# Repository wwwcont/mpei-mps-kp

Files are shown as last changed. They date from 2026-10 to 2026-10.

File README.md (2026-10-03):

# Результаты генератора

Ветка обновляется автоматически (джобы КМ-1/2/3). Руками не править. Исходники — ветка `main`.

Папка студента — `<группа>/<M> <Фамилия И.О.>/`: `СХЕМА-N` (КМ-1), `ПЗ1-K по СХЕМА-N` (КМ-2),
`ПЗ2-K по СХЕМА-N` (КМ-3: ПЗ2 и программы). Прошлые прогоны не перетираются. В таблице — последние.
Пробы вариантов (не сдача) — в `_пробы/`.

| Группа | Вариант, студент | КМ-1: схема | Перечень | ERC | КМ-2: ПЗ1 | КМ-3: ПЗ2 | КМ-3: программы |
| --- | --- | --- | --- | --- | --- | --- | --- |
| А-09-23 | 3 Друговская Е.М. | [СХЕМА-1](А-09-23/3%20Друговская%20Е.М./СХЕМА-1): [PNG](А-09-23/3%20Друговская%20Е.М./СХЕМА-1/schematic.png) · [PDF](А-09-23/3%20Друговская%20Е.М./СХЕМА-1/schematic.pdf) · [KiCad](А-09-23/3%20Друговская%20Е.М./СХЕМА-1/schematic.kicad_sch) | [ПЭ3](А-09-23/3%20Друговская%20Е.М./СХЕМА-1/perechen.pdf) · [КМ-1](А-09-23/3%20Друговская%20Е.М./СХЕМА-1/perechen-km1.pdf) | чисто | — | — | — |
| А-12-23 | 8 Казарин А.А. | [СХЕМА-1](А-12-23/8%20Казарин%20А.А./СХЕМА-1): [PNG](А-12-23/8%20Казарин%20А.А./СХЕМА-1/schematic.png) · [PDF](А-12-23/8%20Казарин%20А.А./СХЕМА-1/schematic.pdf) · [KiCad](А-12-23/8%20Казарин%20А.А./СХЕМА-1/schematic.kicad_sch) | [ПЭ3](А-12-23/8%20Казарин%20А.А./СХЕМА-1/perechen.pdf) · [КМ-1](А-12-23/8%20Казарин%20А.А./СХЕМА-1/perechen-km1.pdf) | чисто | [ПЗ1-2 по СХЕМА-1](А-12-23/8%20Казарин%20А.А./ПЗ1-2%20по%20СХЕМА-1/Казарин%20АА%20ПЗ1-v1.docx) | [ПЗ2-1 по СХЕМА-1](А-12-23/8%20Казарин%20А.А./ПЗ2-1%20по%20СХЕМА-1/Казарин%20АА%20ПЗ2-v1.docx) | [отчёт](А-12-23/8%20Казарин%20А.А./ПЗ2-1%20по%20СХЕМА-1/программы/report.md) |
| А-12-23 | 14 Студентов С.С. | [СХЕМА-1](А-12-23/14%20Студентов%20С.С./СХЕМА-1): [PNG](А-12-23/14%20Студентов%20С.С./СХЕМА-1/schematic.png) · [PDF](А-12-23/14%20Студентов%20С.С./СХЕМА-1/schematic.pdf) · [KiCad](А-12-23/14%20Студентов%20С.С./СХЕМА-1/schematic.kicad_sch) | [ПЭ3](А-12-23/14%20Студентов%20С.С./СХЕМА-1/perechen.pdf) · [КМ-1](А-12-23/14%20Студентов%20С.С./СХЕМА-1/perechen-km1.pdf) | чисто | — | — | — |
| А-12-23 | 17 Рязанцев И.В. | [СХЕМА-1](А-12-23/17%20Рязанцев%20И.В./СХЕМА-1): [PNG](А-12-23/17%20Рязанцев%20И.В./СХЕМА-1/schematic.png) · [PDF](А-12-23/17%20Рязанцев%20И.В./СХЕМА-1/schematic.pdf) · [KiCad](А-12-23/17%20Рязанцев%20И.В./СХЕМА-1/schematic.kicad_sch) | [ПЭ3](А-12-23/17%20Рязанцев%20И.В./СХЕМА-1/perechen.pdf) · [КМ-1](А-12-23/17%20Рязанцев%20И.В./СХЕМА-1/perechen-km1.pdf) | чисто | [ПЗ1-1 по СХЕМА-1](А-12-23/17%20Рязанцев%20И.В./ПЗ1-1%20по%20СХЕМА-1/Рязанцев%20ИВ%20ПЗ1-v1.docx) | [ПЗ2-1 по СХЕМА-1](А-12-23/17%20Рязанцев%20И.В./ПЗ2-1%20по%20СХЕМА-1/Рязанцев%20ИВ%20ПЗ2-v1.docx) | [отчёт](А-12-23/17%20Рязанцев%20И.В./ПЗ2-1%20по%20СХЕМА-1/программы/report.md) |

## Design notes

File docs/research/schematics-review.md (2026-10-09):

# Разбор схем Э3 прошлых лет и решения для мастера

> **ТЗ-2026:** CS теперь через дешифратор 74HC138, фильтры 33 н, у IDT7005 A0–A12, индикатор по группе — см. `tz-2026.md`. Остальное в силе.

Собрано 2026-09-30 из `docs/prev/` (локально) + `docs/group/` + даташитов. Сводка трёх разборов:
схемы по узлам, KiCad-библиотеки, даташиты IDT7005 / AT89S53 / FYS-5612.

## Кто что рисовал

- **Шаблон 2025 (наше ТЗ)**: Осипова вар. 12 (ПРИНЯТО 28.10.25, `mailru-group/Защита/`), Аристов вар. 1, Иванова вар. 7,
  ММС вар. 11, старая схема Ивана вар. 14 (принята без замечаний). Одна топология.
- **Прошлые годы** (другое ТЗ: АЦП/SPI, UART, LED, 2 разряда, 16 клавиш, внешнее устройство буфер ЧИТАЕТ):
  Сорокина, Женюх, Козлова, Базарнов (= Хромочкина), Балашов/Кретов, Гайворонский, Сапрыкин, Егоров. Мерсов, Рыженков — совсем другое.

## Решения по узлам

| Узел | Решение | Почему |
|---|---|---|
| RST | C 10 мкФ VCC→RST, R 10 кОм RST→GND (τ≈100 мс), кнопка — опционально через 100–220 Ом | В шаблоне 2025 только R на GND → нет POR. Классика у Ивановой, Базарнова |
| Кварц | ZQ1 12 МГц, C 30 пФ ×2, примечание «вблизи ZQ1» | даташит |
| EA/PSEN | EA→VCC, PSEN — NC | Балашов/Гайворонский: EA висит — грубо |
| Защёлка | 74AC573 (или КР1554ИР22 = 74AC373 — **другая цоколёвка**, см. `variants-gost-parts.md`), OE→GND, LE=ALE | 74AS/LS/ИР82 — ТТЛ |
| Load 573 (Y2, индикатор) | ИЛИ-НЕ(CS, WR) — 74HC02 / 1554ЛЕ1: 2,3→1; 5,6→4; 8,9→10; 11,12→13 | у Ивана и Аристова верно; у Осиповой нарисован NOR, а выводы/ПЭ от ЛА3 |
| OE 244 | ИЛИ(CS_KB, RD) — 74HC32 / 1554ЛЛ1 | у Ивана это ИЛИ (DD9.1) |
| Cp 173 | у Ивана NOR(CS_KB, WR) → Cp, E1/E2 — GND | работает; альтернатива Cp←WR, E←CS |
| IDT7005 | **с 09.10.2026 (changelog /27, замечания Михалина «включение буфера не соотв. варианту и не верно по сути»):** левый порт — МК целиком (A0–A12, D0–D7, CEL ← CS_buf, OEL ← RD, R/WL ← WR); правый — разъём доступа к буферу целиком (A0R–A12R, I/O0R–I/O7R, R/WR ← строб X2 → INT1, CER → GND, OER → +5 В). Отменены: «почтовый ящик» (/27 30.09: адрес на +5 В — нет адреса на разъёме) и вариант методички Прил. А (/23 06.10: правый порт пишет WR МК — нет независимого доступа, левый не пишет, а для нечётных M программа 2 — запись). TQFP-64 (S55PF), M/S=GND, BUSY→VCC, SEM→VCC, INT — NC | ТЗ-2026 разд. 2.1 п. 6, п. 9; табл. 1 (прог. 2) |
| Клавиатура | 173 → КД521А катодом к Col → строки: подтяжка 2 кОм к VCC + 10 кОм + C 220 нФ (3RC ≥ 5 мс) → 244 и «И» → INT | топология Ивана/Осиповой. Последовательный R обязателен |
| «И» строк | 3 строки: ЛИ3/74HC11 (1,2,13→12); 4 строки: ЛИ6/74HC21 (1,2,4,5→6) | у Осиповой ЛИ3 со входами разных вентилей → INT всегда 0 |
| Индикатор | 573 → 8×330 Ом → FYS-5612AX (ОК, CC 3,8 → GND) / BX (ОА, 3,8 → VCC). A7 B6 C4 D2 E1 F9 G10 DP5. Обозначение HG1 | у Осиповой и во временном мастере цоколёвка неверная; у Ивана верно, но DA1 |
| Разъёмы | XS1 X2: X2stb, X2_0..7, GND; XS2 Y: Y1stb, Y2stb, Y2_0..7, GND; XS3: VCC, GND. Таблица «Сигнал/Вывод» | как у Ивана |
| Питание | 470 мкФ ×1 на входе + 68 нФ на КАЖДЫЙ корпус DD; примечание «вблизи выводов питания» | ТЗ п.10; у Ивана 68p |
| Логика | только КМОП: 74HC/74AC/1554/1564 | ТЗ |

## Временный мастер (masters/kb4x3-cathode.kicad_sch) — найденные дефекты

- HG1 = символ HDSP-7403: ни один сегмент не на своём выводе FYS-5612.
- Клавиатура: SB1–SB12 обоими выводами + R2–R7 + аноды VD в одной цепи — замкнута.
- IDT7006PF: номера TQFP-64 совпадают с 7005 (A13 удалён) — неверны только имя/описание.
- Не подключены A0/A1/A5/A6 обоих портов, A8L, A10L, BUSY, INT; EA/PSEN висят; нет номиналов.
Вывод: не латать, а строить заново.

## IDT7005 TQFP-64 (PF64)

VCC 8, 13, 57; GND 5, 9, 24, 41; N/C 23, 58.
Левый: CEL 59, OEL 62, R/WL 61, SEML 60, INTL 43, BUSYL 42, M/S 40; A0L–A12L = 44–56; I/O0L 63, I/O1L 64, I/O2L–I/O5L 1–4, I/O6L 6, I/O7L 7.
Правый: CER 22, OER 19, R/WR 20, SEMR 21, INTR 38, BUSYR 39; A0R–A12R = 37–25; I/O0R–I/O2R 10–12, I/O3R–I/O7R 14–18.

## Времена (для ПЗ1)

- IDT7005 S55 (`docs/group/idt7005 [en].pdf`, столбец IDT7005X55: чтение с. 8, запись с. 9; сверено 01.10.2026): tRC=tAA=tACE 55, tAOE 30, tWC 55, tWP 40, tAS 0, tDW 30, tDH 0, tEW/tAW 45; tAPS 5; tWDD 80, tDDD 65 нс. S70 — только military.
- AT89S53 @12 МГц: tLHLL≥127, tAVLL≥43, tLLAX≥48, tRLRH/tWLWH≥400, tRLDV≤252, tRHDZ≤97, tLLDV≤517, tAVDV≤585, tLLWL 200..300, tAVWL≥203, tQVWX≥23, tQVWH≥433, tWHQX≥33 нс.
- Токи AT89S53: ≤10 мА/вывод, ≤26 P0, ≤15 P1–P3, ≤71 всего.

## KiCad

- ГОСТ-библиотека (mailru-group/kicad-gost-library-master, legacy .lib): KiCad 10 читает; конвертация поштучно `kicad-cli sym upgrade X.lib -o X.kicad_sym`. 1564: только ИД7, ИЕ19, ЛА3, ТЛ2.
- Стандартная KiCad 10: AT89x51xxP, 74LS573 (= HC573 по выводам), 74HC173, 74HC244, 74HC02, 74LS08/11/21/32. IDT7005 нет → своя библиотека.
- Индикатор пин-в-пин с FYS-5612: KCSC02-105 / SM420561N (катод), KCSA02-105 (анод).

## Полезные образцы

Э3/ПЭ Осиповой (форма, штамп, примечания); старая Э3 Ивана и АИВ (стробы, цоколёвка индикатора);
ИАВ (сброс); ПЗ Козловой (расчёты); GIF Рыженкова (замечания проверяющего); «перечень по госту» Женюха (форма ПЭ).
Полный чек-лист требований и банк вопросов — `remarks-and-defense.md`.

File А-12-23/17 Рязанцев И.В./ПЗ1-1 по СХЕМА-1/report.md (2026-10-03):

# ПЗ1: Рязанцев И.В., А-12-23, вариант 17

Файл: `Рязанцев ИВ ПЗ1.docx`. Мест «ДОПИШИ»: 3, осталось заполнить: 0 (students/<ник>/pz/pz1.md).

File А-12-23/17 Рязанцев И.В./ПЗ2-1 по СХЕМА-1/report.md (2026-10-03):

# ПЗ2: Рязанцев И.В., А-12-23, вариант 17

Файл: `Рязанцев ИВ ПЗ2.docx`. Мест «ДОПИШИ»: 16, осталось заполнить: 0 (students/<ник>/pz/pz2.md).

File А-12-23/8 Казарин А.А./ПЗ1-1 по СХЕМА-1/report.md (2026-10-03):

# ПЗ1: Казарин А.А., А-12-23, вариант 8

Файл: `Казарин АА ПЗ1.docx`. Мест «ДОПИШИ»: 3, осталось заполнить: 2 (students/<ник>/pz/pz1.md).

- `p1.intro` — Введение: своими словами
- `p1.buffer` — Механизм обмена через буфер

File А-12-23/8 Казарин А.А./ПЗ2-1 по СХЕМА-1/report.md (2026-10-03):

# ПЗ2: Казарин А.А., А-12-23, вариант 8

Файл: `Казарин АА ПЗ2.docx`. Мест «ДОПИШИ»: 16, осталось заполнить: 0 (students/<ник>/pz/pz2.md).

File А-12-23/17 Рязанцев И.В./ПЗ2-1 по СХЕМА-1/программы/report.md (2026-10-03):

# Проверка программ: Рязанцев И.В., А-12-23, вариант 17

Проверено mpscode: сборка (asm51, байты сверяются с MCU 8051 IDE), правила робота (ТЗ-2026, разд. 2.2, рис. 7), сценарии во встроенном эмуляторе 8051 (emu51, сверен с ucsim s51) с моделями устройств схемы. Робот МЭИ может проверять иначе — «✅» здесь не гарантия «принято», но «❌» почти наверняка ошибка.

## ✅ Программа 1 — обработчик INT0: сканирование клавиатуры, код клавиши в A или 0FFh

Файл для робота: `Рязанцев ИВ-код-1.txt`

| | Проверка | Результат |
| --- | --- | --- |
| ✅ | Первая строка | ; Рязанцев И.В., А-12-23, 17, v1 |
| ✅ | Комментарии | не длиннее 250 символов |
| ✅ | Сборка | 158 байт кода |
| ✅ | Файл для робота | vars.inc вклеен, код тот же |
| ✅ | %proc% | строка 8, адрес 0003h |
| ✅ | %stop% | строка 34, адрес 003Dh |
| ✅ | Заглушки IRQ | на всех векторах есть код |
| ✅ | Описание процедуры | перед KbScan — 4 строк комментария |
| ✅ | Инициализация | дошли до %stop% |
| ✅ | Коды клавиш | все 12 клавиш, две клавиши и помеха — верно; от нажатия до возврата ≤ 215 мкс |
| ✅ | CS_EN | все обращения к устройствам — при P3.4 = 1 |

## ✅ Программа 2 — запись в кольцевой буфер (данные в A), флаги пустоты и переполнения

Файл для робота: `Рязанцев ИВ-код-2.txt`

| | Проверка | Результат |
| --- | --- | --- |
| ✅ | Первая строка | ; Рязанцев И.В., А-12-23, 17, v1 |
| ✅ | Комментарии | не длиннее 250 символов |
| ✅ | Сборка | 126 байт кода |
| ✅ | Файл для робота | vars.inc вклеен, код тот же |
| ✅ | %proc% | строка 34, адрес 0042h |
| ✅ | %stop% | строка 35, адрес 0045h |
| ✅ | Заглушки IRQ | на всех векторах есть код |
| ✅ | Описание процедуры | перед BufWrite — 5 строк комментария |
| ✅ | Инициализация | буфер пуст: голова A000h, хвост A000h, F_EMPTY=1, F_OVF=0 |
| ✅ | Запись | 6 сценариев (пусто, заворот, переполнение) — верно; политика буфера: V (голова = хвост при F_EMPTY = 0 — буфер полон) |
| ✅ | CS_EN | все обращения к устройствам — при P3.4 = 1 |

## ✅ Программа 3 — Y2 = (G+M+X1+X2) mod 256 при X1≠0, иначе 0; запись в регистр, строб T2 на P1.4 (Timer1)

Файл для робота: `Рязанцев ИВ-код-3.txt`

| | Проверка | Результат |
| --- | --- | --- |
| ✅ | Первая строка | ; Рязанцев И.В., А-12-23, 17, v1 |
| ✅ | Комментарии | не длиннее 250 символов |
| ✅ | Сборка | 88 байт кода |
| ✅ | Файл для робота | vars.inc вклеен, код тот же |
| ✅ | %proc% | строка 37, адрес 0044h |
| ✅ | %stop% | строка 38, адрес 0047h |
| ✅ | Заглушки IRQ | на всех векторах есть код |
| ✅ | Описание процедуры | перед Y2Out — 4 строк комментария |
| ✅ | Y2 и строб | 6 сценариев: значение, X1 = 0 → 0, строб T2 = 2422 мкс (отклонение ≤ 5 мкс, допуск 24) |
| ✅ | CS_EN | все обращения к устройствам — при P3.4 = 1 |

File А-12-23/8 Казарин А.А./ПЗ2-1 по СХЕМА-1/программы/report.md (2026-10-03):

# Проверка программ: Казарин А.А., А-12-23, вариант 8

Проверено mpscode: сборка (asm51, байты сверяются с MCU 8051 IDE), правила робота (ТЗ-2026, разд. 2.2, рис. 7), сценарии во встроенном эмуляторе 8051 (emu51, сверен с ucsim s51) с моделями устройств схемы. Робот МЭИ может проверять иначе — «✅» здесь не гарантия «принято», но «❌» почти наверняка ошибка.

## ✅ Программа 1 — обработчик INT0: сканирование клавиатуры, код клавиши в A или 0FFh

Файл для робота: `Казарин АА-код-1.txt`

| | Проверка | Результат |
| --- | --- | --- |
| ✅ | Первая строка | ; Казарин А.А., А-12-23, 8, v1 |
| ✅ | Комментарии | не длиннее 250 символов |
| ✅ | Сборка | 172 байт кода |
| ✅ | Файл для робота | vars.inc вклеен, код тот же |
| ✅ | %proc% | строка 12, адрес 0003h |
| ✅ | %stop% | строка 37, адрес 003Bh |
| ✅ | Заглушки IRQ | на всех векторах есть код |
| ✅ | Описание процедуры | перед KbScan — 3 строк комментария |
| ✅ | Инициализация | дошли до %stop% |
| ✅ | Коды клавиш | все 12 клавиш, две клавиши и помеха — верно; от нажатия до возврата ≤ 177 мкс |
| ✅ | CS_EN | все обращения к устройствам — при P3.4 = 1 |

## ✅ Программа 2 — чтение из кольцевого буфера (данные в A), флаги пустоты и переполнения

Файл для робота: `Казарин АА-код-2.txt`

| | Проверка | Результат |
| --- | --- | --- |
| ✅ | Первая строка | ; Казарин А.А., А-12-23, 8, v1 |
| ✅ | Комментарии | не длиннее 250 символов |
| ✅ | Сборка | 106 байт кода |
| ✅ | Файл для робота | vars.inc вклеен, код тот же |
| ✅ | %proc% | строка 35, адрес 0044h |
| ✅ | %stop% | строка 36, адрес 0047h |
| ✅ | Заглушки IRQ | на всех векторах есть код |
| ✅ | Описание процедуры | перед BufRead — 3 строк комментария |
| ✅ | Инициализация | буфер пуст: голова A000h, хвост A000h, F_EMPTY=1, F_OVF=0 |
| ✅ | Чтение | 6 сценариев (пусто, заворот, переполнение) — верно |
| ✅ | CS_EN | все обращения к устройствам — при P3.4 = 1 |

## ✅ Программа 3 — Y2 = (G+M+X1+X2) mod 256 при X1≠0, иначе 0; запись в регистр, строб T2 на P1.2 (Timer1)

Файл для робота: `Казарин АА-код-3.txt`

| | Проверка | Результат |
| --- | --- | --- |
| ✅ | Первая строка | ; Казарин А.А., А-12-23, 8, v1 |
| ✅ | Комментарии | не длиннее 250 символов |
| ✅ | Сборка | 70 байт кода |
| ✅ | Файл для робота | vars.inc вклеен, код тот же |
| ✅ | %proc% | строка 36, адрес 0041h |
| ✅ | %stop% | строка 37, адрес 0044h |
| ✅ | Заглушки IRQ | на всех векторах есть код |
| ✅ | Описание процедуры | перед Y2Out — 3 строк комментария |
| ✅ | Y2 и строб | 6 сценариев: значение, X1 = 0 → 0, строб T2 = 2152 мкс (отклонение ≤ 5 мкс, допуск 22) |
| ✅ | CS_EN | все обращения к устройствам — при P3.4 = 1 |

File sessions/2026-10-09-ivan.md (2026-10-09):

# 2026-10-09 — ivan: вторые замечания к КМ-1 (Михалин, Гольцов)

- Пришли замечания: Михалин — Рязанцеву (нумерация, пересечения УГО, подключения к шине, «+5V» вниз, буфер «не соотв. ТЗ и не верно
  по сути»), Гольцов — Лапташкину (перечень, ГОСТ-УГО, шины, номиналы на листе, DD6 американский, сброс, кнопки, надписи на линиях).
  Дословно — `students/a12_ryazantsev_iv/remarks.md`, `students/a08_laptashkin_vi/remarks.md`.
- Разбор «почему так вышло» и всё, что поменяли, — changelog `2026-10-09/27`. Главное:
  буфер — правый порт IDT целиком на отдельном разъёме (адрес, данные, строб → R/WR и INT1), левый — МК (читает и пишет);
  шины — номер линии у входа, имя на проводнике, входы с двух сторон не напротив; УГО и перечень доведены до ГОСТ.
- Самопроверка — 3 круга сабагентом «глазами преподавателя» по 4 листам (Рязанцев, Лапташкин, Грошев, Судбинин) + `go test ./...`
  (TestNetlist+ERC, TestNoOverlaps, TestNumberingClear); ERC пустой.
- Issues ничьи не перезапускали (по просьбе Ивана). Тексты ПЗ1 других студентов (Лапташкин, Казарин, Давыдова, Грошев, Судбинин)
  описывают старое включение буфера — им пересобрать КМ-1 → КМ-2 и переписать `p1.buffer`.
- Ответ руководителю без изменений: выводы дешифратора — по табл. 1 и рис. 6 ТЗ; 173 и 573 — разные регистры по списку марок ТЗ;
  индикация — по ТЗ только 7-сегментный индикатор; цвет — только в экспорте из KiCad, PNG/PDF генератора чёрно-белые.
- Год набора Ивана — 23 (А-12-23, подтвердил 09.10). После пуша — перезапуск КМ-1→КМ-2→КМ-3 у всех студентов.
- Перезапуск всех (по просьбе Ивана): КМ-1 с next у 7 студентов → тексты ПЗ1/ПЗ2 и схемы 05a/05 переписаны каждому под новый буфер
  (сабагенты, своими словами), Друговской написаны программы КМ-3 (все ✅). Итог в Issues — сообщение «пересобрана по обновлённому
  генератору»; старые карточки, «📥/⏳» и команды `/км…` свёрнуты как outdated (не удалены).
- Нашли гонку: 7 КМ-1 одновременно пушили в results, у Судьбинина 3 попытки проиграли, а запуск не упал (карточка ушла, СХЕМА-2 на
  диске есть, в results нет → КМ-2/КМ-3 взяли СХЕМА-1). `scripts/publish.sh`: 12 повторов со случайной паузой, иначе ошибка.

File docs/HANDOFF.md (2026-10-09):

# Передача контекста: курсовая МПС ч.2 + генератор

> **История (на 30.09.2026, до переноса в GitHub).** Актуальные правила — `AGENTS.md`, решения по схеме —
> `docs/research/schematics-review.md`, статус — `README.md`. Отсюда устарело: мастер-схемы и патчер
> (заменены построителем `internal/schgen`), KiCad 9 (теперь 10), «репо держать приватным».

Документ собран из длинной сессии в claude.ai. Здесь всё, что известно на 30.09.2026:
что за курсовая, что уже сделано, какие ошибки найдены, как устроен генератор, что дальше.

## 1. Ситуация

- Курсовая «Разработка микропроцессорной системы на базе МК i8051» (МПС ч.2), НИУ МЭИ, ИВТИ, кафедра ВМСС.
  Руководитель — Михалин С.Н. Группа А-12-22.
- Имеющиеся материалы (`docs/source/`: схема Э3, спецификация, ПЗ1 v1) — **прошлогодние**.
  Курсовую Иван делает заново, **вариант придёт новый** (номер M пока неизвестен).
  Всё, что считалось для «варианта 14» (А-12, M=14), — это эталон для проверки генератора, а не финальные данные.
- Цель шире одной курсовой: сделать общую базу для группы — генератор (параметры, схема KiCad,
  дальше ПЗ и асм-заготовки) + рыба + общие заметки, куда пишут люди и Claude-сессии.

## 2. Что сдаётся (по ТЗ, `docs/source/ТЗ-2025.pdf`)

| КМ | Что | Файл / тема письма |
| --- | --- | --- |
| КМ-1 | Схема Э3 на А3 + перечень микросхем и разъёмов | «Фамилия ИО Схема-v1.png», тема «МПС-Схема» |
| КМ-2 | ПЗ1 — аппаратная часть (титул — Прил. А ТЗ) | «Фамилия ИО ПЗ1-v1.pdf», «МПС-ПЗ1» |
| КМ-3 | ПЗ2 — программная часть (шаблон `docs/source/шаблон-ПЗ2-ПрилБ.docx`) + 3 программы | «Фамилия ИО ПЗ2-v1.pdf» («МПС-ПЗ2»), «Фамилия ИО-код-n.txt» UTF-8 («МПС-код») |
| КМ-4 | Тест + беседа на защите | — |

Минимум для КМ-3 — первая программа (клавиатура). Программы проверяет робот: заглушки `nop`/`reti`
на всех векторах, `call Proc ; %proc%`, `jmp $ ; %stop%`, комментарии ≤ 250 символов, метки ≤ 60.
JPG нельзя (формат с потерями).

## 3. Предметная часть — как устроено устройство

AT89S53 (8051) на 12 МГц. Внешняя шина: P0 (адрес/данные, защёлка 573 по ALE), P2 (старший адрес + CS),
P3.6/P3.7 = WR/RD. Четыре устройства на шине, у каждого свой CS на одной из P2.3–P2.7 (активный 0):

- **Индикатор** — регистр 573 + 8 резисторов + FYS-5612AX (общий катод) / BX (общий анод). Статическая индикация.
- **Клавиатура** 12 клавиш — 173 пишет столбцы (Col) с шины, 244 отдаёт строки (Row) на шину;
  RC-фильтры и подтяжки на строках, диоды в столбцах, «И» по строкам → INT (по спаду).
  Сканирование «бегущим нулём» по столбцам. M чётное → 4×3, нечётное → 3×4.
- **Кольцевой буфер** — двухпортовое ОЗУ IDT7005: левый порт — МК (movx), правый — внешнее устройство (X2).
  Механизм (с 09.10.2026, changelog /27, по замечаниям Михалина): правый порт целиком на отдельном разъёме — внешнее устройство
  пишет X2 само (адрес, данные, строб → R/WR и INT1) в ячейку обмена `BUF_X2IN`; обработчик INT1 читает её левым портом и кладёт
  отсчёт в кольцо (R/WL ← WR). Указатели и флаги — МК.
- **Регистр Y2** — 573, Load = ИЛИ-НЕ(CS_Y2, WR). Стробы Y1/Y2 — прямо с ножек P1.
- Y2 = (M + X1 + X2) mod 256, пока X1 ≠ 0 и в буфере есть данные; иначе Y2 = 0.

Адреса: буфер ≤ 2048 байт → A0–A10 (P0 + P2.0–P2.2); старший байт адреса устройства = F8h со сброшенным
битом его CS (P2.7 → 7800h, P2.6 → 0B800h, P2.5 → 0D800h, P2.4 → 0E800h, P2.3 → 0F000h).

**Чем варианты отличаются по железу** (важно для генератора): только (1) какие P2.x на каких CS,
(2) какой INT у клавиатуры, (3) биты P1 под стробы, (4) клавиатура 4×3/3×4, (5) индикатор катод/анод.
Размер буфера разводку не меняет. Остальное — программная часть.

«Общую часть» схемы никто не выдаёт — её каждый рисует сам; на деле в группе ходит один шаблон
из года в год (схемы Ивана, ММС, АИВ — один шаблон с одними ошибками).

## 4. Найденные проблемы (важно не повторить в новой работе)

В старой схеме/ПЗ1 Ивана:
1. **Сброс**: на RST только 10 кОм на GND, нет конденсатора от +5 В — сброс при включении не гарантирован
   (правильно сделано у ИАВ: кнопка + RC).
2. **Фильтрующие конденсаторы 68 пФ** на схеме и в перечне — по ТЗ 68 **нФ**.
3. **Логика ТТЛ** (7402, 74AS21, 74AS32, 74AS573) — ТЗ просит КМОП (1554/1564/74HC/74AC).
4. Опечатки в ПЗ1: для длительности RD продублирован t_AVLL (должен быть t_RLRH) (R/WL на диаграмме записи теперь верно: МК пишет левым портом).
5. В ПЗ1 не хватает: оценки мощности, описания механизма доступа внешнего устройства к буферу,
   временной диаграммы обмена МК ↔ IDT7005 (п. 2.1 и 2.3 ТЗ).
6. Проверить арбитраж BUSY IDT7005: при записи через INT оба порта обращаются к одному адресу одновременно
   (левый — в режиме чтения). В режиме master запись на проигравшем порту может блокироваться.

В схемах одногруппников:
- ИАВ и Осипова ставят символ **IDT7006PF** и переименовывают в IDT7005 — номера выводов не от 7005.
- У АИВ и ИАВ не проставлены номиналы R/C.

## 5. Генератор — состояние

Всё в этом репо, см. `README.md` и `CLAUDE.md`. Сделано и проверено:
- калькулятор варианта (все группы × M = 1..30 без ошибок; эталон А-12 M=14 совпал с ручным расчётом);
- патчер схемы: 8 меток (4 CS, Y1/Y2, 2 INT) переезжают на нужные выводы; прогон 4 разных вариантов через
  `kicad-cli` — ERC идентичен мастеру; полный лист с ГОСТ-рамкой рендерится;
- рамка: вариант вписывается автоматически; многострочные надписи разбиты на строки (kicad-cli рисовал их внахлёст);
- CI на GitHub Actions (артефакты хранятся 7 дней — иначе кончится квота 500 МБ на бесплатном аккаунте).

Временный мастер `masters/kb4x3-cathode.kicad_sch` — схема Осиповой (А-12, вар. 12) из папки группы.
Минусы: IDT7006PF, нет конденсатора сброса, не везде номиналы, рамка без боковых граф.
Репо поэтому держать **приватным**.

Шрифт `GOST type A` в репо не лежит (лицензия ASCON, freeware — лучше не распространять).
Брали отсюда: `https://raw.githubusercontent.com/koson/PowerSupply/master/Template/GOST%20type%20A.ttf`
→ положить в `fonts/` (CI подхватит) и поставить локально.

## 6. План (по приоритету)

1. **Исправленный мастер 4×3**: взять хорошее из старой схемы Ивана (номиналы, правильные выводы 7005,
   рамка с боковыми графами) + логика 1564 + конденсатор сброса + все вариантные связи МК на метках
   (требования к мастеру — README). Исходника `.kicad_sch` старой схемы Ивана пока нет — спросить.
2. **Мастер 3×4** (нечётные M) — нарисовать один раз (в папке группы есть только картинки).
3. Катод/анод — сделать подменой метки/номинала в том же мастере, а не отдельным мастером.
4. Шаблоны ПЗ1/ПЗ2 в markdown → docx через pandoc (`reference.docx`: поля 2/2/2.5/1 см, Times New Roman 12, одинарный).
5. Асм-заготовки трёх программ с `include vars.inc`, проверка в симуляторе.
6. Когда придёт новый вариант Ивана — `students/a12_ryazantsev_iv/variant.yaml`, собрать, доделать руками.
7. (Опционально) свой MCP-сервер на Go поверх репо — общая память для Claude-сессий группы, в т.ч. с телефона.

## 7. Открытые вопросы

- Новый номер варианта Ивана — неизвестен.
- Тип индикатора (катод/анод) для групп кроме А-12 — в табл. 1 ТЗ два значения на пять групп, соответствие неясно.
- Будет ли ТЗ 2026 с другой таблицей — тогда `data/table-2026.yaml`.

## 8. Материалы

- `docs/source/` — ТЗ 2025, методичка, шаблон ПЗ2 (Прил. Б), старые ПЗ1/схема/спецификация Ивана.
- `docs/group/` — даташиты (AT89S53 рус., FYS-5612, КД521А, 1554ЛИ3, конденсаторы) и три схемы одногруппников.
- Папка группы (mail.ru облако, публичная ссылка):
  `https://cloud.mail.ru/public/TeV3/qEfCeiDza/7%20%D0%A1%D0%95%D0%9C%D0%95%D0%A1%D0%A2%D0%A0/%D0%9A%D0%9F%20%D0%BF%D0%BE%20%D0%BC%D0%B8%D0%BA%D1%80%D0%BE%D0%BF%D1%80%D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`
  Там: `kicad-gost-library-master` (ГОСТ-символы KiCad), `gost_ramka.kicad_wks`, `GOSTy_MS_Visio`
  (трафарет для блок-схем ПЗ2), `Документация` (даташиты), `Защита`, `КМ4 Тест`, ПЗ1/ПЗ2 Осиповой,
  PDF с кодами подпрограмм, шаблон перечня элементов.
  Скачивание через API: `https://cloud.mail.ru/api/v4/public/list?weblink=<путь>` + сервер из
  `https://cloud.mail.ru/api/v2/dispatcher` (`weblink_get`). Облако режет частые запросы — качать с паузами 10–15 с.
- Рыба курсовой (пошаговый гайд, 8 шагов, справочник) — Claude Doc «МПС ч.2 — универсальная рыба курсовой (i8051)».
  Если есть экспорт — положить в `docs/riba.md`.

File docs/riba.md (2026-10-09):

# МПС ч.2 — универсальная рыба курсовой (i8051, ТЗ-2026)

> Числа варианта, схему Э3, перечень, файлы для робота и ПЗ2 выдаёт генератор: `make try G=… M=…` / `make student S=…`,
> `make code S=…`, `make pz2 S=…` или джобы в GitHub Actions («КМ-1 схема и перечень», «КМ-3 программы и ПЗ2», см. README).
> Эта рыба — чтобы понимать, **что** в схеме и программах и **почему**: это спрашивают на защите. Числа в примерах — для
> А-12, M = 14 (эталон тестов генератора); свои бери из `params.md` и `vars.inc`, в уме не считай.
> Отличия от прошлогоднего задания — `docs/research/tz-2026.md`.

Начинай с раздела «Пошагово с нуля»: там весь путь от «ничего не понятно» до защиты. Всё, что после него, — справочник.

# Пошагово с нуля

## Устройство на пальцах

Ты проектируешь маленький пульт: человек жмёт цифру, внешняя железка присылает числа, пульт их складывает и отдаёт результат наружу.

Термины, без которых дальше не прочитать:

- **МК AT89S53** — микроконтроллер семейства 8051: процессор, 256 байт ОЗУ, память программ, таймеры, 2 внешних прерывания, 4 порта по 8 ножек.
- **Шина** — общие провода, по которым МК обращается к внешним микросхемам: P0 (младший байт адреса, затем данные), P2 (старший байт адреса), P3.6 = WR, P3.7 = RD, ALE.
- **Адрес** — 16-битное число, которое МК выставляет на шину командой `movx`. Старшие три бита адреса (A15…A13) выбирают устройство.
- **Дешифратор 74HC138** — превращает три бита A15…A13 в один из восьми сигналов Y0…Y7 (активен нулём). Каждый выход — **CS** (Chip Select) своего устройства; номер выхода задан в табл. 1 ТЗ. Дешифратор работает, только пока **CS_EN = P3.4 = 1** (вход E2).
- **RD / WR** — стробы чтения/записи МК. `movx A,@DPTR` даёт импульс RD, `movx @DPTR,A` — импульс WR.
- **Регистр-защёлка (573)** — 8 триггеров: запоминает байт с шины и держит его на выходах, пока не запишут новый.
- **Регистр 173** — то же, но 4 бита; держит состояние столбцов клавиатуры.
- **Буфер с тремя состояниями (244)** — выдаёт свои входы на шину только когда его выбрали, в остальное время его выходы отключены.
- **Двухпортовое ОЗУ IDT7005** — память 8 Кбайт с двумя независимыми наборами адреса/данных/управления: левый порт целиком у МК (читает и пишет), правый целиком у внешнего устройства на отдельном разъёме: адрес, данные и строб записи — оно пишет отсчёт X2 само, независимо от МК.
- **Прерывание INT0/INT1** — спад на ножке P3.2/P3.3 заставляет МК выполнить обработчик по фиксированному адресу (03h / 13h).
- **Таймер** — 16-битный счётчик машинных циклов (1 мкс при 12 МГц); при переполнении вызывает прерывание (0Bh / 1Bh).

Что подключено к МК:

| Устройство | Зачем | Как с ним говорят |
| --- | --- | --- |
| Клавиатура 12 кнопок | человек вводит цифру X1, «Тест», «Сброс» | пишем столбцы в регистр, читаем строки через повторитель; нажатие → INT0 |
| Индикатор, 1 цифра | показать нажатую цифру или ошибку | пишем код сегментов в регистр |
| Кольцевой буфер (IDT7005) | копить числа X2 от внешнего устройства | оно пишет в свой порт и дёргает INT1; МК читает по одному |
| Регистр Y2 | выдать результат наружу | пишем Y2, дёргаем строб на P1 |
| Ножка Y1 на P1 | строб по кнопке «Тест» | 0 на время T1, потом 1 |

Весь смысл работы в одну строку: **Y2 = (G + M + X1 + X2) mod 256**, пока X1 ≠ 0 и в буфере есть X2 (G — номер группы: 6, 7, 8, 9, 12, 17, 21).

## Шаг 1. Получить свой вариант (5 минут)

`make try G=А-12 M=14 FIO="Фамилия И.О."` (или Actions → «КМ-1 схема и перечень» → Run workflow) → `params.md`. Там всё, что раньше
считали руками. Разбери его строчка за строчкой — на защите спросят, откуда каждое число:

| # | Что | Откуда (ТЗ-2026) | Пример А-12, M = 14 |
| --- | --- | --- | --- |
| 1.1 | Группа и номер M | БАРС | А-12, M = 14 |
| 1.2 | k = M mod 7; строб Y1 — P1.k, Y2 — P1.(k+1) | табл. 1 | k = 0: P1.0 и P1.1 |
| 1.3 | T1, V, T2, T3 по формулам группы | табл. 1 | 331 мс, 1744 байт, 2332 мкс, 3,040 с |
| 1.4 | Таймеры: T1 и T3 — Timer0, T2 — Timer1 (у всех) | с. 5 | — |
| 1.5 | Номера выходов дешифратора: буфер, регистр Y2 и индикатор (по чётности M), клавиатура | табл. 1 | Y5, Y6, Y7, Y1 |
| 1.6 | Прерывания: клавиатура — INT0, X2 — INT1 (у всех) | с. 5 | — |
| 1.7 | «Голова»/«хвост» и биты флагов (пустота — M, переполнение — M + G) | табл. 1 | 47h/49h; биты 14 и 26 |
| 1.8 | Чётность M → клавиатура и программа 2 | табл. 1 | чётное: 4×3, чтение буфера |
| 1.9 | M mod 3 → программа 3 | табл. 1 | 2 → Y2 со стробом |
| 1.10 | Индикатор: ОК у А-06, А-07, А-17, Аэ-21; ОА у А-08, А-09, А-12 | табл. 1 | общий анод, FYS-5612BX |

Проверка себя: четыре разных выхода дешифратора; адрес каждого устройства = номер выхода × 2000h.

## Шаг 2. Раздать ресурсы МК (30 минут)

Таблица «ножка/таймер/адрес → кому» — это и раздел функциональной схемы в ПЗ1, и раздел 3.2 в ПЗ2 (ПЗ2 генератор заполняет сам).

1. Ножки МК:
   - P0 — младшие 8 бит адреса, потом данные (мультиплексированы, адрес защёлкивается по ALE);
   - P2.0–P2.4 — A8–A12 (буфер до 2100 байт требует 13 адресных линий A0–A12 у IDT7005);
   - P2.5–P2.7 — A13–A15 → входы A0–A2 дешифратора;
   - P3.4 — CS_EN (E2 дешифратора), Ē0 = Ē1 = GND;
   - P3.2 / P3.3 — INT0 (клавиатура) / INT1 (строб X2);
   - P3.6 / P3.7 — WR / RD; P1.k, P1.(k+1) — стробы Y1, Y2.
2. Адреса: окно устройства — n·2000h … n·2000h + 1FFFh (n — номер выхода Yn). Пример: Y5 → 0A000h–0BFFFh.
3. Карта памяти: окна по 8 Кбайт, свободные выходы дешифратора (у примера Y0, Y2, Y3, Y4) — «не используется».
4. Таймеры: Y1 и T3 — Timer0 (задачи не пересекаются: во время «Теста» индикатор погашен), Y2 — Timer1.
5. Приоритеты: ввод X2 (INT1) — высокий (ТЗ: «с максимально возможным приоритетом»), остальные — низкий.
6. Внутренняя память: «голова» и «хвост» — по заданным адресам (по 2 байта), флаги — по заданным битам, остальные переменные — от 30h.

Проверка себя: ни одна ножка, адрес или байт ОЗУ не встречается в таблице дважды.

## Шаг 3. Схема Э3 (КМ-1)

Схему строит генератор (KiCad 10, ГОСТ-УГО, заполненная рамка, ERC = 0, перечни ПЭ3) — `build/<группа>-23/<M>/schematic.png/pdf/kicad_sch`.
Твоя задача — **понимать** каждый узел: пройди по листу и для каждой микросхемы ответь, куда подключены питание, CS, RD/WR и данные.

Что должно быть на листе (проверь глазами):

1. МК, кварц 12 МГц с двумя конденсаторами, RC-сброс (10 мкФ + 10 кОм).
2. Защёлка младшего байта адреса (573) по ALE.
3. Дешифратор 74HC138: A0/A1/A2 ← A13/A14/A15, E2 ← CS_EN (P3.4), Ē0/Ē1 → GND.
4. IDT7005 (slave: M/S → GND, BUSY → +5 В): левый порт — МК (A0–A12, D0–D7, CE ← CS_buf, OE ← RD, R/W ← WR);
   правый — разъём доступа к буферу (A0R–A12R, I/O0R–I/O7R, R/W ← строб X2, CE → GND, OE → +5 В); строб X2 → INT1.
5. Регистр Y2 (573) с Load = ИЛИ-НЕ(CS, WR), выходы — на разъём Y.
6. Индикатор: регистр 573 → резисторы → FYS-5612 (ОК или ОА по группе).
7. Клавиатура: столбцы — 74HC173 (Cp ← WR, MR ← RST), кнопки с диодами, строки с подтяжкой и RC-фильтром → 74HC244 (OE = ИЛИ(CS, RD)), «И» строк → INT0.
8. Разъёмы питания, X, Y; фильтры **33 нФ на каждый корпус** + 470 мкФ на входе питания.

Сдать: «Фамилия ИО Схема-v1.png» (без потерь, не JPG) письмом «МПС-Схема» + черновик перечня (`perechen-km1.pdf`).

Проверка себя: ERC без ошибок (`erc-summary.txt` пуст), рамка — твои ФИО, группа, вариант; логика КМОП (74HC/AC, 1554).

## Шаг 4. ПЗ1 (КМ-2)

ПЗ1 — схема из шага 3, рассказанная словами, плюс расчёты (генерация ПЗ1 — в работе, пока по этому списку).

1. **Титульник** — по Приложению А ТЗ.
2. **ТЗ** — своими числами из шага 1.
3. **Структурная схема** — рисунок из ТЗ + по строчке на блок.
4. **Функциональная схема** — МК, дешифратор, буфер, пульт; таблица ресурсов из шага 2.
5. **Шина** — демультиплексирование P0 по ALE, временная диаграмма чтения/записи МК, тайминги из даташита AT89S53.
6. **Дешифратор адреса** — таблица «Yn → устройство → окно», роль CS_EN.
7. **Кварц и сброс** — номиналы по даташиту.
8. **Буфер** — как подключены оба порта и **как внешнее устройство в него пишет** (выставило X2 → строб записи → INT1 → МК двигает «голову»).
9. **Временная диаграмма МК ↔ буфер** — тайминги МК рядом со временем доступа IDT7005; вывод: ожидание не нужно.
10. **Регистр Y2** — как формируется Load, где строб.
11. **Индикатор** — расчёт резистора: R ≥ (Vcc − U\_сегм − U\_вых) / I\_сегм, ближайший из ряда E24; таблица кодов символов.
12. **Клавиатура** — схема одной кнопки, расчёт RC: 3·R·C ≥ 5 мс, ток через кнопку; таблица «столбец/строка → клавиша».
13. **Питание** — 470 мкФ и 33 нФ на каждый корпус.
14. **Карта памяти** — таблица из шага 2.
15. **Оценка мощности** — токи микросхем по даташитам + индикатор (8 сегментов) + кнопки; P = Vcc · I; требование к источнику.
16. **Литература, приложения** — даташиты, перечень элементов (`perechen.pdf`), схема А3.

Проверка себя: каждый элемент со схемы упомянут в тексте; у каждого R и C — формула → числа → номинал.

## Шаг 5. Алгоритмы (самый важный шаг)

Программа тут — набор реакций на события, а не «сверху вниз».

1. **События:**

   | Событие | Кто | Что должно случиться |
   | --- | --- | --- |
   | Нажата кнопка | INT0 | узнать какая → цифра / «Тест» / «Сброс» |
   | Пришло число X2 | INT1 | двинуть «голову», флаги |
   | Кончился строб Y2 | Timer1 | поднять ножку строба в 1 |
   | Тик Timer0 | Timer0 | досчитать: погасить индикатор или закончить Y1 |
   | Ничего не происходит | — | главный цикл: есть данные и X1 ≠ 0 → выдать Y2 |
2. **Переменные**: X1, «голова», «хвост», 2 флага буфера, счётчик тиков, режим Timer0 (индикация или Y1), флаг «идёт строб Y2».
3. **Инициализация**: начальные значения всех переменных и ножек (стробы = 1, индикатор погашен, X1 = 0, буфер пуст, CS_EN = 1).
4. **Каждое событие** — шаги словами (готовые — в «Алгоритмах подпрограмм» ниже).
5. **Столкновения**: X2 пришло, пока главный цикл читает буфер → на время чтения запрети INT1; «Тест» во время индикации → индикатор гасим, Timer0 отдаём Y1.
6. **3–4 кода ошибок** для индикатора (заготовка ниже).
7. **Схемы алгоритмов** по ГОСТ 19.701 — текстом в `students/<ник>/pz/flow/*.flow`, рисует генератор (`docs/pz-guide.md`).

Проверка себя: «X1 = 3, пришло X2 = 10» → Y2 = (G + M + 13) mod 256 со стробом (у примера — 39).

## Шаг 6. ПЗ2 (КМ-3, часть 1)

ПЗ2 собирает генератор (`make pz2-init S=<ник>` → `make pz2 S=<ник>`, гайд — `docs/pz-guide.md`): титул, разделы по шаблону Прил. Б
с числами варианта, таблица подпрограмм из комментариев твоего кода, ресурсы, коды, ответы на п. 2.3, листинги. Ты пишешь
в `students/<ник>/pz/pz2.md` только связный текст по подсказкам «ДОПИШИ» и подгоняешь схемы алгоритмов под свой код.
Готовый docx сохраняешь в PDF «Фамилия ИО ПЗ2-v1.pdf» и отправляешь письмом «МПС-ПЗ2».

Проверка себя: у каждой подпрограммы из таблицы 3.2 есть схема алгоритма, у каждой схемы — строка в таблице.

## Шаг 7. Три программы (КМ-3, часть 2)

Подробно — `docs/code-guide.md`. Коротко: `make code-init S=<ник>` → заготовки по рис. 7 ТЗ → пишешь процедуры → `make code S=<ник>`
(сборка, правила робота, сценарии в эмуляторе на модели нашей схемы) → отправляешь «Фамилия ИО-код-n.txt» из `build/…/code/`
письмом «МПС-код» (в письме — группа и вариант). Минимум для КМ-3 — программа 1 (клавиатура).

Проверка себя: все три программы ✅ в `report.md`; в каждом файле ровно одна строка с `%proc%` и одна с `%stop%`.

## Шаг 8. Защита (КМ-4)

1. Распечатай схему А3, подпиши у руководителя.
2. Загрузи одобренную работу в БАРС минимум за сутки до защиты.
3. Держи на ноутбуке ПЗ1, ПЗ2, три .txt и даташиты.
4. Прогони вопросы:
   - Зачем регистр после P0? (P0 сначала отдаёт адрес, потом данные — адрес запоминается по ALE.)
   - Как получается адрес индикатора? (Выход Yn дешифратора → A15…A13 = n → окно n·2000h; при CS_EN = 1.)
   - Зачем CS_EN? (Разрешает дешифратор: пока 0, ни одно устройство не выбрано.)
   - Как внешнее устройство пишет в буфер? (Свой порт IDT7005 → строб → INT1 → МК двигает «голову».)
   - Почему двухпортовая память? (Обе стороны работают независимо, МК не останавливает внешнее устройство.)
   - Что будет при переполнении? (Старейший отсчёт затирается, «хвост» сдвигается, флаг переполнения = 1.)
   - Зачем RC-цепочка и диоды на клавиатуре? (Дребезг ≤ 5 мс; защита от КЗ при двух нажатых кнопках.)
   - Почему статическая индикация? (Регистр держит символ, МК не тратит время.)
   - Почему один таймер на Y1 и T3? (Задачи не пересекаются по времени.)
   - Максимальная глубина стека? (Число из ПЗ2 — замер в эмуляторе, и откуда оно складывается.)
5. Повтори ЕСКД: УГО, рамка, нумерация элементов, перечень элементов. Банк вопросов — `docs/research/remarks-and-defense.md`.

# Справочник

## Что сдаётся и когда

| КМ | Что сдаёшь | Файл | Джоба |
| --- | --- | --- | --- |
| КМ-1 | Схема Э3 на А3 + перечень микросхем и разъёмов | «Фамилия ИО Схема-v1.png» | КМ-1 схема и перечень |
| КМ-2 | ПЗ1 — аппаратная часть | «Фамилия ИО ПЗ1-v1.pdf» | (в работе) |
| КМ-3 | ПЗ2 + три программы (минимум — первая) | «Фамилия ИО ПЗ2-v1.pdf», «Фамилия ИО-код-n.txt» | КМ-3 программы и ПЗ2 |
| КМ-4 | Тест на защите | — | — |

## Параметры варианта (табл. 1 ТЗ-2026)

Всё задаётся группой и M (1–30). k = M mod 7: строб Y1 — P1.k, строб Y2 — P1.(k+1). Y2: X1 ≠ 0 → (G + M + X1 + X2) mod 256, X1 = 0 → 0.
CS — номер выхода дешифратора Yn; адрес окна = n·2000h.

| Параметр | А-06 | А-07 | А-08 | А-09 | А-12 | А-17 | Аэ-21 |
| --- | --- | --- | --- | --- | --- | --- | --- |
| G | 6 | 7 | 8 | 9 | 12 | 17 | 21 |
| T1, мс (строб Y1) | 166+10M | 172+10M | 178+10M | 185+10M | 191+10M | 197+10M | 203+10M |
| CS буфера | Y1 | Y2 | Y3 | Y4 | Y5 | Y6 | Y7 |
| V, байт | 1200+10M | 1304+10M | 1408+10M | 1500+10M | 1604+10M | 1708+10M | 1800+10M |
| «Голова» / «хвост» | 38h / 3Ah | 3Ch / 3Eh | 40h / 42h | 44h / 46h | 47h / 49h | 4Bh / 4Dh | 51h / 53h |
| Бит пустоты / переполнения | M / M+6 | M / M+7 | M / M+8 | M / M+9 | M / M+12 | M / M+17 | M / M+21 |
| CS регистра Y2, чёт. / нечёт. M | Y2 / Y3 | Y3 / Y4 | Y4 / Y5 | Y5 / Y6 | Y6 / Y7 | Y7 / Y1 | Y1 / Y2 |
| T2, мкс (строб Y2) | 1506+30M | 1607+30M | 1708+30M | 1809+30M | 1912+30M | 2017+30M | 1421+30M |
| CS индикатора, чёт. / нечёт. M | Y3 / Y2 | Y4 / Y3 | Y5 / Y4 | Y6 / Y5 | Y7 / Y6 | Y1 / Y7 | Y2 / Y1 |
| T3, с (индикация) | 2,10+M/20 | 2,16+M/20 | 2,22+M/20 | 2,28+M/20 | 2,34+M/20 | 2,135+M/20 | 2,195+M/20 |
| Индикатор | ОК | ОК | ОА | ОА | ОА | ОК | ОК |
| CS клавиатуры | Y4 | Y5 | Y6 | Y7 | Y1 | Y2 | Y3 |

Общее для всех групп: клавиатура — INT0, строб X2 — INT1; T1 и T3 — Timer0, T2 — Timer1; клавиатура 4×3 при чётном M, 3×4 при нечётном;
X2 — до 4 отсчётов в секунду; фильтры 33 нФ на корпус + 470 мкФ. Таблица в машинном виде — `data/table-2026.yaml`.

## Производные параметры

- **Адреса:** окно устройства на выходе Yn — n·2000h … n·2000h + 1FFFh; в коде берём базовый адрес (`ADR_*` в `vars.inc`).
  Буфер — `BUF_START` … `BUF_START` + V − 1, `BUF_END` = `BUF_START` + V — точка заворота.
- **Указатели и флаги:** «голова» и «хвост» — по 2 байта, абсолютный адрес ячейки (младший байт по заданному адресу, старший — следующим),
  сразу грузятся в DPTR. Бит b лежит в байте 20h + b div 8, разряд b mod 8 (пример: бит 14 = 21h.6, бит 26 = 23h.2).
- **Стек:** SP = 07h, растёт вверх; до бит-области 20h — 24 байта. Банки регистров 1–3 (08h–1Fh) при SP = 07h заняты стеком — не переключай банк.
- **Таймеры** (12 МГц → 1 мкс): режим 1, TMOD = 11h. Строб Y2 — один отсчёт, загрузка 65536 − T2 (пример: 2332 → 0F6E4h).
  Y1 и T3 длиннее 65 мс — тик 1 мс (загрузка 0FC18h) и 16-битный счётчик тиков. Перезагрузка в обработчике теряет несколько мкс на тик —
  компенсируй (прибавляй к текущему TL0) или отметь в ПЗ2.

## Три программы по варианту

| № | Условие | Что пишем | Где вызов %proc% |
| --- | --- | --- | --- |
| 1 | все | Обработчик IRQ клавиатуры: скан матрицы, в A — код единственной нажатой клавиши (0–11) или 0FFh | в векторе INT0 (03h) |
| 2 | M чётное | Чтение из кольцевого буфера: байт → A, флаги пустоты и переполнения | после инициализации |
| 2 | M нечётное | Запись в кольцевой буфер: A → буфер, перезапись старого при переполнении, флаги | после инициализации |
| 3 | M mod 3 = 0 | Вывод символа по коду из A на индикатор + гашение через T3 по Timer0 | после инициализации |
| 3 | M mod 3 = 1 | Строб Y1 длительностью T1 на P1.k по Timer0 | после инициализации |
| 3 | M mod 3 = 2 | Расчёт Y2 по X1, X2 (переменные в ОЗУ), запись в регистр, строб T2 на P1.(k+1) по Timer1 | после инициализации |

Соглашения, которые проверяет `mpscode` (голова/хвост, флаги, X1/X2), — `docs/code-guide.md`, раздел 3.

## Алгоритмы подпрограмм

Основа для схем алгоритмов и их пояснений. Обозначения: {KB}, {IND}, {Y2R}, {BUF} — адреса устройств (`ADR_KB`, `ADR_IND`, `ADR_Y2`, `BUF_START`).

### Инициализация (сразу после Reset)

1. SP = 07h (по ТЗ).
2. CS_EN = 1 (P3.4) — разрешить дешифратор адреса.
3. P1: стробы Y1 и Y2 в пассивной единице.
4. Переменные: X1 = 0; «голова» = «хвост» = {BUF}; флаг пустоты = 1, переполнения = 0; служебные флаги = 0.
5. Индикатор погасить: в {IND} код «выкл» (00h — общий катод, 0FFh — общий анод; `IND_OFF`).
6. Регистр Y2: записать 0 со стробом (пассивное состояние).
7. Клавиатура: 0 во все столбцы, чтобы любое нажатие опускало строку и вызывало INT0.
8. TMOD = 11h, таймеры остановлены.
9. Прерывания: IT0 = IT1 = 1 (по спаду); INT1 (X2) — высокий приоритет; разрешить EX0, EX1, ET0, ET1, EA.

### Главный цикл

1. Если X1 ≠ 0, буфер не пуст и строб Y2 не идёт → прочитать X2 из буфера → рассчитать и выдать Y2.
2. Иначе, если последнее выданное Y2 ≠ 0 и строб не идёт → выдать Y2 = 0 (один раз, со стробом); буфер не читаем.
3. Вернуться к п. 1. Остальное (клавиатура, запись в буфер, таймеры) — в прерываниях.

### Обработчик клавиатуры (INT0) — программа 1

1. Сохранить в стеке нужные регистры (ACC, PSW, DPL, DPH).
2. Для каждого столбца i: записать в {KB} маску с нулём только в бите i; прочитать {KB}; оставить биты строк (`anl A, #(1 SHL KB_ROWS) - 1`).
3. Замкнутых контактов ровно один → код клавиши из таблицы 3 ТЗ (movc) → A; ни одного или больше → A = 0FFh.
4. Записать 0 во все столбцы (режим ожидания INT0), сбросить IE0 (спады INT0 во время опроса — не новое нажатие).
5. Реакция на код (в полной программе): 0–9 → X1 = код, вывести цифру на T3; 10 «Тест» → погасить индикатор, запустить Y1; 11 «Сброс» → очистить буфер, погасить индикатор.
6. Восстановить регистры, reti.

### Запись в буфер (INT1) — программа 2 при нечётном M

1. Если буфер полон (флаг пустоты = 0 и «голова» = «хвост») → «хвост» + 1 с заворотом (старейший отсчёт теряется), флаг переполнения = 1.
2. DPTR ← «голова»; `movx @DPTR, A`.
3. «Голова» + 1; если = {BUF} + V → «голова» = {BUF}.
4. Флаг пустоты = 0.

В буфере помещается ровно V отсчётов: «голова» = «хвост» при флаге пустоты = 0 означает «полон».

### Чтение из буфера — программа 2 при чётном M

1. Запретить INT1 (критическая секция: обработчик тоже двигает указатели и флаги).
2. Флаг пустоты = 1 → «нет данных» (A = 0 или C = 1), разрешить INT1, выйти.
3. DPTR ← «хвост»; `movx A, @DPTR`.
4. «Хвост» + 1 с заворотом; флаг переполнения = 0 (после чтения буфер не полон).
5. «Хвост» = «голова» → флаг пустоты = 1.
6. Разрешить INT1, выйти. Результат — в A.

### Очистка буфера (клавиша «Сброс»)

Запретить INT1 → «хвост» = «голова» → пустота = 1, переполнение = 0 → разрешить INT1.

### Вывод на индикатор + T3 — программа 3 при M mod 3 = 0

1. Код ≤ 10 → код сегментов из таблицы (`movc A, @A+DPTR`); иначе «выкл». Для ошибки — добавить бит dp. Для общего анода — инверсия (`xrl A, #IND_OFF`).
2. Записать в {IND}.
3. Режим Timer0 = «индикация», счётчик = T3 / 1 мс, загрузить и запустить Timer0 (повторный вызов перезапускает отсчёт).
4. Обработчик Timer0: перезагрузка; счётчик − 1; дошёл до 0 → записать «выкл», остановить таймер.

### Строб Y1 — программа 3 при M mod 3 = 1

1. Строб уже идёт → выйти.
2. Погасить индикатор (Timer0 забираем у индикации).
3. P1.k = 0; режим Timer0 = «Y1», счётчик = T1 / 1 мс; запустить Timer0. Процедура сразу возвращается — не ждать в цикле.
4. Обработчик Timer0: перезагрузка; счётчик − 1; дошёл до 0 → P1.k = 1, остановить таймер.

### Расчёт и выдача Y2 — программа 3 при M mod 3 = 2

1. X1 = 0 → Y2 = 0; иначе A = X1 + X2 + (G + M) (8-битное сложение, перенос отбрасывается — это и есть mod 256; `Y2_CONST` = G + M).
2. Записать Y2 в {Y2R} (`movx`) — **до** начала строба.
3. P1.(k+1) = 0; флаг «идёт строб Y2» = 1; TH1:TL1 = 65536 − T2; сбросить TF1; запустить Timer1.
4. Обработчик Timer1: P1.(k+1) = 1, остановить Timer1, флаг = 0.

## Коды ошибок и ответы на п. 2.3

Таблицу ошибок ТЗ оставляет на твой выбор; заготовка (её же генератор кладёт в ПЗ2). Ошибка — цифра с горящей dp, висит до любого нажатия, но не дольше T3.

| Индикация | Смысл | Когда выставляется |
| --- | --- | --- |
| 1. | Нажато несколько клавиш | опрос нашёл больше одного замкнутого контакта |
| 2. | Нажатие не распознано | INT0 пришёл, а замкнутых контактов нет |
| 3. | Переполнение буфера | запись X2 затёрла непрочитанный отсчёт |
| 4. | Повторный «Тест» | «Тест» нажат, пока идёт строб Y1 |

**Минимальное время заполнения буфера (X1 = 0).** При X1 = 0 сигнал Y2 пассивен и буфер не читается, X2 приходит не чаще 4 отсчётов в секунду:
t\_min = V / f\_X2 = V / 4 с. Пример: V = 1744 → 436 с (7,3 мин).

**Максимальная глубина стека.** Худший случай — все уровни вложенности сработали одновременно: главный цикл в подпрограмме, её прервал
низкоприоритетный обработчик, а его — высокоприоритетный. Каждый call или вход в прерывание кладёт 2 байта, каждый push — 1:
D\_max = D\_main + (2 + P\_low + C\_low) + (2 + P\_high + C\_high). Должно быть D\_max ≤ 24 байта (от 08h до бит-области 20h).
Для программы 1 генератор ПЗ2 даёт замер в эмуляторе на всех сценариях проверки (у эталона — 4 байта: вход в INT0 + call процедуры).

## Что обязано быть в ПЗ1

По п. 2.1 и 2.3 ТЗ в ПЗ1 любого варианта должны быть пункты ниже; последние три чаще всего забывают.

- [ ] Структурная и функциональная схемы с описанием блоков и распределением ресурсов (таймеры, INT, выходы дешифратора, CS_EN).
- [ ] Демультиплексирование шины (регистр по ALE) с временной диаграммой цикла чтения/записи МК.
- [ ] Дешифратор адреса: таблица «Yn → устройство → окно адресов».
- [ ] Подключение буфера, регистра Y2, индикатора, клавиатуры, питания — схема узла + расчёт номиналов (сегментные резисторы, RC-фильтр клавиш, ток через кнопку).
- [ ] Карта памяти: окна устройств по 8 Кбайт (n·2000h).
- [ ] Перечень элементов, список литературы, даташиты в приложении.
- [ ] Временная диаграмма обмена МК ↔ буфер: тайминги МК поверх времён доступа и записи IDT7005, с выводом «укладывается».
- [ ] Оценка мощности: токи микросхем по даташитам + индикатор в худшем случае (все 8 сегментов) + кнопки; требование к источнику (5 В ±5 %, ток с запасом).
- [ ] Механизм доступа внешнего устройства к буферу: кто выставляет данные и строб, какое прерывание срабатывает, кто и когда двигает указатели.

Типовые придирки: фильтрующие конденсаторы 33 нФ (не пФ) на каждый корпус, КМОП-серии (74AC/74HC) вместо ТТЛ (74AS/74LS), ГОСТовские УГО, заполненная рамка.

## Справочные данные из общей папки

Цифры для расчётов в ПЗ1 (мощность, токи сегментов, нагрузка портов), взятые из даташитов в папке группы.

| Компонент | Параметр | Значение | Файл |
| --- | --- | --- | --- |
| AT89S53 | Ток потребления, активный режим, 12 МГц | ≤ 25 мА | at89s53 \[ru\].pdf |
| AT89S53 | Ток потребления, режим ожидания (Idle), 12 МГц | ≤ 6,5 мА | at89s53 \[ru\].pdf |
| AT89S53 | I\_OL на один вывод / порт 0 / порты 1–3 / всего | 10 / 26 / 15 / 71 мА | at89s53 \[ru\].pdf |
| AT89S53 | Конденсаторы кварца | 30 пФ ± 10 пФ | at89s53 \[ru\].pdf |
| AT89S53 | Тактовая частота | 3–24 МГц | at89s53 \[ru\].pdf |
| FYS-5612 | Прямой ток сегмента, макс. | 30 мА | fys-5612a \[en\].pdf |
| FYS-5612 | V\_F (красный, по исполнению) | тип. 1,8–2,0 В, макс. 2,5 В | fys-5612a \[en\].pdf |
| FYS-5612 | Обратное напряжение, макс. | 5 В | fys-5612a \[en\].pdf |

ТЗ требует нагрузку на любую линию порта МК не более 10 мА. Логика — КМОП (серия 1554 или 74HC/AC). Даташиты IDT7005, 74HC138 и
регистров 74xx573/173/244 — с сайтов производителей (часть — в `docs/group/`).

Источник: [папка «Документация»](https://cloud.mail.ru/public/TeV3/qEfCeiDza/7%20%D0%A1%D0%95%D0%9C%D0%95%D0%A1%D0%A2%D0%A0/%D0%9A%D0%9F%20%D0%BF%D0%BE%20%D0%BC%D0%B8%D0%BA%D1%80%D0%BE%D0%BF%D1%80%D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).

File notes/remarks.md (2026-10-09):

# Замечания руководителя

Формат: дата — кто — что вернули — как исправили.

- 2026-10-06 — a12_ryazantsev_iv (КМ-1) — Михалин С.Н.: «Схема не отвечает требованиям стандартов: нумерация элементов, взаимные
  пересечения УГО, обозначение подключений к шине; и не удовл ТЗ: включение буфера например. Переделать.» — ошибки генератора, у всех:
  буфер по Прил. А методички, отводы 90° с именем у входа в шину, проверка наложений и нумерации в тестах (changelog 2026-10-06/23).
- 2026-10-08 — a12_ryazantsev_iv (КМ-1, СХЕМА-2) — Михалин С.Н.: «мало что поменялось»: нумерация «сверху вниз и слева направо»
  (DD2 должно быть DD1), пересечения УГО (DD3.1 и C2), обозначение подключений к шине (ALE и AD4, DD11), «+5V» не вниз; включение
  буфера не по ТЗ и «не верно по сути». — ошибки генератора, у всех: нумерация по центрам корпусов, номера линий у входов в шину и имена
  на проводниках, проверка «провод вдоль корпуса», правый порт IDT целиком на отдельном разъёме (changelog 2026-10-09/27).
- 2026-10-08 — a08_laptashkin_vi (КМ-1) — Гольцов А.Г.: перечень полный, «Розетка» — в примечание, без цвета, MPU/RAM шире, номера
  линий шин арабскими цифрами и имена посередине проводника, входы не напротив, пропорции R/C и тонкие обкладки, без номиналов и типов
  на листе, обозначения сверху/справа, «1» справа вверху, DD6 по ЕСКД, сброс ≤ 1 мкФ керамика, кнопки без кружков, надписи на линиях;
  «присылать задание». — ошибки генератора, у всех (changelog 2026-10-09/27); задание теперь уходит с карточкой КМ-1.

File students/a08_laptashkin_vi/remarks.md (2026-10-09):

# Замечания руководителя — Лапташкин В.И., А-08-23, вариант 12

Записи — сверху вниз по дате. Как работать: AGENTS.md, раздел «Замечания руководителя».

## 2026-10-09 — КМ-1 — Гольцов А.Г.

- **Студент:** Лапташкин В.И., А-08-23, вариант 12
- **Замечание:** Это же не весь перечень элементов. Давайте весь. Слово "розетка", видимо, должно быть в графе "примечание", а не "наименование". На схеме цвет убрать. MPU, RAM - перечеркнуты, сделайте УГО шире? Нумерация в шинах арабскими цифрами, А8, AD0 - это названия сигналов, дополнительная информация для читаемости схемы, пишется не при входе в шину, а на прогоне где-то посередине проводника. A15-AD4 и др. по изображению не входят в шину, а пересекают ее. Вход т-образный - сместите по вертикали. Странное изображение земли толстой чертой, но это допустимо. А обкладки конденсаторов толстые - уже неправильно. Соотношение сторон обкладок конденсатора 8х2, сторон резистора - 8х4. Номиналы и названия микросхем не нужны. Позиционное обозначение (R1...) пишется сверху или справа от элемента. DD11 в странное место вы нарисовали. Ошибкой не является, но уместнее ему быть где-то на месте DD5. Я просил присылать задание! Такие странные используются выводы на дешифраторе - это по заданию или вы придумали? УГО ИЛИ/ИЛИ-НЕ: единичка справа вверху, а не по центру. DD6 не по ЕСКД. 10 мкФ электролитический - много на сброс. Не более 1 мкФ и керамический. Кнопки рисуются как ключи, наклонная палочка и без кружочков. Зачем регистры разных видов на схеме - DD7 и DD10? Одним видом нельзя обойтись? Надписи налезают на линии, подвиньте. Индикация никакая не предусмотрена заданием? Светодиодная, звуковая? В целом правильно.
- **Что сделали:** — (дописать: что поправили и где — schema/fixes.yaml, текст ПЗ, код; какой прогон: СХЕМА-N / ПЗ1-K / ПЗ2-K)
- **Статус:** открыто

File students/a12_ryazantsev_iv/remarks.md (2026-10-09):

# Замечания руководителя — Рязанцев И.В., А-12-23, вариант 17

Записи — сверху вниз по дате. Как работать: AGENTS.md, раздел «Замечания руководителя».

## 2026-10-06 — КМ-1 — Михалин С.Н.

- **Студент:** Рязанцев И.В., А-12-23, вариант 17
- **Замечание:** Схема не отвечает требованиям стандартов: - нумерация элементов; - взаимные пересечения УГО; - обозначение подключений к шине; и не удовл ТЗ: - включение буфера например. Переделать.
- **Что сделали:** ошибки генератора — исправлены для всех (changelog 2026-10-06/23): буфер IDT7005 по рис. Прил. А методички (адрес и CS_buf на оба порта, правый пишет байт с разъёма по WR, строб X2 — INT1); отводы к шине только 90° с именем линии у входа; убраны наложения (VD, ZQ1, DD3.1, GND IDT7005, «+5V», CS_kbd, шина Y2 через землю) и кресты «не подключено»; нумерация по столбцам без неоднозначностей. Текст p1.buffer, p2.alg и схема алгоритма INT1 переписаны под новый буфер. Прогоны: СХЕМА-2, ПЗ1-2 по СХЕМА-2, ПЗ2-2 по СХЕМА-2 (Issue #7).
- **Статус:** исправлено, пересдать «Рязанцев ИВ Схема-v2.png»

## 2026-10-09 — КМ-? — Михалин С.Н.

- **Студент:** Рязанцев И.В., А-12-23, вариант 17
- **Замечание:** В этой версии мало что поменялось, может стоит более качественно относиться к делу? Схема не отвечает требованиям стандартов - нумерация элементов (у вас принято "сверху вниз и слева направо", тогда DD2 - это должно быть DD1 например) - взаимные пересечения УГО (см. DD3.1 и C2 например) - обозначение подключений к шине (например сигналы ALE и AD4, еще например DD11) - нельзя "подключение к Vcc" направлять вниз ... и др. На прошедшей в СР лекции я подробно описал эти ошибки. Включение буфера по прежнему не соотв. варианту (т.е. требованиям ТЗ) и не верно по сути. Переделать.
- **Что сделали:** — (дописать: что поправили и где — schema/fixes.yaml, текст ПЗ, код; какой прогон: СХЕМА-N / ПЗ1-K / ПЗ2-K)
- **Статус:** открыто

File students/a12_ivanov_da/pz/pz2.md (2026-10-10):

<!-- Текст студента для ПЗ2. Каждый раздел начинается строкой «## ид — название»: ид не менять.
     Строки «> ✍ …» — подсказки, в документ не попадают. Пиши под подсказкой обычными абзацами;
     markdown можно: **жирный**, *курсив*, списки через «- ». Пустой раздел → в документе жёлтое «ДОПИШИ».
     Файл можно пересоздать (make pz-init): написанный текст сохранится. -->

## p2.ide — Среда разработки и компилятор
> ✍ если работали в другой среде — впишите свою (название и версия, например «MCU 8051 IDE 1.4.9») (необязательно: без текста в документ идёт пересказ схемы)

Исходные тексты набирались на языке ассемблера 8051 и проверялись утилитой `mpscode` из репозитория проекта. Она использует ассемблер `asm51` и эмулятор `emu51`, выполняет программы на модели устройств моей схемы и дополнительно проверяет правила оформления для робота кафедры. Синтаксис исходных файлов совместим с Keil A51.

## p2.alg — Алгоритм программы в целом
> ✍ опиши основной цикл: что делается после сброса (инициализация), что крутится в основном цикле и какие действия выполняются в прерываниях (клавиатура — INT0, X2 — INT1, таймеры). 1–2 абзаца, со ссылками на рисунки ниже.

После сброса программа устанавливает `SP = 07h`, разрешает дешифратор сигналом `CS_EN`, задаёт начальные состояния буфера, индикатора и стробов, а затем настраивает таймеры и прерывания (рисунок 1). В основном цикле проверяются `X1`, состояние кольцевого буфера и занятость строба Y2: если обработка разрешена, очередной отсчёт читается из буфера, по нему рассчитывается Y2 и результат передаётся во внешний регистр; при `X1 = 0` буфер не читается (рисунок 2).

Асинхронные события обрабатываются отдельно. `INT0` запускает опрос клавиатуры и реакцию на найденную клавишу (рисунки 3 и 4), а `INT1` переносит принятый через правый порт IDT7005 отсчёт X2 из ячейки обмена в кольцо (рисунок 6). `Timer0` завершает выдержку Y1 или время индикации T3, а `Timer1` возвращает строб Y2 в пассивное состояние. В трёх программах варианта отдельно реализованы и проверены процедуры опроса клавиатуры, записи в буфер и расчёта Y2 со стробом.

## flow.01-init — Пояснение к рисунку 1
> ✍ своё пояснение к рисунку 1 («Инициализация МПС и основная программа»): что делает алгоритм по шагам и почему так (3–6 предложений) (необязательно: без текста в документ идёт пересказ схемы)

Сначала указатель стека устанавливается в `07h`, чтобы стек рос из области после банка регистров 0 и не пересекался с переменными. Затем включается дешифратор адресов, буфер помечается пустым, `X1` обнуляется, а оба строба переводятся в пассивную единицу. Все столбцы клавиатуры опускаются в ноль, чтобы нажатие гарантированно сформировало спад на `INT0`, индикатор гасится. После настройки таймеров и разрешения прерываний основная программа переходит к ожиданию событий.

## flow.02-main — Пояснение к рисунку 2
> ✍ своё пояснение к рисунку 2 («Основной цикл программы»): что делает алгоритм по шагам и почему так (3–6 предложений) (необязательно: без текста в документ идёт пересказ схемы)

Основной цикл сначала проверяет, что `X1` не равен нулю, буфер содержит данные и предыдущий строб Y2 уже завершён. При выполнении этих условий из кольца извлекается один отсчёт X2, рассчитывается новое значение Y2 и запускается его строб. Когда `X1 = 0`, чтение буфера запрещено требованием ТЗ; если в регистре ещё осталось активное значение, в него один раз записывается ноль со стробом. В остальных случаях цикл ничего не меняет и повторяет проверку.

## flow.03-kbscan — Пояснение к рисунку 3
> ✍ своё пояснение к рисунку 3 («Опрос клавиатуры (обработчик INT0)»): что делает алгоритм по шагам и почему так (3–6 предложений) (необязательно: без текста в документ идёт пересказ схемы)

Процедура по очереди выбирает каждый из трёх столбцов клавиатуры нулевым уровнем и читает четыре младших бита строк. Для каждого обнаруженного замыкания увеличивается общий счётчик, а код первого контакта вычисляется по расположению клавиш 3×4. После полного прохода все столбцы снова записываются нулями, иначе следующее нажатие не создаст запрос `INT0`; дополнительно сбрасывается `IE0`. Код возвращается только при одном замкнутом контакте, а при отсутствии клавиши или нескольких нажатиях выдаётся `0FFh`.

## flow.04-keys — Пояснение к рисунку 4
> ✍ своё пояснение к рисунку 4 («Обработчик прерывания INT0: реакция на клавишу»): что делает алгоритм по шагам и почему так (3–6 предложений) (необязательно: без текста в документ идёт пересказ схемы)

Обработчик сохраняет используемые регистры и вызывает процедуру сканирования клавиатуры. Цифровой код от 0 до 9 записывается в `X1` и выводится на индикатор на время T3. Клавиша «Тест» гасит индикатор и запускает строб Y1, а «Сброс» очищает кольцевой буфер и также выключает индикацию. Значение `0FFh` считается ошибочным опросом; после выбранной реакции контекст восстанавливается и выполняется возврат из прерывания.

## flow.05-bufwrite — Пояснение к рисунку 5
> ✍ своё пояснение к рисунку 5 («Запись отсчёта в кольцевой буфер»): что делает алгоритм по шагам и почему так (3–6 предложений) (необязательно: без текста в документ идёт пересказ схемы)

Перед записью программа снимает старый флаг переполнения и проверяет состояние указателей. В принятой политике используются все 1654 ячейки: совпадение «головы» и «хвоста» означает полный буфер только при сброшенном флаге пустоты. В этом случае «хвост» передвигается, старейший отсчёт теряется и устанавливается `F_OVF`. Новый байт записывается по адресу «головы», после чего она сдвигается с заворотом от `0A675h` к `0A000h`, а `F_EMPTY` сбрасывается.

## flow.05a-x2isr — Пояснение к рисунку 6
> ✍ своё пояснение к рисунку 6 («Обработчик прерывания INT1: приём отсчёта X2 от внешнего устройства»): что делает алгоритм по шагам и почему так (3–6 предложений) (необязательно: без текста в документ идёт пересказ схемы)

Спад внешнего строба вызывает `INT1`, после чего обработчик сохраняет контекст. Считывать данные сразу нельзя: правый порт IDT7005 завершает запись по фронту строба, поэтому сначала ожидается возвращение линии `P3.3` в единицу. Затем МК через левый порт читает байт из ячейки обмена `0BFFFh` и вызывает процедуру записи в кольцевой буфер. После восстановления регистров обработчик завершается командой `RETI`.

## flow.06-bufread — Пояснение к рисунку 7
> ✍ своё пояснение к рисунку 7 («Чтение отсчёта из кольцевого буфера»): что делает алгоритм по шагам и почему так (3–6 предложений) (необязательно: без текста в документ идёт пересказ схемы)

Если установлен флаг пустоты, процедура возвращает ноль и не меняет указатели. Иначе байт читается из ячейки, на которую указывает «хвост», после чего указатель переходит к следующему адресу с заворотом в начало кольца. Успешное чтение снимает признак переполнения. Когда новый «хвост» догоняет «голову», прочитан последний отсчёт и устанавливается `F_EMPTY`.

## flow.07-bufclear — Пояснение к рисунку 8
> ✍ своё пояснение к рисунку 8 («Очистка кольцевого буфера (клавиша «Сброс»)»): что делает алгоритм по шагам и почему так (3–6 предложений) (необязательно: без текста в документ идёт пересказ схемы)

На время очистки запрещается `INT1`, чтобы новый отсчёт не изменил буфер между операциями с указателями. «Хвост» приравнивается к «голове»: содержимое памяти физически не стирается, но все старые байты становятся недоступными для чтения. Одновременно устанавливается флаг пустоты и снимается флаг переполнения. После получения согласованного состояния приём X2 снова разрешается.

## flow.08-show — Пояснение к рисунку 9
> ✍ своё пояснение к рисунку 9 («Вывод символа на индикатор»): что делает алгоритм по шагам и почему так (3–6 предложений) (необязательно: без текста в документ идёт пересказ схемы)

Для кодов 0–10 выбирается соответствующая комбинация сегментов цифр или символа `E`; остальные значения преобразуются в код погашенного индикатора. Так как в моём варианте используется общий анод, нулевой бит включает сегмент, а `0FFh` выключает все сегменты. Подготовленный байт записывается в регистр индикатора. Затем Timer0 запускается на 2590 тиков по 1 мс, чтобы символ автоматически погас через T3.

## flow.09-t0 — Пояснение к рисунку 10
> ✍ своё пояснение к рисунку 10 («Обработчик прерывания Timer0: отсчёт T1 и T3»): что делает алгоритм по шагам и почему так (3–6 предложений) (необязательно: без текста в документ идёт пересказ схемы)

При каждом переполнении Timer0 сохраняются аккумулятор и `PSW`, а регистр таймера снова загружается значением для тика 1 мс. Программный счётчик уменьшается на единицу. Пока он не обнулился, обработчик сразу возвращается; при нуле таймер останавливается. Дальнейшее действие определяется режимом: для T1 линия Y1 возвращается в единицу, а для T3 гасится индикатор, после чего контекст восстанавливается.

## flow.10-y1 — Пояснение к рисунку 11
> ✍ своё пояснение к рисунку 11 («Начало строба Y1»): что делает алгоритм по шагам и почему так (3–6 предложений) (необязательно: без текста в документ идёт пересказ схемы)

Для длительности T1 в счётчик заносится 241 тик, а Timer0 загружается значением `0FC18h`, соответствующим 1 мс. Линия `P1.5` переводится в активный ноль и таймер запускается. Сама процедура сразу возвращается и не ждёт 241 мс в цикле, поэтому МК может обслуживать другие события. Завершение строба выполняет обработчик Timer0.

## flow.11-y2 — Пояснение к рисунку 12
> ✍ своё пояснение к рисунку 12 («Расчёт и выдача сигнала Y2»): что делает алгоритм по шагам и почему так (3–6 предложений) (необязательно: без текста в документ идёт пересказ схемы)

При `X1 = 0` в аккумулятор помещается пассивное значение Y2, равное нулю. В остальных случаях рассчитывается `(17 + X1 + X2) mod 256`, причём перенос за пределы байта отбрасывается. Сначала результат записывается по адресу `0E000h` в выходной регистр, чтобы к началу строба данные уже были устойчивы. Затем Timer1 загружается значением `0F7F2h`, линия `P1.6` опускается в ноль и начинается отсчёт 2062 мкс.

## flow.12-t1 — Пояснение к рисунку 13
> ✍ своё пояснение к рисунку 13 («Обработчик прерывания Timer1: конец строба Y2»): что делает алгоритм по шагам и почему так (3–6 предложений) (необязательно: без текста в документ идёт пересказ схемы)

Переполнение Timer1 означает, что требуемые 2062 мкс прошли. Обработчик останавливает таймер, возвращает `P1.6` в пассивную единицу и снимает флаг `TF1`. Он не использует аккумулятор и `PSW`, поэтому не меняет вычисления основной программы. Возврат выполняется через `RETI`, после чего можно формировать следующий строб.

## p2.errors — Коды ошибок
> ✍ проверь таблицу кодов ошибок выше: оставь те, что обрабатывает твоя программа, и одним-двумя предложениями опиши реакцию на ошибку (или напиши «таблица соответствует программе»).

В реализованных фрагментах опрос клавиатуры возвращает `0FFh`, если не найдено ровно одно нажатие, а запись в буфер устанавливает `F_OVF` при вытеснении старого отсчёта. Преобразование этих состояний в индикацию «1.», «2.» или «3.», а также проверка повторного нажатия «Тест» для кода «4.» относятся к обработчику полной системы и показаны в общей схеме алгоритма; отдельные проверочные программы индикатором не управляют.

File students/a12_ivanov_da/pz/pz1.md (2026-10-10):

<!-- Текст студента для ПЗ1. Каждый раздел начинается строкой «## ид — название»: ид не менять.
     Строки «> ✍ …» — подсказки, в документ не попадают. Пиши под подсказкой обычными абзацами;
     markdown можно: **жирный**, *курсив*, списки через «- ». Пустой раздел → в документе жёлтое «ДОПИШИ».
     Файл можно пересоздать (make pz-init): написанный текст сохранится. -->

## p1.intro — Введение: своими словами
> ✍ одним абзацем — что делает твоя система и чем вариант отличается (клавиатура, индикатор, сигналы Y). Можно удалить подсказку, если введение устраивает.

В этой работе я разрабатываю МПС на базе AT89S53, которая принимает команды с матричной клавиатуры 3×4 и отсчёты X2 через двухпортовую память, показывает введённые символы на семисегментном индикаторе и формирует выходные сигналы Y1 и Y2. Для моего варианта кольцевой буфер рассчитан на 1654 байта, Y1 выдаётся на P1.5 на 241 мс, а Y2 сопровождается стробом на P1.6 длительностью 2062 мкс; его значение при X1 ≠ 0 вычисляется как (17 + X1 + X2) mod 256.

## p1.buffer — Механизм обмена через буфер
> ✍ своими словами проследи путь одного отсчёта X2: разъём → ячейка обмена → прерывание → кольцо → чтение МК → Y2 (кто выставляет адрес, какой строб, кто двигает «голову» и «хвост»). 3–5 предложений, не пересказывая абзац выше.

Внешнее устройство через отдельный разъём выставляет адрес ячейки 0BFFFh правого порта IDT7005, передаёт байт X2 и формирует активный нулём строб записи. Этот же строб вызывает INT1; после его окончания МК читает записанный байт через левый порт памяти и помещает его в кольцевой буфер 0A000h–0A675h. Адрес следующей записи хранится в указателе «голова», поэтому его меняет МК после записи, а «хвост» передвигается при чтении очередного отсчёта для расчёта Y2. Когда конец области достигнут, указатель возвращается к началу, а при переполнении самый старый отсчёт заменяется новым и устанавливается флаг переполнения.

## p1.timing — Вывод по временам IDT7005
> ✍ свой вывод по сравнению времён (2–4 предложения) (необязательно: без текста в документ идёт пересказ схемы)

По таблице видно, что IDT7005 успевает отработать обмен раньше, чем его завершает AT89S53. При чтении память формирует данные максимум за 30–55 нс, тогда как шина МК оставляет 252–495 нс; для записи запас составляет от 33 до 403 нс в зависимости от параметра. Поэтому память можно подключить напрямую: дополнительные циклы ожидания не требуются.

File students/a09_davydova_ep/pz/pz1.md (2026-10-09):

<!-- Текст студента для ПЗ1. Каждый раздел начинается строкой «## ид — название»: ид не менять.
     Строки «> ✍ …» — подсказки, в документ не попадают. Пиши под подсказкой обычными абзацами;
     markdown можно: **жирный**, *курсив*, списки через «- ». Пустой раздел → в документе жёлтое «ДОПИШИ».
     Файл можно пересоздать (make pz-init): написанный текст сохранится. -->

## p1.intro — Введение: своими словами
> ✍ одним абзацем — что делает твоя система и чем вариант отличается (клавиатура, индикатор, сигналы Y). Можно удалить подсказку, если введение устраивает.

В курсовой работе разработана аппаратная часть микропроцессорной системы на микроконтроллере AT89S53, которая принимает данные от двух источников и выдаёт два управляющих сигнала. Число X1 оператор набирает на матричной клавиатуре 4×3 (четыре столбца, три строки), а отсчёты X2 приходят от внешнего устройства и накапливаются в двухпортовом ОЗУ IDT7005, работающем как кольцевой буфер на 1520 байт. Результат работы системы — строб Y1 длительностью 205 мс на выводе P1.2 и восьмиразрядный код Y2 = (9 + 2 + X1 + X2) mod 256 (при X1 = 0 — ноль), который записывается в выходной регистр и сопровождается стробом 1869 мкс на выводе P1.3. Для контроля введённой цифры служит семисегментный индикатор с общим анодом, поэтому сегменты в моём варианте зажигаются нулём. Все внешние устройства выбираются через дешифратор 74HC138: буфер — выходом Y4, регистр Y2 — Y5, индикатор — Y6, клавиатура — Y7.

## p1.buffer — Механизм обмена через буфер
> ✍ опиши своими словами, как внешнее устройство записывает X2 и как МК читает буфер (кто выставляет адрес, какой строб, какое прерывание, кто двигает «голову» и «хвост»). 3–5 предложений.

Обмен через буфер в моём варианте удобно проследить по одному отсчёту. Внешнее устройство через отдельный разъём доступа к буферу само выставляет на правом порту IDT7005 адрес ячейки обмена 9FFFh и байт X2 и подаёт строб на вход R/W правого порта, так что байт заносится в память без участия микроконтроллера. Этот же строб приходит на вход INT1; прерывание срабатывает по спаду, а запись в ОЗУ заканчивается по фронту, поэтому обработчик сначала дожидается, пока P3.3 снова станет единицей, и только потом читает ячейку обмена через левый порт (выбор Y4, сигнал RD на OE). Прочитанный отсчёт процедура записи кладёт в кольцо 8000h–85EFh по адресу «головы» и сдвигает её; если кольцо было заполнено, вместе с «головой» уходит вперёд и «хвост», а программа ставит флаг переполнения. Когда отсчёт нужен для расчёта Y2, МК читает его тем же левым портом по адресу «хвоста» и сдвигает «хвост»; после 85EFh оба указателя возвращаются на 8000h. Указатели и флаги пустоты и переполнения хранятся во внутренней памяти МК, внешнему устройству достаточно знать один адрес ячейки обмена.

## p1.timing — Вывод по временам IDT7005
> ✍ свой вывод по сравнению времён (2–4 предложения) (необязательно: без текста в документ идёт пересказ схемы)

Из сравнения видно, что микросхема IDT7005S55 намного быстрее шины AT89S53 на 12 МГц: при чтении данные нужны МК лишь через 252 нс после спада RD, а память выдаёт их за 30 нс, так что запас — 222 нс. При записи в кольцо меньше всего запас по удержанию данных после конца WR — 33 нс, но ОЗУ удержания вообще не требует, а остальные требования к записи перекрыты в несколько раз. Значит, согласующие элементы и такты ожидания не нужны, и буфер можно подключать к шине напрямую.

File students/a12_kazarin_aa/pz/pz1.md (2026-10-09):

<!-- Текст студента для ПЗ1. Каждый раздел начинается строкой «## ид — название»: ид не менять.
     Строки «> ✍ …» — подсказки, в документ не попадают. Пиши под подсказкой обычными абзацами;
     markdown можно: **жирный**, *курсив*, списки через «- ». Пустой раздел → в документе жёлтое «ДОПИШИ».
     Файл можно пересоздать (make pz-init): написанный текст сохранится. -->

## p1.intro — Введение: своими словами
В этой курсовой рассматривается микропроцессорная система на базе AT89S53, которая принимает команды с клавиатуры, обменивается отсчётами с внешним устройством через двухпортовый буфер и формирует управляющий сигнал Y2. В моём варианте используются клавиатура 4×3 и индикатор с общим анодом. Цифровое значение X1 задаётся с клавиатуры, отсчёт X2 поступает от внешнего устройства; при X1 = 0 выход Y2 остаётся пассивным.

## p1.buffer — Механизм обмена через буфер
Порты IDT7005 в моей схеме полностью независимы: у каждого свои адрес, данные и сигналы управления. Левый порт целиком принадлежит микроконтроллеру — адрес A0–A12, данные D0–D7, CE от сигнала CS_buf дешифратора, OE от RD и R/W от WR, так что через него МК и пишет, и читает любую ячейку. Правый порт целиком выведен на отдельный разъём внешнего устройства: CER подключён к общему проводу, OER — к +5 В, а запись выполняется стробом X2 на входе R/WR.

Путь одного отсчёта такой. Внешнее устройство выставляет на разъёме адрес ячейки обмена 0BFFFh (последняя ячейка окна буфера), байт X2 и опускает строб; правый порт запоминает байт по фронту строба без участия микроконтроллера. Этот же строб приходит на INT1, обработчик дожидается, пока P3.3 снова станет единицей, читает ячейку обмена через левый порт и подпрограммой записи помещает отсчёт в кольцо 0A000h–0A693h по адресу «головы», сдвигая её дальше (после последней ячейки — на начало). «Голову», «хвост» и флаги пустоты и переполнения хранит и меняет только микроконтроллер во внутренней памяти. Основной цикл забирает самый старый отсчёт по «хвосту» тем же левым портом и по нему рассчитывает Y2.

## p1.timing — Вывод по временам IDT7005
По таблице 1.8 видно, что у IDT7005S55 большой запас по всем временам: при чтении микроконтроллер ждёт данные 252 нс после спада RD, а памяти достаточно 30 нс от OE и 55 нс от адреса; импульс WR длится не менее 400 нс при требуемых 40 нс. Поэтому медленный вариант микросхемы здесь подходит, а такты ожидания не нужны. Запись X2 со стороны разъёма идёт через правый порт и от шины микроконтроллера не зависит: её времена обеспечивает внешнее устройство, а обработчик INT1 читает ячейку обмена только после окончания строба, когда байт в ней уже записан.

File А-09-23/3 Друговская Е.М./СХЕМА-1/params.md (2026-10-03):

# Параметры варианта: А-09, M = 3 (ТЗ 2026)

Студент: Друговская Е.М., руководитель: Ключанский А.А.

## Что писать

| Программа | Что |
| --- | --- |
| 1 | обработчик IRQ клавиатуры (INT0): скан матрицы, код в A или 0FFh |
| 2 | запись в кольцевой буфер (M нечётное) |
| 3 | вывод символа на индикатор + гашение по T3 (таймер) (M mod 3 = 0) |

## Выводы МК

| Сигнал | Вывод |
| --- | --- |
| Строб Y1 (k = M mod 7 = 3) | P1.3 |
| Строб Y2 | P1.4 |
| IRQ клавиатуры | INT0 (P3.2), по спаду |
| Строб X2 от внешнего устройства | INT1 (P3.3), по спаду |
| CS: Индикатор | Y5 |
| CS: Клавиатура | Y7 |
| CS: Буфер (IDT7005) | Y4 |
| CS: Регистр Y2 | Y6 |
| CS_EN (разрешение дешифратора 74HC138, E2) | P3.4 — перед обращением к внешним устройствам = 1 |
| Адрес устройств | P2.5–P2.7 = A13–A15 → A0–A2 дешифратора; P2.0–P2.4 = A8–A12 |
| Свободные выходы дешифратора | Y0, Y1, Y2, Y3 |

## Карта внешней памяти (movx)

| Устройство | CS | Окно |
| --- | --- | --- |
| Индикатор | Y5 | 0A000h–0BFFFh |
| Клавиатура | Y7 | 0E000h–0FFFFh |
| Буфер (IDT7005) | Y4 | 8000h–9FFFh |
| Регистр Y2 | Y6 | 0C000h–0DFFFh |

Буфер: 1530 байт, ячейки 8000h–85F9h, после 85F9h указатель заворачивается на начало.
Отсчёт X2 внешнее устройство пишет в ячейку-«почтовый ящик» 9FFFh (правый порт IDT7005, адрес зашит единицами); по его стробу (прерывание) МК читает ящик и кладёт отсчёт в кольцо процедурой записи.

## Внутренняя память

| Что | Где |
| --- | --- |
| «Голова» (2 байта, абсолютный адрес) | 44h, 45h |
| «Хвост» (2 байта) | 46h, 47h |
| Флаг пустоты | бит 3 (3h) = 20h.3 |
| Флаг переполнения | бит 12 (0Ch) = 21h.4 |
| Стек | SP = 07h, до бит-области 20h — 24 байта |

## Время (кварц 12 МГц, машинный цикл 1 мкс)

| Интервал | Длительность | Таймер | Как отсчитывать |
| --- | --- | --- | --- |
| T1 — строб Y1 | 215 мс | Timer0 | тик 5 мс (загрузка 0EC78h) × 43, счётчик 8 бит |
| T2 — строб Y2 | 1899 мкс | Timer1 | один отсчёт, загрузка 0F895h |
| T3 — индикация | 2430 мс | Timer0 | тик 5 мс (загрузка 0EC78h) × 486, счётчик 16 бит |

TMOD = 11h (оба таймера в режиме 1).

## Пульт

- Клавиатура: 3x4 (3 столбца × 4 строки).
- Индикатор: общий анод (FYS-5612BX).

## Ответы на п. 2.3 ТЗ

- Минимальное время заполнения буфера при X1 = 0: V / 4 = 1530 / 4 = 382 с.
- Функция: X1 ≠ 0 → Y2 = (G + M + X1 + X2) mod 256 = (9 + 3 + X1 + X2) mod 256 = (12 + X1 + X2) mod 256; X1 = 0 → Y2 = 0.

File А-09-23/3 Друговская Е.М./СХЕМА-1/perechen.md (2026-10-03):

# Перечень элементов — Группа А-09-23, Вариант 3, ПЭ3

| Поз. обозначение | Наименование | Кол. | Примечание |
| --- | --- | --- | --- |
|  | **Конденсаторы** |  |  |
| C1, C2 | К10-17Б 30 пФ ±10 % | 2 |  |
| C3 | К50-35 16 В 10 мкФ | 1 |  |
| C4 | К50-35 16 В 470 мкФ | 1 |  |
| C5–C15 | К10-17Б 33 нФ ±10 % | 11 |  |
| C16–C19 | К10-17Б 220 нФ ±10 % | 4 |  |
|  | **Микросхемы** |  |  |
| DD1 | AT89S53-24PU | 1 | Микроконтроллер |
| DD2 | 74HC173 | 1 | Регистр 4-разрядный |
| DD3 | 74HC02 | 1 | 4 элемента 2ИЛИ-НЕ |
| DD4, DD5 | 74AC573 | 2 | Регистр 8-разрядный |
| DD6 | 74HC21 | 1 | 2 элемента 4И |
| DD7 | IN74AC244 | 1 | Повторитель с тремя состояниями |
| DD8 | IDT7005S55PF | 1 | Двухпортовое ОЗУ 8Кx8 |
| DD9 | 74HC32 | 1 | 4 элемента 2ИЛИ |
| DD10 | 74AC573 | 1 | Регистр 8-разрядный |
| DD11 | 74HC138 | 1 | Дешифратор 3 на 8 |
|  | **Индикаторы** |  |  |
| HG1 | Индикатор FYS-5612BX | 1 | Общий анод |
|  | **Резисторы** |  |  |
| R1 | МЛТ-0,125 10 кОм ±5 % | 1 |  |
| R2–R5 | МЛТ-0,125 2 кОм ±5 % | 4 |  |
| R6–R9 | МЛТ-0,125 10 кОм ±5 % | 4 |  |
| R10–R17 | МЛТ-0,125 330 Ом ±5 % | 8 |  |
|  | **Кнопки** |  |  |
| SB1–SB12 | Кнопка DTSM-62N-V | 12 |  |
|  | **Диоды** |  |  |
| VD1–VD3 | Диод КД521А | 3 |  |
|  | **Разъёмы** |  |  |
| XS1 | Розетка PBS-23 | 1 | 23 конт. |
|  | **Резонаторы** |  |  |
| ZQ1 | Резонатор кварцевый HC-49S 12 МГц | 1 |  |

# Черновик для КМ-1 (только микросхемы и разъёмы)

| Поз. обозначение | Наименование | Кол. | Примечание |
| --- | --- | --- | --- |
|  | **Микросхемы** |  |  |
| DD1 | AT89S53-24PU | 1 | Микроконтроллер |
| DD2 | 74HC173 | 1 | Регистр 4-разрядный |
| DD3 | 74HC02 | 1 | 4 элемента 2ИЛИ-НЕ |
| DD4, DD5 | 74AC573 | 2 | Регистр 8-разрядный |
| DD6 | 74HC21 | 1 | 2 элемента 4И |
| DD7 | IN74AC244 | 1 | Повторитель с тремя состояниями |
| DD8 | IDT7005S55PF | 1 | Двухпортовое ОЗУ 8Кx8 |
| DD9 | 74HC32 | 1 | 4 элемента 2ИЛИ |
| DD10 | 74AC573 | 1 | Регистр 8-разрядный |
| DD11 | 74HC138 | 1 | Дешифратор 3 на 8 |
|  | **Разъёмы** |  |  |
| XS1 | Розетка PBS-23 | 1 | 23 конт. |

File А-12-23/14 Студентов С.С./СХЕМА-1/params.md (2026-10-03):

# Параметры варианта: А-12, M = 14 (ТЗ 2026)

Студент: Студентов С.С., руководитель: Михалин С.Н.

## Что писать

| Программа | Что |
| --- | --- |
| 1 | обработчик IRQ клавиатуры (INT0): скан матрицы, код в A или 0FFh |
| 2 | чтение из кольцевого буфера (M чётное) |
| 3 | расчёт Y2 = (12+14+X1+X2) mod 256, запись в регистр, строб T2 (таймер) (M mod 3 = 2) |

## Выводы МК

| Сигнал | Вывод |
| --- | --- |
| Строб Y1 (k = M mod 7 = 0) | P1.0 |
| Строб Y2 | P1.1 |
| IRQ клавиатуры | INT0 (P3.2), по спаду |
| Строб X2 от внешнего устройства | INT1 (P3.3), по спаду |
| CS: Индикатор | Y7 |
| CS: Клавиатура | Y1 |
| CS: Буфер (IDT7005) | Y5 |
| CS: Регистр Y2 | Y6 |
| CS_EN (разрешение дешифратора 74HC138, E2) | P3.4 — перед обращением к внешним устройствам = 1 |
| Адрес устройств | P2.5–P2.7 = A13–A15 → A0–A2 дешифратора; P2.0–P2.4 = A8–A12 |
| Свободные выходы дешифратора | Y0, Y2, Y3, Y4 |

## Карта внешней памяти (movx)

| Устройство | CS | Окно |
| --- | --- | --- |
| Индикатор | Y7 | 0E000h–0FFFFh |
| Клавиатура | Y1 | 2000h–3FFFh |
| Буфер (IDT7005) | Y5 | 0A000h–0BFFFh |
| Регистр Y2 | Y6 | 0C000h–0DFFFh |

Буфер: 1744 байт, ячейки 0A000h–0A6CFh, после 0A6CFh указатель заворачивается на начало.
Отсчёт X2 внешнее устройство пишет в ячейку-«почтовый ящик» 0BFFFh (правый порт IDT7005, адрес зашит единицами); по его стробу (прерывание) МК читает ящик и кладёт отсчёт в кольцо процедурой записи.

## Внутренняя память

| Что | Где |
| --- | --- |
| «Голова» (2 байта, абсолютный адрес) | 47h, 48h |
| «Хвост» (2 байта) | 49h, 4Ah |
| Флаг пустоты | бит 14 (0Eh) = 21h.6 |
| Флаг переполнения | бит 26 (1Ah) = 23h.2 |
| Стек | SP = 07h, до бит-области 20h — 24 байта |

## Время (кварц 12 МГц, машинный цикл 1 мкс)

| Интервал | Длительность | Таймер | Как отсчитывать |
| --- | --- | --- | --- |
| T1 — строб Y1 | 331 мс | Timer0 | тик 1 мс (загрузка 0FC18h) × 331, счётчик 16 бит |
| T2 — строб Y2 | 2332 мкс | Timer1 | один отсчёт, загрузка 0F6E4h |
| T3 — индикация | 3040 мс | Timer0 | тик 1 мс (загрузка 0FC18h) × 3040, счётчик 16 бит |

TMOD = 11h (оба таймера в режиме 1).

## Пульт

- Клавиатура: 4x3 (4 столбца × 3 строки).
- Индикатор: общий анод (FYS-5612BX).

## Ответы на п. 2.3 ТЗ

- Минимальное время заполнения буфера при X1 = 0: V / 4 = 1744 / 4 = 436 с.
- Функция: X1 ≠ 0 → Y2 = (G + M + X1 + X2) mod 256 = (12 + 14 + X1 + X2) mod 256 = (26 + X1 + X2) mod 256; X1 = 0 → Y2 = 0.

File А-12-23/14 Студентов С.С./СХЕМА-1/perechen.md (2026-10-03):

# Перечень элементов — Группа А-12-23, Вариант 14, ПЭ3

| Поз. обозначение | Наименование | Кол. | Примечание |
| --- | --- | --- | --- |
|  | **Конденсаторы** |  |  |
| C1, C2 | К10-17Б 30 пФ ±10 % | 2 |  |
| C3 | К50-35 16 В 10 мкФ | 1 |  |
| C4 | К50-35 16 В 470 мкФ | 1 |  |
| C5–C15 | К10-17Б 33 нФ ±10 % | 11 |  |
| C16–C18 | К10-17Б 220 нФ ±10 % | 3 |  |
|  | **Микросхемы** |  |  |
| DD1 | AT89S53-24PU | 1 | Микроконтроллер |
| DD2 | 74HC173 | 1 | Регистр 4-разрядный |
| DD3 | 74HC02 | 1 | 4 элемента 2ИЛИ-НЕ |
| DD4, DD5 | 74AC573 | 2 | Регистр 8-разрядный |
| DD6 | 74HC11 | 1 | 3 элемента 3И |
| DD7 | IN74AC244 | 1 | Повторитель с тремя состояниями |
| DD8 | IDT7005S55PF | 1 | Двухпортовое ОЗУ 8Кx8 |
| DD9 | 74HC32 | 1 | 4 элемента 2ИЛИ |
| DD10 | 74AC573 | 1 | Регистр 8-разрядный |
| DD11 | 74HC138 | 1 | Дешифратор 3 на 8 |
|  | **Индикаторы** |  |  |
| HG1 | Индикатор FYS-5612BX | 1 | Общий анод |
|  | **Резисторы** |  |  |
| R1 | МЛТ-0,125 10 кОм ±5 % | 1 |  |
| R2–R4 | МЛТ-0,125 2 кОм ±5 % | 3 |  |
| R5–R7 | МЛТ-0,125 10 кОм ±5 % | 3 |  |
| R8–R15 | МЛТ-0,125 330 Ом ±5 % | 8 |  |
|  | **Кнопки** |  |  |
| SB1–SB12 | Кнопка DTSM-62N-V | 12 |  |
|  | **Диоды** |  |  |
| VD1–VD4 | Диод КД521А | 4 |  |
|  | **Разъёмы** |  |  |
| XS1 | Розетка PBS-2 | 1 | 2 конт. |
| XS2 | Розетка PBS-10 | 1 | 10 конт. |
| XS3 | Розетка PBS-11 | 1 | 11 конт. |
|  | **Резонаторы** |  |  |
| ZQ1 | Резонатор кварцевый HC-49S 12 МГц | 1 |  |

# Черновик для КМ-1 (только микросхемы и разъёмы)

| Поз. обозначение | Наименование | Кол. | Примечание |
| --- | --- | --- | --- |
|  | **Микросхемы** |  |  |
| DD1 | AT89S53-24PU | 1 | Микроконтроллер |
| DD2 | 74HC173 | 1 | Регистр 4-разрядный |
| DD3 | 74HC02 | 1 | 4 элемента 2ИЛИ-НЕ |
| DD4, DD5 | 74AC573 | 2 | Регистр 8-разрядный |
| DD6 | 74HC11 | 1 | 3 элемента 3И |
| DD7 | IN74AC244 | 1 | Повторитель с тремя состояниями |
| DD8 | IDT7005S55PF | 1 | Двухпортовое ОЗУ 8Кx8 |
| DD9 | 74HC32 | 1 | 4 элемента 2ИЛИ |
| DD10 | 74AC573 | 1 | Регистр 8-разрядный |
| DD11 | 74HC138 | 1 | Дешифратор 3 на 8 |
|  | **Разъёмы** |  |  |
| XS1 | Розетка PBS-2 | 1 | 2 конт. |
| XS2 | Розетка PBS-10 | 1 | 10 конт. |
| XS3 | Розетка PBS-11 | 1 | 11 конт. |

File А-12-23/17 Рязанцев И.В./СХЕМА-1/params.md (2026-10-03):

# Параметры варианта: А-12, M = 17 (ТЗ 2026)

Студент: Рязанцев И.В., руководитель: Михалин С.Н.

## Что писать

| Программа | Что |
| --- | --- |
| 1 | обработчик IRQ клавиатуры (INT0): скан матрицы, код в A или 0FFh |
| 2 | запись в кольцевой буфер (M нечётное) |
| 3 | расчёт Y2 = (12+17+X1+X2) mod 256, запись в регистр, строб T2 (таймер) (M mod 3 = 2) |

## Выводы МК

| Сигнал | Вывод |
| --- | --- |
| Строб Y1 (k = M mod 7 = 3) | P1.3 |
| Строб Y2 | P1.4 |
| IRQ клавиатуры | INT0 (P3.2), по спаду |
| Строб X2 от внешнего устройства | INT1 (P3.3), по спаду |
| CS: Индикатор | Y6 |
| CS: Клавиатура | Y1 |
| CS: Буфер (IDT7005) | Y5 |
| CS: Регистр Y2 | Y7 |
| CS_EN (разрешение дешифратора 74HC138, E2) | P3.4 — перед обращением к внешним устройствам = 1 |
| Адрес устройств | P2.5–P2.7 = A13–A15 → A0–A2 дешифратора; P2.0–P2.4 = A8–A12 |
| Свободные выходы дешифратора | Y0, Y2, Y3, Y4 |

## Карта внешней памяти (movx)

| Устройство | CS | Окно |
| --- | --- | --- |
| Индикатор | Y6 | 0C000h–0DFFFh |
| Клавиатура | Y1 | 2000h–3FFFh |
| Буфер (IDT7005) | Y5 | 0A000h–0BFFFh |
| Регистр Y2 | Y7 | 0E000h–0FFFFh |

Буфер: 1774 байт, ячейки 0A000h–0A6EDh, после 0A6EDh указатель заворачивается на начало.
Отсчёт X2 внешнее устройство пишет в ячейку-«почтовый ящик» 0BFFFh (правый порт IDT7005, адрес зашит единицами); по его стробу (прерывание) МК читает ящик и кладёт отсчёт в кольцо процедурой записи.

## Внутренняя память

| Что | Где |
| --- | --- |
| «Голова» (2 байта, абсолютный адрес) | 47h, 48h |
| «Хвост» (2 байта) | 49h, 4Ah |
| Флаг пустоты | бит 17 (11h) = 22h.1 |
| Флаг переполнения | бит 29 (1Dh) = 23h.5 |
| Стек | SP = 07h, до бит-области 20h — 24 байта |

## Время (кварц 12 МГц, машинный цикл 1 мкс)

| Интервал | Длительность | Таймер | Как отсчитывать |
| --- | --- | --- | --- |
| T1 — строб Y1 | 361 мс | Timer0 | тик 1 мс (загрузка 0FC18h) × 361, счётчик 16 бит |
| T2 — строб Y2 | 2422 мкс | Timer1 | один отсчёт, загрузка 0F68Ah |
| T3 — индикация | 3190 мс | Timer0 | тик 1 мс (загрузка 0FC18h) × 3190, счётчик 16 бит |

TMOD = 11h (оба таймера в режиме 1).

## Пульт

- Клавиатура: 3x4 (3 столбца × 4 строки).
- Индикатор: общий анод (FYS-5612BX).

## Ответы на п. 2.3 ТЗ

- Минимальное время заполнения буфера при X1 = 0: V / 4 = 1774 / 4 = 444 с.
- Функция: X1 ≠ 0 → Y2 = (G + M + X1 + X2) mod 256 = (12 + 17 + X1 + X2) mod 256 = (29 + X1 + X2) mod 256; X1 = 0 → Y2 = 0.

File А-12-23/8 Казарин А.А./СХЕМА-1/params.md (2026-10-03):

# Параметры варианта: А-12, M = 8 (ТЗ 2026)

Студент: Казарин А.А., руководитель: Михалин С.Н.

## Что писать

| Программа | Что |
| --- | --- |
| 1 | обработчик IRQ клавиатуры (INT0): скан матрицы, код в A или 0FFh |
| 2 | чтение из кольцевого буфера (M чётное) |
| 3 | расчёт Y2 = (12+8+X1+X2) mod 256, запись в регистр, строб T2 (таймер) (M mod 3 = 2) |

## Выводы МК

| Сигнал | Вывод |
| --- | --- |
| Строб Y1 (k = M mod 7 = 1) | P1.1 |
| Строб Y2 | P1.2 |
| IRQ клавиатуры | INT0 (P3.2), по спаду |
| Строб X2 от внешнего устройства | INT1 (P3.3), по спаду |
| CS: Индикатор | Y7 |
| CS: Клавиатура | Y1 |
| CS: Буфер (IDT7005) | Y5 |
| CS: Регистр Y2 | Y6 |
| CS_EN (разрешение дешифратора 74HC138, E2) | P3.4 — перед обращением к внешним устройствам = 1 |
| Адрес устройств | P2.5–P2.7 = A13–A15 → A0–A2 дешифратора; P2.0–P2.4 = A8–A12 |
| Свободные выходы дешифратора | Y0, Y2, Y3, Y4 |

## Карта внешней памяти (movx)

| Устройство | CS | Окно |
| --- | --- | --- |
| Индикатор | Y7 | 0E000h–0FFFFh |
| Клавиатура | Y1 | 2000h–3FFFh |
| Буфер (IDT7005) | Y5 | 0A000h–0BFFFh |
| Регистр Y2 | Y6 | 0C000h–0DFFFh |

Буфер: 1684 байт, ячейки 0A000h–0A693h, после 0A693h указатель заворачивается на начало.
Отсчёт X2 внешнее устройство пишет в ячейку-«почтовый ящик» 0BFFFh (правый порт IDT7005, адрес зашит единицами); по его стробу (прерывание) МК читает ящик и кладёт отсчёт в кольцо процедурой записи.

## Внутренняя память

| Что | Где |
| --- | --- |
| «Голова» (2 байта, абсолютный адрес) | 47h, 48h |
| «Хвост» (2 байта) | 49h, 4Ah |
| Флаг пустоты | бит 8 (8h) = 21h.0 |
| Флаг переполнения | бит 20 (14h) = 22h.4 |
| Стек | SP = 07h, до бит-области 20h — 24 байта |

## Время (кварц 12 МГц, машинный цикл 1 мкс)

| Интервал | Длительность | Таймер | Как отсчитывать |
| --- | --- | --- | --- |
| T1 — строб Y1 | 271 мс | Timer0 | тик 1 мс (загрузка 0FC18h) × 271, счётчик 16 бит |
| T2 — строб Y2 | 2152 мкс | Timer1 | один отсчёт, загрузка 0F798h |
| T3 — индикация | 2740 мс | Timer0 | тик 1 мс (загрузка 0FC18h) × 2740, счётчик 16 бит |

TMOD = 11h (оба таймера в режиме 1).

## Пульт

- Клавиатура: 4x3 (4 столбца × 3 строки).
- Индикатор: общий анод (FYS-5612BX).

## Ответы на п. 2.3 ТЗ

- Минимальное время заполнения буфера при X1 = 0: V / 4 = 1684 / 4 = 421 с.
- Функция: X1 ≠ 0 → Y2 = (G + M + X1 + X2) mod 256 = (12 + 8 + X1 + X2) mod 256 = (20 + X1 + X2) mod 256; X1 = 0 → Y2 = 0.

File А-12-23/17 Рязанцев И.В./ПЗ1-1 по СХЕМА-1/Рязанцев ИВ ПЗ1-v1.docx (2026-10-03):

Федеральное государственное бюджетное образовательное учреждение высшего образования

«Национальный исследовательский университет «МЭИ»

КУРСОВАЯ РАБОТА

по курсу "Микропроцессорные системы"

Проектирование микропроцессорной системы на базе МК i8051

Аппаратная часть

Выполнил: Рязанцев И.В.

Группа: А-12-23

Вариант: 17

Дата: 01.10.26

Проверил: Михалин С.Н.

Дата:

Москва, 2026

ВВЕДЕНИЕ | 3
1 Разработка аппаратной части | 4
1.1 Разработка структурной и функциональной схем | 4
1.2 Разработка микропроцессорного устройства | 5
1.3 Разработка панели управления | 8
1.4 Разработка двухпортового буфера | 10
1.5 Разработка интерфейсных устройств ввода-вывода | 13
1.6 Повышение помехоустойчивости МПС | 14
СПИСОК ЛИТЕРАТУРЫ | 15
ПРИЛОЖЕНИЕ А. Перечень элементов | 16
ПРИЛОЖЕНИЕ Б. Схема электрическая принципиальная | 17

# ВВЕДЕНИЕ

Целью курсовой работы является приобретение навыков разработки микропроцессорных систем (МПС) и оформления документации на примере проектирования системы управления объектом. МПС принимает информацию {X} об объекте управления от датчиков, вырабатывает управляющие воздействия {Y} в соответствии с заданным алгоритмом управления и подаёт их на исполнительные механизмы.

В качестве основы для построения МПС выбран микроконтроллер (МК) семейства MCS-51 — AT89S53, который реализует задачи микропроцессорного модуля. Оперативную память образуют внутреннее ОЗУ МК и внешнее двухпортовое статическое ОЗУ IDT7005, в котором организуется кольцевой буфер. Постоянная память и контроллер прерываний — внутренние узлы МК. Устройства ввода-вывода — выводы портов МК, второй порт буфера и 8-разрядный выходной регистр. Пульт управления — матричная клавиатура и семисегментный индикатор.

В работе в соответствии с ЕСКД разработаны структурная, функциональная и принципиальная электрические схемы МПС (вариант 17, группа А-12-23), выполнены расчёты элементов сопряжения и построены временные диаграммы обмена МК с буфером.

В курсовой работе разрабатывается микропроцессорная система на однокристальной ЭВМ AT89S53, которая принимает отсчёты X2 от внешнего устройства, складывает их в кольцевой буфер на двухпортовом ОЗУ IDT7005 и по ним вычисляет выходную величину Y2. Оператор работает с системой через матричную клавиатуру 3×4 (вариант нечётный, поэтому три столбца и четыре строки) и семисегментный индикатор FYS-5612BX с общим анодом. В моём варианте (группа А-12, M = 17) буфер занимает 1774 байта, Y2 считается как (29 + X1 + X2) mod 256 и выдаётся в регистр со стробом длительностью 2422 мкс на P1.4, а строб Y1 длительностью 361 мс формируется на P1.3. Все внешние устройства выбираются через дешифратор 74HC138, который включается сигналом CS_EN с вывода P3.4.

# 1 Разработка аппаратной части

## 1.1 Разработка структурной и функциональной схем

Структурная схема МПС (рисунок 1) задана техническим заданием и состоит из микропроцессорного модуля MPM, оперативного и постоянного запоминающих устройств RAM и ROM, устройств ввода-вывода IOU (входные сигналы X, выходные Y), контроллера прерываний IC и пульта управления CPAN, соединённых общей шиной.

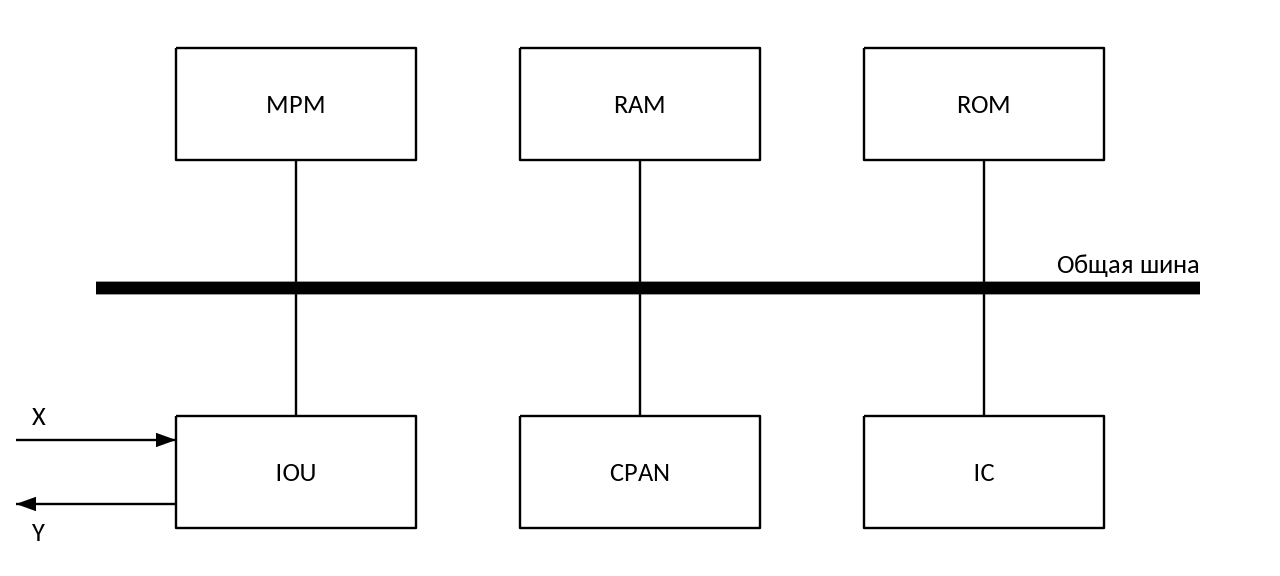
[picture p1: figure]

Рисунок 1 — Структурная схема МПС

- MPM — микроконтроллер AT89S53, 12 МГц, выполняет программу управления;
- RAM — внутреннее ОЗУ МК (переменные, указатели и флаги буфера, стек) и внешнее двухпортовое ОЗУ IDT7005 (кольцевой буфер сигнала X2);
- ROM — внутренняя флэш-память программ МК (12 Кбайт);
- IC — система прерываний МК: INT0 (клавиатура), INT1 (строб X2), таймеры 0 и 1;
- IOU — выводы портов МК (стробы Y1, Y2), второй порт буфера (ввод X2), выходной регистр Y2;
- CPAN — матричная клавиатура 3×4 и семисегментный индикатор.

Функциональная схема (рисунок 2) показывает, какими микросхемами реализованы блоки и как они связаны. Младший байт адреса и данные передаются по порту P0 и фиксируются защёлкой DD4 по сигналу ALE; старшие разряды адреса выдаёт порт P2. Три старших разряда A13–A15 поступают на дешифратор DD11, выходы которого Y0…Y7 — сигналы выбора (CS) внешних устройств; дешифратор работает только при CS_EN = P3.4 = 1.

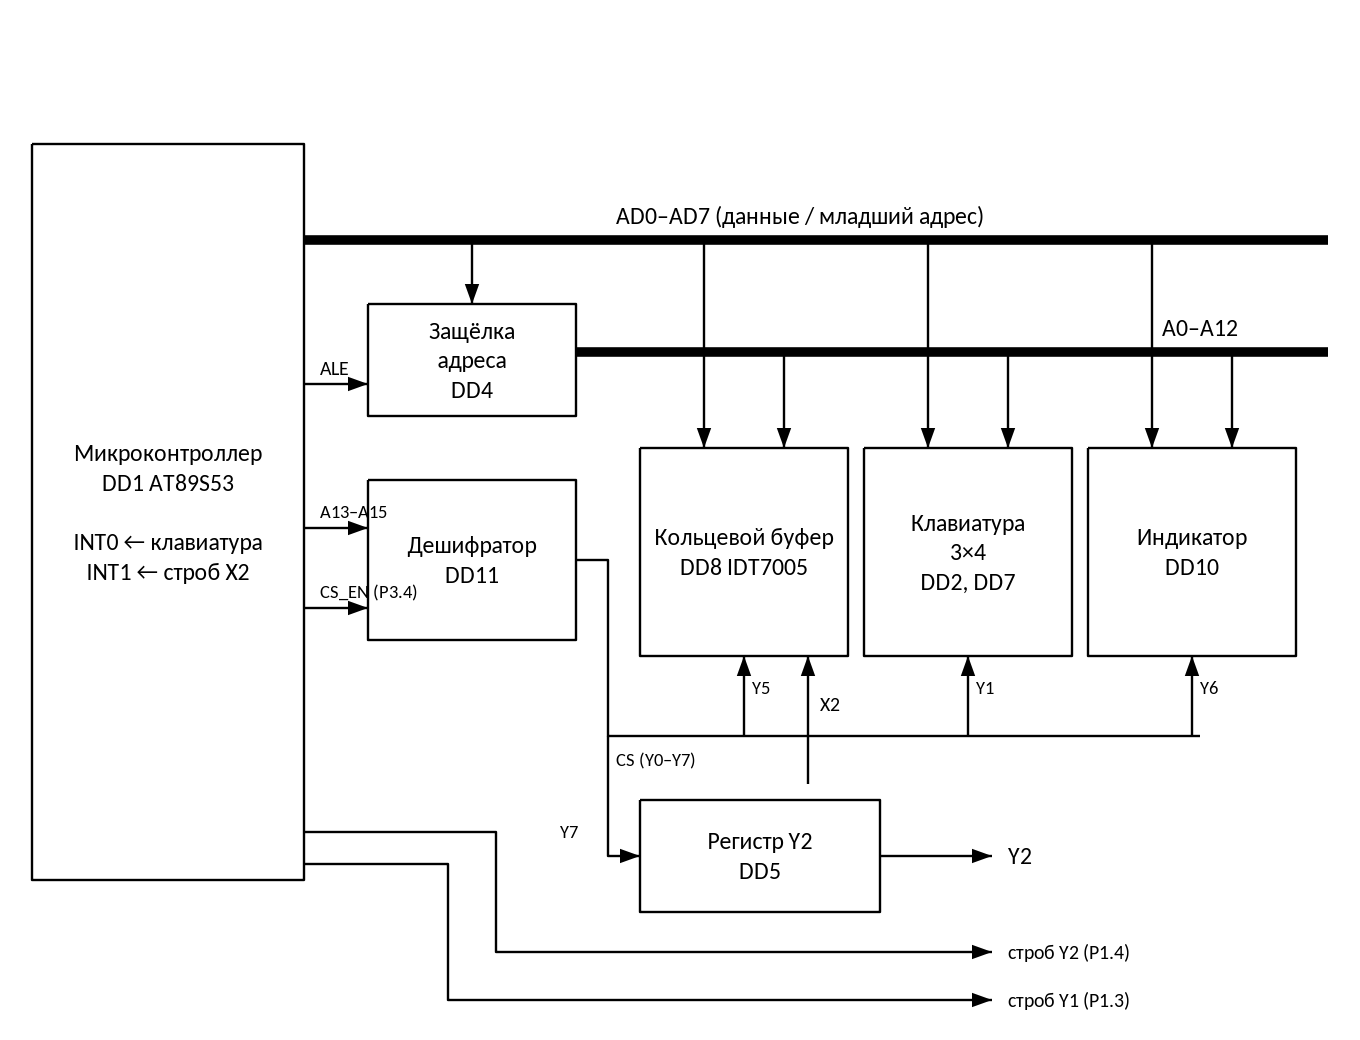
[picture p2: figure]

Рисунок 2 — Функциональная схема МПС

Распределение ресурсов микроконтроллера приведено в таблице 1.

Таблица 1 — Распределение ресурсов микроконтроллера

Ресурс | Назначение
P0 | мультиплексированная шина: младший байт адреса A0–A7 / данные D0–D7
P2.0–P2.4 | адрес A8–A12 (буфер 8 Кбайт — 13 разрядов)
P2.5–P2.7 | адрес A13–A15 — входы A0–A2 дешифратора
P1.3 | строб Y1 (активный 0), 361 мс
P1.4 | строб сопровождения Y2 (активный 0), 2422 мкс
P3.2 (INT0) | прерывание клавиатуры
P3.3 (INT1) | прерывание от строба X2
P3.4 | CS_EN — разрешение дешифратора адреса
P3.6, P3.7 | WR, RD — стробы записи и чтения внешней памяти
Таймер 0 | отсчёт T1 = 361 мс и T3 = 3,190 с (тик 1 мс)
Таймер 1 | отсчёт T2 = 2422 мкс
Внутреннее ОЗУ | указатели буфера «голова» 47h, «хвост» 49h; флаги пустоты 22h.1 и переполнения 23h.5; стек с 08h

## 1.2 Разработка микропроцессорного устройства

Схема микропроцессорного устройства приведена на рисунке 3. Тактовая частота задаётся кварцевым резонатором ZQ1 на 12 МГц; машинный цикл МК равен 12 периодам генератора, т. е. 1 мкс. Конденсаторы C1, C2 выбраны по рекомендации производителя МК (30 пФ ± 10 пФ) [1].

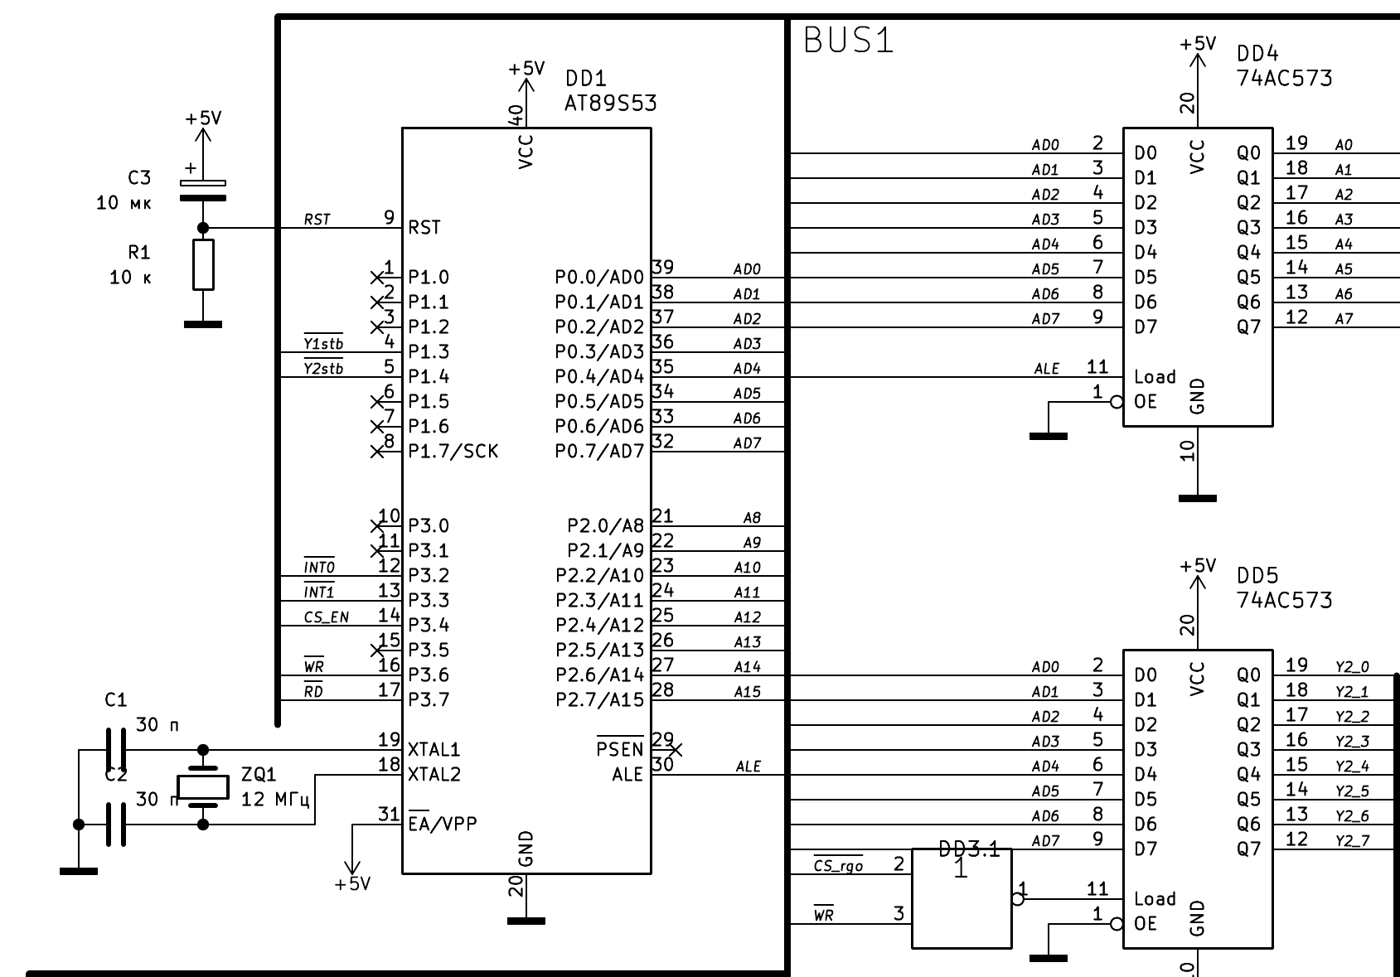
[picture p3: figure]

Рисунок 3 — Схема микропроцессорного устройства

Сброс МК выполняется RC-цепью C3–R1: при включении питания конденсатор заряжается через резистор, и на входе RST держится высокий уровень. По документации [1] для сброса достаточно высокого уровня на RST в течение двух машинных циклов при работающем генераторе. Постоянная времени цепи:

τ = R · C = 10 кОм · 10 мкФ = 100 мс

что многократно превышает 2 мкс и время запуска кварцевого генератора, поэтому сброс надёжен. Вывод EA подключён к +5 В — программа выполняется из внутренней памяти; PSEN не используется.

Защёлка DD4 (74AC573) фиксирует младший байт адреса с порта P0 по спаду ALE; дальше по P0 передаются данные. Выбор внешних устройств выполняет дешифратор DD11 (74HC138, рисунок 4): на входы A0–A2 поданы разряды адреса A13–A15, входы Ē0 и Ē1 соединены с общим проводом, вход E2 — с выводом CS_EN (P3.4). Номер выхода дешифратора для каждого устройства задан вариантом (таблица 2).

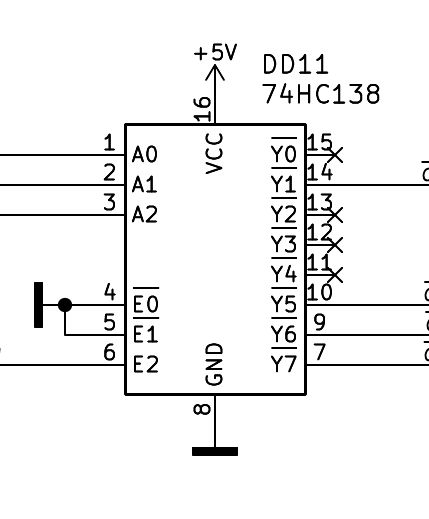
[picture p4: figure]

Рисунок 4 — Дешифратор адреса внешних устройств

Таблица 2 — Назначение выходов дешифратора

Выход | Устройство | Окно адресов
Y0 | не используется | 00h–1FFFh
Y1 | Клавиатура | 2000h–3FFFh
Y2 | не используется | 4000h–5FFFh
Y3 | не используется | 6000h–7FFFh
Y4 | не используется | 8000h–9FFFh
Y5 | Буфер (IDT7005) | 0A000h–0BFFFh
Y6 | Индикатор | 0C000h–0DFFFh
Y7 | Регистр Y2 | 0E000h–0FFFFh

Назначение выводов микроконтроллера приведено в таблице 3, карта адресного пространства — в таблице 4.

Таблица 3 — Назначение выводов микроконтроллера

Вывод | Обозначение | Назначение | Режим
1 | P1.0 | не используется | —
2 | P1.1 | не используется | —
3 | P1.2 | не используется | —
4 | P1.3 | строб Y1 | выход
5 | P1.4 | строб Y2 | выход
6 | P1.5 | не используется | —
7 | P1.6 | не используется | —
8 | P1.7 | не используется | —
9 | RST | сброс (RC-цепь) | вход
10 | P3.0 (RXD) | не используется | —
11 | P3.1 (TXD) | не используется | —
12 | P3.2 (INT0) | прерывание клавиатуры | вход
13 | P3.3 (INT1) | прерывание от строба X2 | вход
14 | P3.4 (T0) | CS_EN — разрешение дешифратора | выход
15 | P3.5 (T1) | не используется | —
16 | P3.6 (WR) | строб записи внешней памяти | выход
17 | P3.7 (RD) | строб чтения внешней памяти | выход
18 | XTAL2 | кварцевый резонатор | —
19 | XTAL1 | кварцевый резонатор | —
20 | GND | общий провод | —
21 | P2.0 | адрес A8 | выход
22 | P2.1 | адрес A9 | выход
23 | P2.2 | адрес A10 | выход
24 | P2.3 | адрес A11 | выход
25 | P2.4 | адрес A12 | выход
26 | P2.5 | адрес A13 → дешифратор, вход A0 | выход
27 | P2.6 | адрес A14 → дешифратор, вход A1 | выход
28 | P2.7 | адрес A15 → дешифратор, вход A2 | выход
29 | PSEN | не используется (программа во внутренней памяти) | —
30 | ALE | строб защёлки младшего байта адреса | выход
31 | EA | подключён к +5 В | вход
32 | P0.7 | адрес A7 / данные D7 | вход/выход
33 | P0.6 | адрес A6 / данные D6 | вход/выход
34 | P0.5 | адрес A5 / данные D5 | вход/выход
35 | P0.4 | адрес A4 / данные D4 | вход/выход
36 | P0.3 | адрес A3 / данные D3 | вход/выход
37 | P0.2 | адрес A2 / данные D2 | вход/выход
38 | P0.1 | адрес A1 / данные D1 | вход/выход
39 | P0.0 | адрес A0 / данные D0 | вход/выход
40 | VCC | питание +5 В | —

Таблица 4 — Карта адресного пространства

Диапазон адресов | Область | Назначение
0000h–2FFFh | Память программ (внутренняя флэш, 12 Кбайт) | программа управления
00h–7Fh | Внутреннее ОЗУ, прямая и косвенная адресация | банк регистров 0, стек с 08h, биты 20h–2Fh (флаги), переменные с 30h
80h–FFh | Внутреннее ОЗУ (косвенная адресация) / SFR (прямая) | регистры специальных функций
00h–1FFFh | Внешняя память данных (movx), окно Y0 | не используется
2000h–3FFFh | Внешняя память данных (movx), окно Y1 | Клавиатура (Y1)
4000h–5FFFh | Внешняя память данных (movx), окно Y2 | не используется
6000h–7FFFh | Внешняя память данных (movx), окно Y3 | не используется
8000h–9FFFh | Внешняя память данных (movx), окно Y4 | не используется
0A000h–0BFFFh | Внешняя память данных (movx), окно Y5 | Буфер (IDT7005) (Y5)
0C000h–0DFFFh | Внешняя память данных (movx), окно Y6 | Индикатор (Y6)
0E000h–0FFFFh | Внешняя память данных (movx), окно Y7 | Регистр Y2 (Y7)

## 1.3 Разработка панели управления

Клавиатура (рисунок 5) — матрица 3×4 из 12 кнопок. Столбцы Col1…Col3 задаются 4-разрядным регистром DD2 (74HC173), который записывается по адресу клавиатуры; сброс регистра подключён к RST, поэтому после включения все столбцы в нуле. Строки Row1…Row4 через повторитель DD7 (74AC244) читаются на шину данных; элемент «И» DD6 объединяет строки и формирует сигнал прерывания INT0 при нажатии любой клавиши. Диоды КД521А в цепях столбцов исключают замыкание выходов регистра при одновременном нажатии нескольких клавиш.

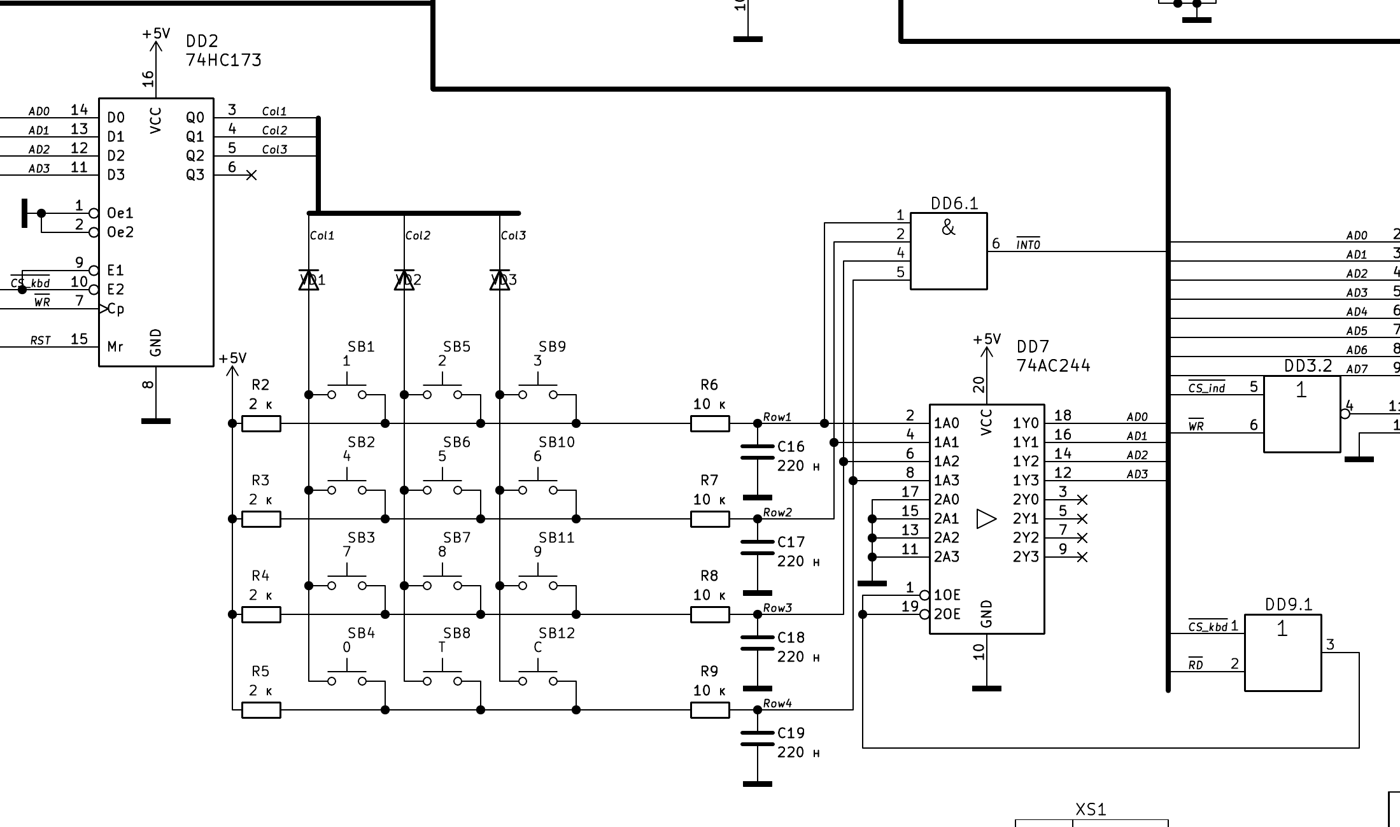
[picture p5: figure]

Рисунок 5 — Схема подключения клавиатуры

Каждая строка подтянута к питанию резистором R1 = 2 кОм (R2–R5) и соединена со входом через резистор R2 = 10 кОм (R6–R9); конденсатор C (C16–C19) вместе с R2 образует фильтр, подавляющий дребезг контактов. По методическим указаниям постоянная фильтра должна перекрывать время дребезга: 3·R2·C ≥ Tдр, где Tдр = 5 мс (ТЗ). Отсюда:

C ≥ T_др / (3 · R2) = 5·10⁻³ с / (3 · 10·10³ Ом) = 166,7 нФ

Выбран конденсатор К10-17Б 220 нФ ±10 % (C16–C19) — ближайший больший номинал. Ток через нажатую кнопку:

I = Vcc / R1 + Vcc / R2 = 5 В / 2 кОм + 5 В / 10 кОм = 2,5 мА + 0,5 мА = 3 мА

Мощность, рассеиваемая резистором R1 при удержании кнопки: P = Vcc² / R1 = (5 В)² / 2 кОм = 12,5 мВт — достаточно резисторов МЛТ-0,125. Коды клавиш (табл. 3 ТЗ) и их положение в матрице приведены в таблице 5.

Таблица 5 — Коды клавиш

Клавиша | Столбец | Строка | Код
«0» | Col1 | Row4 | 0
«1» | Col1 | Row1 | 1
«2» | Col2 | Row1 | 2
«3» | Col3 | Row1 | 3
«4» | Col1 | Row2 | 4
«5» | Col2 | Row2 | 5
«6» | Col3 | Row2 | 6
«7» | Col1 | Row3 | 7
«8» | Col2 | Row3 | 8
«9» | Col3 | Row3 | 9
«Т» | Col2 | Row4 | 10 («Тест»)
«С» | Col3 | Row4 | 11 («Сброс»)

Индикатор (рисунок 6) — семисегментный FYS-5612BX с общим анодом — сегмент горит при низком уровне на выходе регистра. Код символа записывается в регистр DD10 (74AC573), который защёлкивает его по окончании записи (Load = ИЛИ-НЕ(CS, WR), элемент DD3); выходы регистра через токоограничивающие резисторы управляют сегментами (статическая индикация: МК не тратит время на обновление).

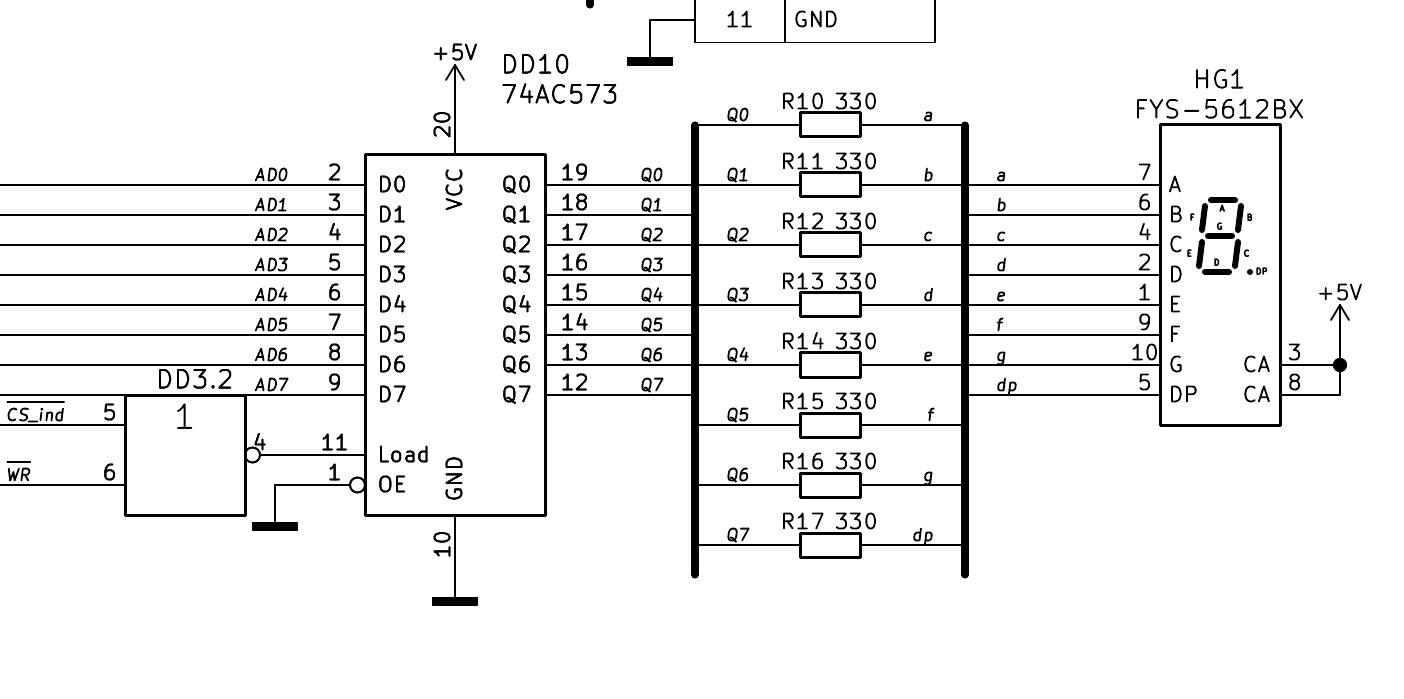
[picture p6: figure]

Рисунок 6 — Схема подключения индикатора

Сопротивление резистора сегмента (второй закон Кирхгофа, методические указания):

R = (Vcc − U_VD − U_OL) / I_VD ≥ (5,25 В − 2,0 В − 0 В) / 10 мА = 325 Ом

где Vcc = 5,25 В — напряжение питания с допуском +5 %; UVD = 2,0 В — прямое напряжение сегмента FYS-5612 [3]; UOL = 0 — падение на выходе регистра в худшем случае; IVD = 10 мА — ток сегмента, не превышающий нагрузочной способности линии (ТЗ: не более 10 мА). Выбран ближайший больший номинал ряда E24 — 330 Ом (R10–R17, МЛТ-0,125 330 Ом ±5 %). Мощность резистора P = I² · R = (10 мА)² · 330 Ом = 33 мВт.

Коды символов (табл. 2 ТЗ) приведены в таблице 6.

Таблица 6 — Коды символов индикатора

Символ | Код | dp | g | f | e | d | c | b | a
0 | 0C0h | 1 | 1 | 0 | 0 | 0 | 0 | 0 | 0
1 | 0F9h | 1 | 1 | 1 | 1 | 1 | 0 | 0 | 1
2 | 0A4h | 1 | 0 | 1 | 0 | 0 | 1 | 0 | 0
3 | 0B0h | 1 | 0 | 1 | 1 | 0 | 0 | 0 | 0
4 | 99h | 1 | 0 | 0 | 1 | 1 | 0 | 0 | 1
5 | 92h | 1 | 0 | 0 | 1 | 0 | 0 | 1 | 0
6 | 82h | 1 | 0 | 0 | 0 | 0 | 0 | 1 | 0
7 | 0F8h | 1 | 1 | 1 | 1 | 1 | 0 | 0 | 0
8 | 80h | 1 | 0 | 0 | 0 | 0 | 0 | 0 | 0
9 | 90h | 1 | 0 | 0 | 1 | 0 | 0 | 0 | 0
E | 86h | 1 | 0 | 0 | 0 | 0 | 1 | 1 | 0
выкл | 0FFh | 1 | 1 | 1 | 1 | 1 | 1 | 1 | 1
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

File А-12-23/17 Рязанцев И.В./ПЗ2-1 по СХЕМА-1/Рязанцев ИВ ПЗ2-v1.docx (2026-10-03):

| | | Проектирование микропроцессорной системы на базе МК i8051
| | | Описание программной части
| | | Листов 29

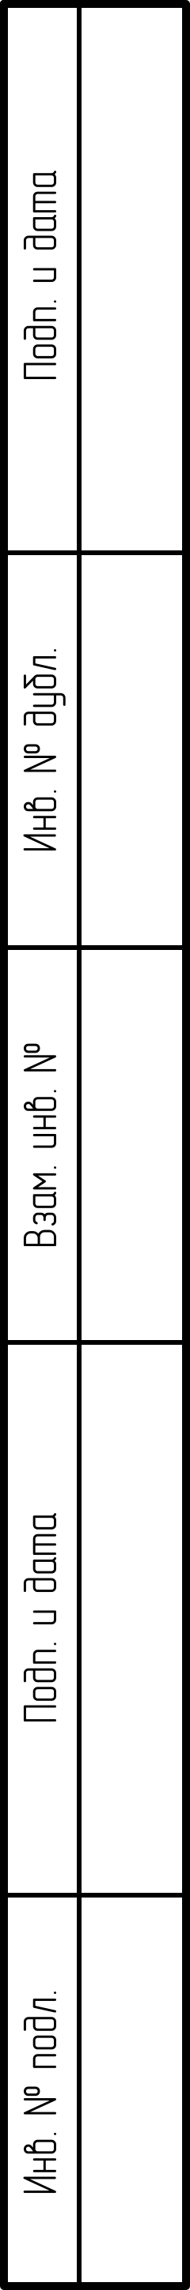
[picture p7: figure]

| | | Выполнил: Рязанцев И.В. Группа: А-12-23 Вариант: 17 Проверил: Михалин С.Н. Москва, 2026

# АННОТАЦИЯ

В данном документе приведено описание программы «Программа управления объектом», предназначенной для управления объектом микропроцессорной системой (МПС) на базе микроконтроллера AT89S53: ввода данных с клавиатуры и от внешнего устройства, формирования управляющих сигналов Y1 и Y2 и вывода информации на семисегментный индикатор.

Для функционирования данной программы необходима МПС, собранная по схеме электрической принципиальной варианта 17 (пояснительная записка по аппаратной части).

Исходным языком программы «Программа управления объектом» является ассемблер микроконтроллеров семейства MCS-51.

Основными функциями программы являются: инициализация МПС, сканирование клавиатуры, работа с кольцевым буфером на 1774 байт, выработка строба Y1 длительностью 361 мс, выработка сигнала Y2 со стробом 2422 мкс, индикация на одном разряде.

Оформление программного документа «Описание программы» произведено по требованиям ЕСПД (ГОСТ 19.101-77, ГОСТ 19.103-77, ГОСТ 19.104-78, ГОСТ 19.105-78, ГОСТ 19.106-78, ГОСТ 19.402-78, ГОСТ 19.604-78).

1 Общие сведения | 4
2 Функциональное назначение | 5
2.1 Классы решаемых задач | 5
2.2 Назначение программы | 5
2.3 Сведения о функциональных ограничениях на применение | 5
3 Описание логической структуры | 6
3.1 Алгоритм программы | 6
3.2 Структура программы с описанием функций составных частей и связи между ними | 19
3.3 Связи программы с другими программами | 20
4 Входные данные | 21
4.1 Клавиатура | 21
4.2 Сигнал X2 | 21
5 Выходные данные | 22
5.1 Характер и организация выходных данных | 22
5.2 Формат, описание и способ кодирования выходных данных | 22
ПЕРЕЧЕНЬ ПРИНЯТЫХ СОКРАЩЕНИЙ | 24
ЛИСТ РЕГИСТРАЦИИ ИЗМЕНЕНИЙ | 25
ПРИЛОЖЕНИЕ А. Листинги программ | 26

# 1 Общие сведения

Обозначение и наименование программы — «Программа управления объектом», вариант 17, группа А-12-23.

Программа низкого уровня не требует для своей работы иных программ. Исходным языком программирования является ассемблер MCS-51 (синтаксис Intel ASM51, совместимый с Keil A51 и MCU 8051 IDE).

Среда разработки и инструментальные средства: интегрированная среда Keil µVision V5 (Keil Software, пакет PK51); ассемблер — A51; компоновщик — BL51.

# 2 Функциональное назначение

## 2.1 Классы решаемых задач

- инициализация МПС;
- сканирование клавиатуры — ввод сигнала X1 (число, введённое с клавиатуры);
- формирование сигнала Y1 (строб заданной длительности);
- ввод сигнала X2 (сохранение данных в кольцевом буфере);
- формирование сигнала Y2 и сопровождающего строба;
- вывод символа на индикатор.
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

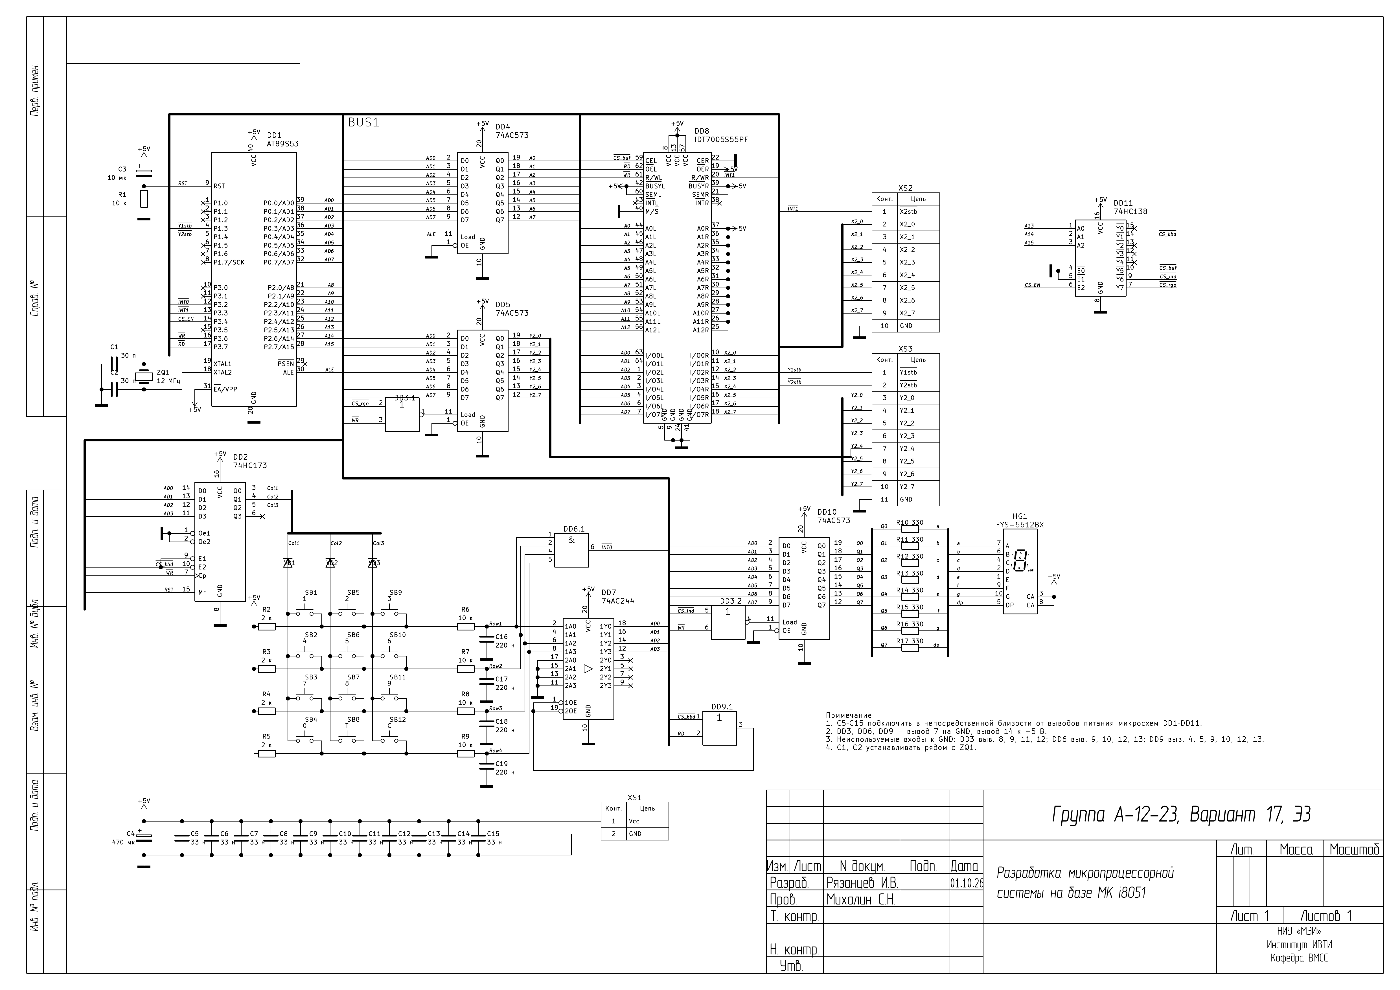
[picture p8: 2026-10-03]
А-12-23/17 Рязанцев И.В./СХЕМА-1/schematic.png

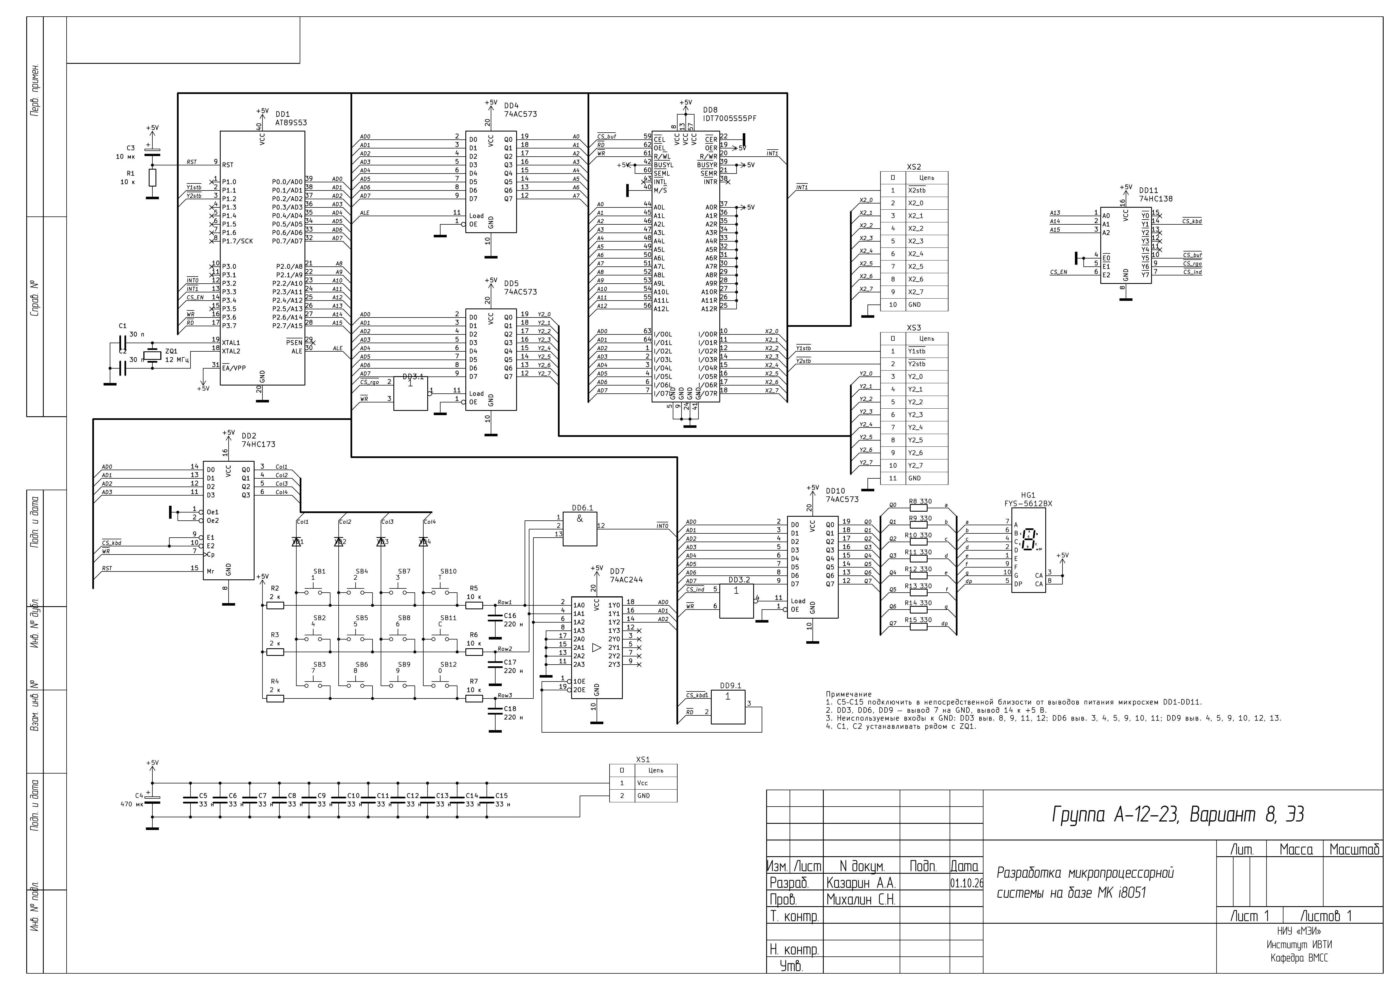
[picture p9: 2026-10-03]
А-12-23/8 Казарин А.А./СХЕМА-1/schematic.png

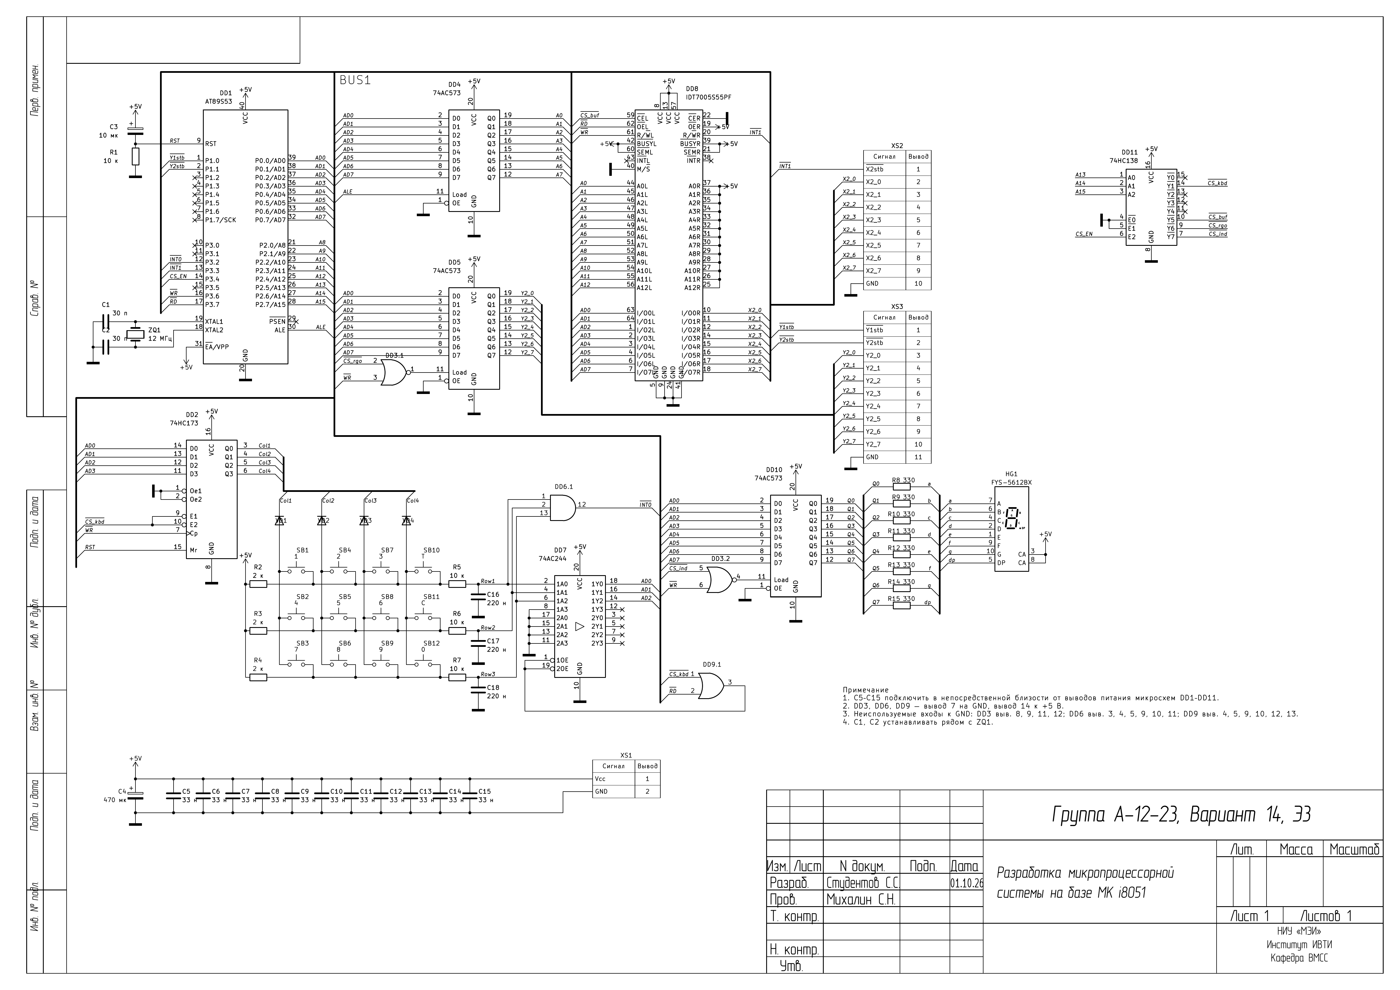
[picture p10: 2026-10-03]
А-12-23/14 Студентов С.С./СХЕМА-1/schematic.png

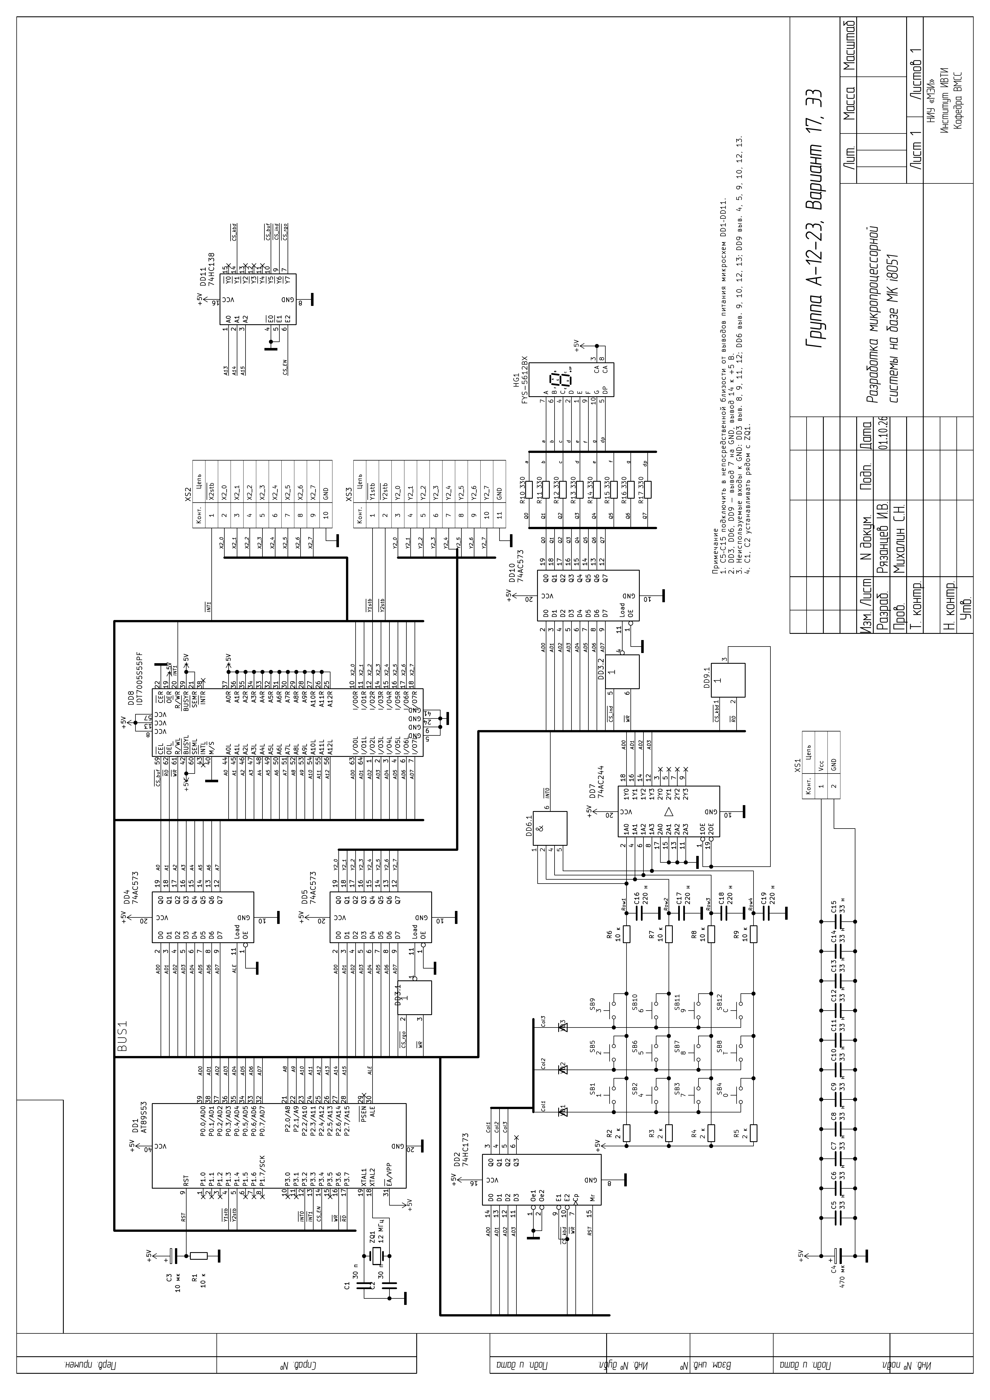
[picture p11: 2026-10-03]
А-12-23/17 Рязанцев И.В./ПЗ1-1 по СХЕМА-1/sheet.png

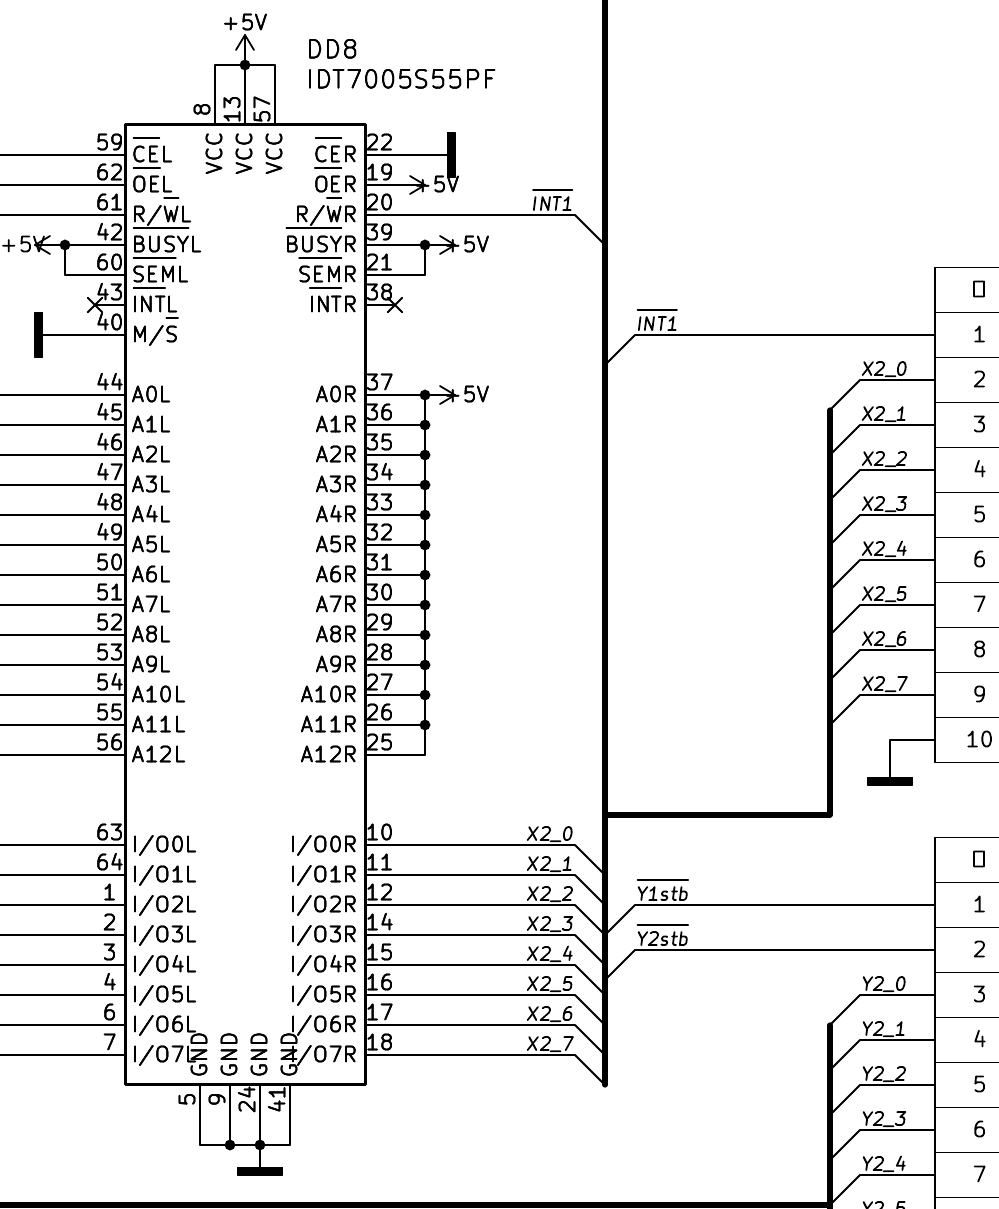
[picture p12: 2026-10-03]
А-12-23/8 Казарин А.А./ПЗ1-2 по СХЕМА-1/sch-idt.png

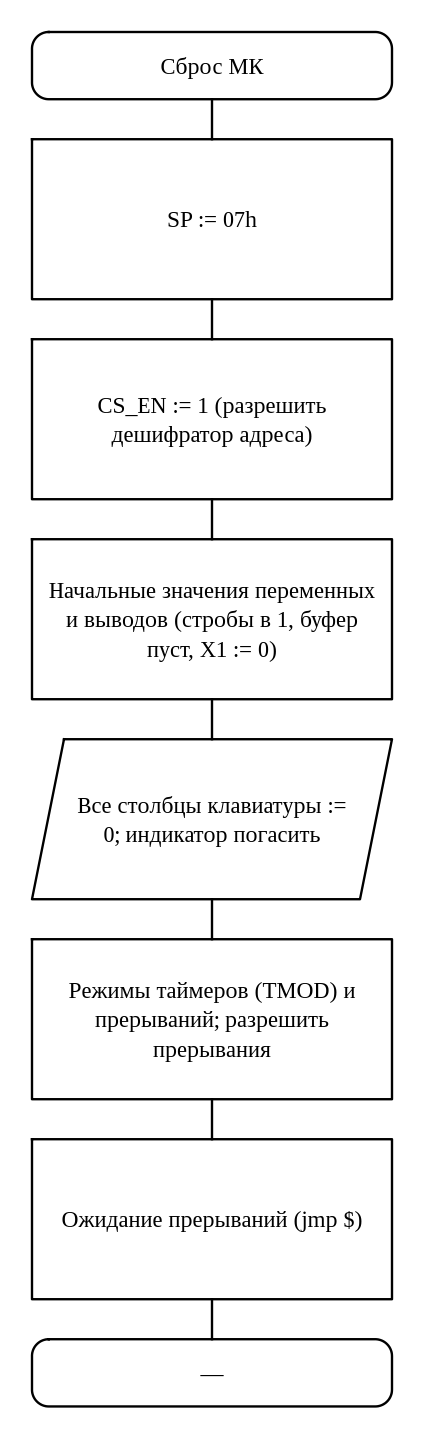
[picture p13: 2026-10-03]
А-12-23/8 Казарин А.А./ПЗ2-1 по СХЕМА-1/flow-01-init.png

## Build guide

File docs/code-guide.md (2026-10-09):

# Программы КМ-3: как писать и проверять (гайд для людей и ИИ)

ТЗ-2026, разд. 2.2 и рис. 7: три программы на ассемблере 8051 для робота кафедры (10.3.170.2:8051, после 7-й недели).
Какие именно три — зависит от варианта: `make try G=<группа> M=<номер>` → `params.md`, раздел «Программы»,
или `bin/mpscode` пишет это в заголовке отчёта. Минимум для КМ-3 — программа 1 (клавиатура).

Здесь — как писать их так, чтобы они работали на **нашей** схеме (её строит `internal/schgen`), и как проверить
до отправки: `mpscode` собирает программу своим ассемблером, проверяет правила робота и гоняет сценарии
во встроенном эмуляторе 8051 (`internal/emu51`, ставить ничего не надо) с моделями клавиатуры, буфера, индикатора, регистра Y2 и стробов.

> ✅ от `mpscode` — не гарантия «принято»: как проверяет робот, мы не знаем. Но ❌ почти всегда настоящая ошибка
> (или расхождение с соглашениями ниже — тогда смотри раздел «Если чекер неправ»).

## 0. Рецепт для ИИ: «напиши программы КМ-3 для студента X»

Делай по шагам, каждый шаг проверяй.

1. **Вариант.** Есть ли `students/<ник>/variant.yaml` (группа, M, ФИО)? Нет — создай по образцу `students/example-a12-14/`
   (ник латиницей, спроси у человека группу и номер M, если не сказаны). Числа варианта не считай — всё в `vars.inc`.
2. **Заготовки.** `make code-init S=<ник>` → `students/<ник>/code/prog1.a51`, `prog2.a51`, `prog3.a51` (+ `vars.inc` рядом,
   в git не идёт). В выводе — что должна делать каждая программа для этого варианта. Открой `vars.inc` и прочитай целиком.
3. **Пиши по одной программе**, каждую — до ✅, потом следующую (минимум для КМ-3 — программа 1):
   - только имена из `vars.inc` (`ADR_KB`, `KB_ROWS`, `F_EMPTY`, `PIN_Y2`, `T2_RELOAD_H`…), никаких «магических» адресов;
   - структура заготовки (рис. 7) не меняется: `%proc%` на `call`, `jmp $ ; %stop%`, заглушки на свободных векторах;
   - перед процедурой — комментарий: назначение, вход, выход, что портит; комментарии в строках — по смыслу;
   - пиши **свою** реализацию, не копируй `internal/codecheck/testdata/ref/` и чужие `students/*/code/` — одинаковый код у группы
     руководитель заметит.
4. **Проверка.** `make code S=<ник>` → читай `build/<группа>-23/<M>/code/report.md`. ❌ — чинить, ⚠️ — разобрать.
   Сообщения говорят, что именно не так (какая клавиша, какой указатель, сколько мкс).
5. **Грабли, на которые наступают все** (чекер их ловит):
   - столбцы клавиатуры после инициализации и после каждого опроса — в 0, иначе следующее нажатие не даст INT0;
   - строки при чтении маскировать: `anl A, #(1 SHL KB_ROWS) - 1` (старшие биты шины не подключены);
   - при INT0 по спаду — `clr IE0` в конце опроса (линия дёргается, пока перебираешь столбцы);
   - стек с `SP = 07h` растёт в банки 1–3 — не переключай банк регистров в обработчиках, сохраняй через push/pop;
   - Y2: сначала `movx` в регистр, потом строб в 0; перед запуском таймера — `clr TF1`;
   - длительности — только в прерывании таймера, в процедуре не ждать в цикле; процедура возвращается сразу;
   - буфер: голова — куда писать, хвост — откуда читать, заворот после `BUF_END − 1` (сравнивать оба байта адреса).
6. **Коммит.** Только `students/<ник>/code/prog*.a51` (и `variant.yaml`, если создавал). Push → Actions → **code** (≈ 30 с)
   проверит ещё раз; результаты — в ветке `results` → `<группа>-23/<M> <ФИО>/ПЗ2-K по СХЕМА-N/программы/` и на Яндекс-диске.
7. **Сдача.** Роботу отправляются `Фамилия ИО-код-n.txt` из `build/…/code/` (или из `results/…/ПЗ2-K по СХЕМА-N/программы/`) — в них уже
   вклеен `vars.inc`. Ответ робота записать в `notes/remarks.md` и `sessions/<дата>-<ник>.md`.

## 1. Быстрый старт

```sh
# один раз: Go 1.23+ — больше ничего (ассемблер и эмулятор 8051 свои)
make code-init S=<ник>          # заготовки students/<ник>/code/prog1.a51, prog2.a51, prog3.a51 (+ vars.inc рядом)
# … пишешь код …
make code S=<ник>               # проверка → build/<группа>-23/<M>/code/ (отчёт report.md, файлы для робота)
make code-try G=А-12 M=14 F=путь/к/prog1.a51   # любой файл под любой вариант (номер программы — из имени progN)
```

Без установки: закоммить `students/<ник>/code/progN.a51` и запушь — GitHub Actions → **КМ-3 программы и ПЗ2** проверит (без прав на запись — через Issue, команда `/км3`)
и положит результаты в ветку `results` (`<группа>/<M> <ФИО>/ПЗ2-K по СХЕМА-N/программы/`) и на Яндекс-диск; отчёт — на странице запуска (Summary).
Руками: Actions → «КМ-3 программы и ПЗ2» → Run workflow → ник.

Что в `build/<группа>/<M>/code/`:

| Файл | Что это |
| --- | --- |
| `Фамилия ИО-код-n.txt` | **то, что отправлять** (ТЗ: «Фамилия Инициалы-код-n», UTF-8): `vars.inc` вклеен, BOM снят, CRLF |
| `report.md` | отчёт по пунктам ✅ ⚠️ ❌ |
| `progN.lst`, `progN.hex` | листинг (адрес, байты, строка) и прошивка — для отладки |
| `progN.a51`, `vars.inc` | копия исходника и параметры варианта, на которых проверяли |

## 2. Файлы и оформление (правила робота, ТЗ разд. 2.2)

- Файлы: `students/<ник>/code/prog1.a51`, `prog2.a51`, `prog3.a51` — номер как в табл. 1 ТЗ. Кодировка UTF-8 без BOM.
- **Первая строка** — комментарий `; Фамилия И.О., А-12-23, 14, v1` (ФИО, группа, вариант цифрами, версия).
- `$INCLUDE (vars.inc)` — **все** адреса, биты, константы варианта бери оттуда (`ADR_KB`, `F_EMPTY`, `PIN_Y1`, `TICK_H`…),
  не пиши числа руками. Робот принимает один файл — `mpscode` вклеит `vars.inc` в `Фамилия ИО-код-n.txt` сам.
  Других `$INCLUDE` нельзя.
- Структура — рис. 7 (заготовки `make code-init` уже такие):
  1. `CSEG AT 0h` / `sjmp START`; на **всех** векторах 03h, 0Bh, 13h, 1Bh, 23h — либо обработчик, либо заглушка `nop` + `reti`;
  2. `START:` — инициализация (`mov SP, #07h`, режимы таймеров и прерываний, начальные значения, `CS_EN`);
  3. `call Процедура ; %proc%` — ровно одна такая строка, **на команде call**; в основной программе после инициализации
     или в обработчике прерывания (программа 1 — в обработчике INT0 по адресу 03h);
  4. `jmp $ ; %stop%` — ровно одна, «последняя команда»;
  5. дальше — процедуры, в конце константы и `END`.
- Пометки пишутся ровно `%proc%` и `%stop%` — без пробелов внутри, строчными, в комментарии той же строки, что и команда.
- В процедуре нет бесконечных циклов и ожидания таймера в цикле — длительности отсчитывает **обработчик прерывания таймера**.
- Комментарий ≤ 250 символов, имена ≤ 60. Перед каждой процедурой — многострочный комментарий: назначение, вход, выход, что портит.
  Комментарии по смыслу («опустить столбец 2»), а не перевод мнемоники («записать A по DPTR»).
- Timer2 и Watchdog не использовать (совместимость с i8051); T1, T3 — на Timer0, T2 — на Timer1; клавиатура — INT0, X2 — INT1.

## 3. Устройства на нашей схеме (что видит программа)

Все внешние устройства — через `movx` по адресам из `vars.inc`. Дешифратор CS работает только при **CS_EN = P3.4 = 1**
(после сброса он и так 1; если сбрасываешь P3.4 — верни перед `movx`).

**Клавиатура** (`ADR_KB`, одна ячейка на запись и чтение):
- запись: биты D0…D(`KB_COLS`−1) — столбцы Col1…ColN (регистр 74HC173). **0 — столбец опрашивается**;
- чтение: биты D0…D(`KB_ROWS`−1) — строки Row1…RowM через 74HC244, **0 — строка замкнута** на опрашиваемый столбец;
  остальные биты: при 3 строках D3 = 0 (вход на земле), D4…D7 — не подключены (любой мусор). **Маскируй** `anl A, #(1 SHL KB_ROWS) - 1`;
- ~INT0 = И всех строк: прерывание приходит, когда при опущенных столбцах замыкается любая строка. Поэтому
  **после инициализации и после каждого опроса все столбцы должны быть в 0** — иначе следующее нажатие не вызовет INT0;
- раскладка — рис. 4 ТЗ (4×3 при чётном M, 3×4 при нечётном), коды — табл. 3 («0»…«9» → 0…9, «Т» → 10, «С» → 11);
  раскладка рис. 4 ТЗ текстом (строки сверху вниз, столбцы слева направо; то же проверяет чекер):

  | 3×4 (нечётный M) | Col1 | Col2 | Col3 |   | 4×3 (чётный M) | Col1 | Col2 | Col3 | Col4 |
  | --- | --- | --- | --- | --- | --- | --- | --- | --- | --- |
  | Row1 | 1 | 2 | 3 |   | Row1 | 1 | 2 | 3 | Т |
  | Row2 | 4 | 5 | 6 |   | Row2 | 4 | 5 | 6 | С |
  | Row3 | 7 | 8 | 9 |   | Row3 | 7 | 8 | 9 | 0 |
  | Row4 | 0 | Т | С |   |  |  |  |  |  |

  нажато две и больше или ничего (помеха) → `0FFh`;
- во время опроса линия INT0 дёргается — при запуске по спаду (`IT0 = 1`) сбрось `IE0` перед выходом, иначе будет лишний вызов.

**Кольцевой буфер** (IDT7005, `BUF_START` … `BUF_END`−1, `BUF_SIZE` = V байт). Указатели — 16-битные **адреса** XRAM
(младший байт по `HEAD_L`/`TAIL_L`, старший по `HEAD_H`/`TAIL_H`), готовые для `DPL/DPH`:
- **голова** (HEAD) — ячейка, куда пойдёт следующая запись; **хвост** (TAIL) — откуда следующее чтение;
- после `BUF_END − 1` идёт `BUF_START` (заворот); сравнивать оба байта адреса;
- начальное состояние: HEAD = TAIL = `BUF_START`, `F_EMPTY = 1`, `F_OVF = 0`;
- откуда берётся X2 (полная система): правый порт IDT целиком у внешнего устройства (отдельный разъём: адрес, данные, строб
  записи — ТЗ 2.1 п. 6, 9); оно пишет отсчёт в ячейку обмена `BUF_X2IN` (вне кольца) и тем же стробом дёргает INT1. Обработчик
  INT1 сначала ждёт конца строба (`jnb P3.3, $`: прерывание — по спаду, а правый порт запоминает байт по фронту), потом читает
  `BUF_X2IN` (`movx A,@DPTR`, левый порт) и вызывает запись в кольцо. МК пишет кольцо левым портом (R/WL ← WR),
  поэтому `movx @DPTR,A` кладёт в ячейку именно A — как в процедуре записи по табл. 1 ТЗ («данные в A»);
- **чтение** (чётный M): пусто → указатели и флаги не трогать (A — любое, лучше 0); иначе A = [TAIL], TAIL дальше,
  `F_OVF = 0`, `F_EMPTY = 1`, если TAIL догнал HEAD;
- **запись** (нечётный M): [HEAD] = A, HEAD дальше, `F_EMPTY = 0`; при переполнении самый старый отсчёт выбрасывается
  (TAIL дальше) и `F_OVF = 1`. Что такое «переполнен», ТЗ не уточняет — чекер принимает **обе** политики:
  - **V − 1** (методичка, с. 14; так у принятой Осиповой): запись, после которой HEAD догнал TAIL, — уже переполнение;
  - **V**: HEAD = TAIL при `F_EMPTY = 0` — буфер полон, следующая запись затирает самый старый.
  Какую политику увидел чекер — написано в отчёте; её же опиши в ПЗ2.

**Индикатор** (`ADR_IND`, регистр 74HC573): D0…D7 = сегменты a, b, c, d, e, f, g, dp (рис. 5 ТЗ).
Общий катод — 1 зажигает, общий анод (А-08, А-09, А-12) — 0 зажигает; `IND_OFF` — «всё погашено» для твоей схемы.
Табл. 2: коды 0–9 — цифры, 10 — «E», больше — погасить. Образцы (общий катод): 0 → 3Fh, 1 → 06h, 2 → 5Bh, 3 → 4Fh, 4 → 66h,
5 → 6Dh, 6 → 7Dh (или 7Ch), 7 → 07h (или 27h), 8 → 7Fh, 9 → 6Fh (или 67h), E → 79h; у общего анода — инверсия (`xrl A, #IND_OFF`).

**Регистр Y2** (`ADR_Y2`, 74HC573) и **стробы**: `PIN_Y1`, `PIN_Y2` — выводы P1, активный уровень 0, пассивный 1.
Y2 сначала записывается в регистр, **потом** строб 0 на T2 (данные должны быть в регистре к началу строба).
Для программы 3 с Y2 переменные — **`X1` и `X2`** в DSEG (`X1: DS 1`, `X2: DS 1`): чекер кладёт в них значения по имени.

Таймеры (кварц 12 МГц, 1 МЦ = 1 мкс): `TICK_H:TICK_L` — перезагрузка Timer0 на 1 мс, `Y1_TICKS`/`T3_TICKS` — сколько тиков;
`T2_RELOAD_H:L` — Timer1 на весь строб T2. Режим 1 (16 бит) перезагружается в обработчике — потеря на входе в прерывание
≈ 5–8 мкс на тик; на 3000 тиков это 0,5–0,8 % (допуск чекера 1 %). Компенсируй (прибавляй к TL0 текущее значение + поправку) или бери режим 2.

## 4. Что проверяет `mpscode`

Всегда: UTF-8, первая строка, комментарии ≤ 250, Timer2/Watchdog, сборка, файл для робота собирается в те же байты,
`%proc%`/`%stop%`, заглушки на всех векторах, описание процедуры; предупреждение, если прокомментировано меньше трети команд.

| Программа | Сценарии (ОЗУ после сброса случайное, как у настоящего МК; 12 МГц, 1 МЦ = 1 мкс) |
| --- | --- |
| 1 — клавиатура | инициализация доходит до `%stop%`, разрешены EA и EX0, столбцы в 0; каждая из 12 клавиш → код; две клавиши в строке, в столбце, вразброс → 0FFh; INT0 без нажатия → 0FFh; после каждого опроса столбцы снова в 0 |
| 2 — буфер, чтение | начальное состояние; пустой; 1 и 3 отсчёта; заворот хвоста; последний отсчёт на границе; после переполнения (сброс `F_OVF`); ничего лишнего в XRAM не пишется |
| 2 — буфер, запись | в пустой; в непустой; заворот головы; голова догоняет хвост (определяется политика V или V−1); переполнение и переполнение на границе по этой политике; запись не выходит за буфер |
| 3 — индикатор (M mod 3 = 0) | коды 0–10 → сегменты, 11 и 0FFh → погашен; гашение через T3; повторный вызов перезапускает T3 |
| 3 — строб Y1 (M mod 3 = 1) | два вызова: спад на `PIN_Y1`, длительность T1; процедура возвращается сразу (≤ 10 мс), а не ждёт конец строба; другие выводы P1 не трогаются |
| 3 — Y2 (M mod 3 = 2) | шесть пар X1, X2 (с X1 = 0 и переполнением суммы): одна запись в регистр, значение, запись раньше строба, строб T2 |

Для всех: каждое обращение `movx` — при `CS_EN = 1`; обработчики выходят по `RETI`; заглушки — ровно `nop / reti`;
у каждой процедуры есть комментарий-заголовок; переменные DSEG не занимают адреса «головы», «хвоста» и байты флагов;
обработчики таймеров сохраняют A и PSW (⚠️); в инициализации есть `mov SP, #07h` (⚠️, ТЗ разд. 2.2);
стек за все сценарии не заходит на переменные, «голову», «хвост» и байты флагов (❌); банк 1–3 при стеке с 07h (⚠️);
имена ≤ 60 символов (❌ при сборке); таймеры — по ТЗ (T1, T3 — Timer0, T2 — Timer1, ⚠️);
программа 1: при удержании клавиши обработчик не вызывается повторно (⚠️), опрос не дольше 2 мс (⚠️).
Допуски: T1, T3 — ±1 % (не меньше ±1 мс), ⚠️ при отклонении > 0,2 %; T2 — ±1 % (не меньше ±20 мкс).

Не проверяется (смотрят люди): смысл комментариев, алгоритмы и блок-схемы в ПЗ2, соответствие кода ПЗ.

## 5. Порядок работы для ИИ

1. Прочитай `AGENTS.md`, `RULES.md`, этот файл, свой `params.md` (`make try …` или ветка `results`).
2. `make code-init S=<ник>` — заготовки. Пиши **свою** реализацию: `internal/codecheck/testdata/ref/` — эталоны,
   на которых проверяется сам чекер; копировать их студентам нельзя (руководитель увидит одинаковый код у всей группы).
3. `make code S=<ник>` → читай `report.md`, чини, повторяй до ✅. ⚠️ — разбери, не игнорируй.
4. Коммить только `students/<ник>/code/*.a51` (не `vars.inc`, не `build/`). Отправлять роботу — `Фамилия ИО-код-n.txt` из `build/…/code/`.
5. Итоги — в `sessions/<дата>-<ник>.md`; ответ робота («принято» или текст ошибки) — туда же и в `notes/remarks.md`:
   это единственный способ узнать, как робот проверяет на самом деле.

## 6. Если чекер неправ

Чекер — общая память группы. Не подгоняй его под свою программу. Если уверен, что он ошибается (или робот ответил иначе):
докажи по ТЗ / ответу робота / даташиту, запиши в `docs/changelog.md` по протоколу `RULES.md`, поправь
`internal/codecheck` вместе с тестом (эталон должен проходить, «поломка» — падать: `check_test.go`) и `make test`.

Расширения Keil A51, которые понимает наш ассемблер: `AR0`…`AR7` (прямой адрес R0…R7 банка из `USING n`, по умолчанию 0 —
`push AR0`, `mov AR7, A`), `имя EQU R7`, метка с пробелом перед «:», `IF/ELSE/ENDIF`.

Устройство: `internal/asm51` — ассемблер (синтаксис A51/ASEM; байты сверяются с MCU 8051 IDE в CI —
`scripts/mide_crosscheck.sh`; в CI — джоба `mide`: Actions → «КМ-3 программы и ПЗ2» → Run workflow с галочкой), `internal/emu51` — эмулятор 8051 (сверен с ucsim s51: `MPS_S51_DIFF=1 go test ./internal/emu51`, нужен `brew install sdcc`), `internal/sim51` — управление s51 для этой сверки, `internal/codecheck` — правила, модели устройств
и сценарии, `cmd/mpscode` — CLI, `.github/workflows/km3.yml` — CI. Ресерч инструментов — `docs/research/asm-tools.md`.

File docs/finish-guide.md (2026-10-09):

# Доводка курсача: материалы, «своими словами», защита, замечания руководителя

Для нейронки, которая ведёт студента, и для самого студента. Читать, когда джобы дали ✅ по КМ-1…КМ-3 (или раньше —
когда студент спрашивает «а что это за узел» или приносит замечание). Генератор делает отчёты **правильными**, но
**одинаковыми по формулировкам** у всей группы, а студент свою работу ещё не понимает. Этот гайд — про то, как это исправить.

> **🤖 Нейронке: после последнего ✅ не заканчивай сессию.** Сама предложи студенту продолжить (текст — раздел 5) и веди
> по шагам: материалы → пересказ отчёта → подготовка к защите → правки руководителя по мере прихода.

## 1. Какие материалы смотреть

**Приоритет источников** (`RULES.md` §3): ТЗ-2026 > методичка-2026 > лекции > даташит > принятые работы прошлых лет.
Работы прошлых лет делались по другому ТЗ (АЦП, UART, 2 разряда индикатора) — `docs/research/remarks-and-defense.md`, разд. D.

### Что лежит в репо (есть в любой копии)

| Что | Где | Зачем |
| --- | --- | --- |
| ТЗ и методичка | `docs/source/ТЗ-2026.pdf`, `docs/source/методичка-2026.pdf` | задание, требования к ПЗ, рис. 7 (какие программы), Прил. А/Б |
| Лекции курса | `docs/source/лекции-МПС-ч1.pdf`, `docs/source/лекции-МПС-ч2.pdf` | теория по узлам схемы, 8051, прерываниям; ссылки «лекц. ч2 с. 4» в выжимках — на них |
| Шаблон ПЗ2 руководителя | `docs/source/шаблон-ПЗ2-ПрилБ.docx` | какие куски ПЗ2 — «от руководителя» (их не пересказывать, см. 2.1) |
| Принятые работы | `docs/source/старая-схема-Э3.png`, `старая-ПЗ1-v1.docx`, `старая-спецификация.png` | как выглядело принятое без замечаний (ТЗ-2025) |
| Даташиты | `docs/group/` — AT89S53, IDT7005, FYS-5612, 74ACT573, 1554ЛИ3, конденсаторы | параметры микросхем: только отсюда, не по памяти |
| Параметры варианта | `params.md`, `vars.inc` в папке `СХЕМА-N` (ссылки в карточке КМ-1) | все числа варианта: адреса, CS, биты, таймеры, программы |
| Отличия ТЗ-2026 | `docs/research/tz-2026.md` | что поменялось (дешифратор, 33 н, G в Y2…) |
| Типовые замечания и защита | `docs/research/remarks-and-defense.md` — A (схема), B (ПЗ, код), **C (банк вопросов защиты и теста КМ-4)** | проверить отчёт до сдачи, готовиться к защите |
| Почему схема такая | `docs/research/schematics-review.md`, `variants-lectures.md` (узлы по лекциям, со страницами) | объяснить узел и ответить «почему так» |
| Что хочет руководитель и робот в коде и ПЗ2 | `docs/research/code-pz2-requirements.md` | RETI, контекст, стек, комментарии |
| Структура ПЗ1 принятых работ | `docs/research/pz1-structure.md` | откуда разделы ПЗ1 |
| Гайды | `docs/pz-guide.md`, `docs/code-guide.md` | как устроены ПЗ и программы |
| Замечания и вопросы группы | `notes/remarks.md`, `notes/defense.md`, `students/<ник>/remarks.md` | что уже возвращали и спрашивали |

### Работы прошлых лет, тесты — не в git

Работы 2014–2025, тесты, лабораторные — по ссылкам в `docs/materials.md`; у того, кто их скачал, лежат в `docs/prev/<источник>/`
(папка в `.gitignore`). Как быть нейронке:

1. Сначала — ТЗ, методичка и лекции из `docs/source/` (номер страницы в выжимках = страница PDF).
2. Есть `docs/prev/` локально — можно открыть первоисточник; нет — бери выжимки `docs/research/*.md`.
3. Нужен факт, которого нет ни там, ни там, — так и скажи студенту и попроси файл или ссылку; **не придумывай**.

Где в лекциях наш курсач (по выжимкам): ч2 с. 4 — тактирование и RC-сброс; ч2 с. 16–18 — прерывания, RETI, стек;
ч1 с. 10–11 — оформление Э3 по ГОСТ (УГО, шины, отводы); ч1 с. 76 — сброс внешних устройств сигналом RST.

### Карта «тема → что читать» (для объяснений студенту)

| Тема (раздел ПЗ) | Сначала | Потом |
| --- | --- | --- |
| Шина, защёлка, дешифратор, карта адресов (ПЗ1 1.2) | `params.md`, ТЗ табл. 1 | `remarks-and-defense.md` C.3, даташит 74ACT573 |
| Кварц и сброс (ПЗ1 1.2) | `variants-lectures.md` разд. 1–2 | даташит AT89S53 (RST, XTAL) |
| Клавиатура и антидребезг (ПЗ1 1.3) | `variants-lectures.md`, C.5 | `schematics-review.md` |
| Индикатор, резистор сегмента (ПЗ1 1.3) | C.6, даташит FYS-5612 | — |
| Буфер IDT7005 (независимый доступ: правый порт на отдельном разъёме), времена (ПЗ1 1.4) | `tz-2026.md`, даташит IDT7005 с. 8–9 | C.3 |
| Прерывания, таймеры, стек (ПЗ2, код) | C.4, C.8, `code-pz2-requirements.md` | лекции ч2 с. 16–18 |
| Оформление (Э3, ПЗ, схемы алгоритмов) | методичка-2026, C.9 | `variants-gost-parts.md` |

## 2. «Своими словами»: что переписывать в отчёте

Каждый абзац ПЗ относится к одной из трёх групп. Нейронка сначала показывает студенту эту раскладку по его отчёту, потом
переписывает по одному разделу.

### 2.1. Не трогать

- **Из шаблона руководителя и ЕСКД/ЕСПД:** титульный лист; **аннотация ПЗ2** (это фразы Прил. Б ТЗ); названия и номера разделов;
  содержание; в ПЗ2 — разд. 1 «Общие сведения» (фразы шаблона), 2.1 «Классы решаемых задач» (список из шаблона),
  первый абзац 2.2 («МПС принимает информацию {X}…»), 3.3 «Связи с другими программами»; перечень сокращений;
  лист регистрации изменений; список литературы; приложения (перечень элементов, схема Э3, листинги).
- **Факты:** числа и единицы, формулы и расчёты, таблицы, рисунки и подписи к ним, позиционные обозначения (DD4, R1…),
  имена сигналов и выводов, адреса, ссылки [1], [2], ответы на п. 2.3 ТЗ.
- **Термины:** «строб», «защёлка», «дешифратор», «кольцевой буфер», «голова/хвост», «антидребезг» — не заменять синонимами.

### 2.2. Переписать через репо — сохраняется при пересборке, делать в первую очередь

| Где в отчёте | Где править | Что писать |
| --- | --- | --- |
| ПЗ1, введение — абзац о системе | `pz/pz1.md`, `p1.intro` | что делает именно эта МПС, чем вариант отличается |
| ПЗ1 1.4 — обмен через буфер | `pz/pz1.md`, `p1.buffer`, `p1.timing` | механизм своими словами, свой вывод по временам |
| ПЗ2 3.1 — общий алгоритм | `pz/pz2.md`, `p2.alg` | 1–2 абзаца со ссылками на рисунки |
| ПЗ2 3.1 — пояснение к каждой схеме алгоритма | `pz/pz2.md`, `flow.<имя>` | своё пояснение вместо генерируемого «Схема … выполняется так: …» |
| ПЗ2 3.2 — описание подпрограмм | комментарии в шапке процедур `code/prog*.a51` (`Назначение`, `Вход:`, `Выход:`, `Портит:`) | эта таблица берётся из кода |
| ПЗ2 — среда разработки, коды ошибок | `pz/pz2.md`, `p2.ide`, `p2.errors` | своя среда, реакция на ошибки |

Пустой `flow.<имя>` — в документ идёт автопересказ схемы, **одинаковый у всех с этим алгоритмом**. 13 пояснений — самый
крупный кусок «одинакового» текста ПЗ2, и его можно закрыть через репо. Начинай с них (3–6 предложений на схему: что
делает алгоритм и **почему так** — например, почему столбцы после опроса опускают в 0, почему строб запускают после записи данных).
Прислать: Issue — `/км3` + `pz2.md` целиком (и `prog*.a51`, если правил комментарии); с правом пуша — коммит в `students/<ник>/`.

### 2.3. Переписать в docx — в самом конце, сохраняется только в копии студента

Сгенерированная проза, у которой нет места в `*.md`:
- **ПЗ1:** общие абзацы введения («Целью курсовой…», «В качестве основы…», «В работе в соответствии с ЕСКД…»);
  1.1 — текст о структурной и функциональной схемах; 1.2 — текст о кварце, сбросе, защёлке, дешифраторе (вокруг расчётов);
  1.3 — текст о клавиатуре и индикаторе; 1.4 — описание подключения IDT7005 и вывод по таблице времён; 1.5; 1.6.
- **ПЗ2:** 2.2 после первого абзаца; 2.3 (кроме фразы шаблона про AT89S53); 3.2 — вводный абзац; 4.1, 4.2; 5.1, 5.2 — текст
  (не таблицы и не числа).

Почему в конце: **каждая пересборка ПЗ перезаписывает docx**. Порядок такой: схема, код и `*.md` больше не меняются →
вышел последний `ПЗ1-K` / `ПЗ2-K` → пересказ в Word → студент сохраняет копию у себя → PDF.
Если потом пришло замечание и ПЗ пересобрали — правки из Word переносятся в новый docx заново (держать список «было → стало»).

### 2.4. Как нейронка пересказывает

1. Берёт последний docx из `ПЗ1-K…`/`ПЗ2-K…` (ветка `results` или ссылка в карточке; текст — `pandoc -t plain файл.docx`,
   или «— просмотр.pdf» → `pdftotext`) и выписывает абзацы группы 2.3 по разделам.
2. На каждый абзац даёт пару **«было → стало»**, по одному разделу за раз; студент вставляет в Word и подтверждает.
3. Правила пересказа:
   - смысл, факты, числа, обозначения, ссылки на рисунки и таблицы — те же; ничего не добавлять «для объёма»;
   - меняется построение: порядок мыслей внутри абзаца, деление на предложения, связки («поэтому», «за счёт того, что»),
     действительный залог вместо страдательного и наоборот;
   - голос студента: проще и короче, без канцелярита и без оборотов, которые выдают нейронку («важно отметить»,
     «играет ключевую роль», «таким образом, можно сделать вывод»);
   - у разных студентов — по-разному: **не бери** чужие `students/*/pz/` и свои прошлые пересказы для других студентов за образец;
     манеру спроси у студента (как он сам объяснил бы узел) и пиши от неё;
   - проверка: в новом абзаце не должно остаться ни одного предложения, совпадающего с исходным дословно.
4. Пока пересказываешь, проверяй сам отчёт: не противоречит ли текст схеме и коду (номиналы на схеме = в перечне = в расчётах,
   замечание из `remarks-and-defense.md` A.3). Нашёл ошибку генератора — скажи студенту, поправь через репо, а не в Word.

## 3. Подготовка к защите и тесту КМ-4

Нейронка предлагает студенту пройти по его работе вопросами — по одному узлу за раз, с числами **его** варианта (`params.md`):
1. Узел за узлом (по разделам ПЗ1): что делает, почему так, что будет, если убрать (например: зачем диоды в клавиатуре,
   почему OE у 244 — ИЛИ(CS, RD), откуда τ сброса, сколько ячеек в буфере и почему).
2. Банк вопросов — `docs/research/remarks-and-defense.md`, разд. C; ловушки теста — C.10 (там же неверные «популярные» ответы, помечены [!]).
3. Код: студент объясняет каждую свою программу построчно — что в стеке, зачем `reti`, какие регистры портит,
   откуда константы таймеров. Глубина стека и время заполнения буфера — в ПЗ2, их надо уметь пересчитать.
4. Сначала спроси — студент отвечает сам; потом поправь со ссылкой на источник (файл и раздел). Не выдавай ответы списком «на заучить».
Новый вопрос с реальной защиты — в Issue/`notes/defense.md` (дата — ник — вопрос — ответ — реакция).

## 4. Замечания руководителя: цикл правок

Замечания приходят по мере сдачи КМ. На каждое:

1. **Записать дословно**: Issue — `/замечание КМ-N <как написал руководитель>`; с правом пуша — `make remark S=<ник> KM=N TEXT="…"`.
2. **Разобрать, чьё оно** (подробно — `AGENTS.md`, «Замечания руководителя»):
   - только этот студент: номинал, тип, строка перечня, «Примечание», расположение блоков → `/правка` + `fixes.yaml`;
   - текст ПЗ → `pz1.md`/`pz2.md` (или в docx, если места в `*.md` нет — тогда держать в списке «было → стало»);
   - код → `prog*.a51`, `/км3`;
   - ошибка генератора (будет у всех: связь на схеме, правило ГОСТ, расчёт) → не обходить у себя; написать в Issue, что это
     общая ошибка, — её чинят в генераторе (`RULES.md`, changelog, выжимка в `notes/remarks.md`).
   - Непонятно, что имел в виду руководитель, — не угадывай: предложи студенту уточнить и сформулируй вопрос.
3. **Пересобрать в порядке**: правка схемы → новая `СХЕМА-N` → ПЗ1 и ПЗ2 по ней пересобираются сами (`ПЗ1-K по СХЕМА-N`).
   Правки из Word (2.3) после пересборки переносятся заново.
4. **Отчитаться студенту**: что поменяли и где, номера новых прогонов, что отправить повторно и с какой темой письма
   (бот пишет в карточке; сам ничего никуда не отправляй), и в `remarks.md` — «Что сделали», «Статус: исправлено».
5. **Сверить остальное**: похожее замечание может касаться и других мест (номинал в схеме → перечень → расчёт в ПЗ1);
   прогони список `remarks-and-defense.md` A–B по отчёту ещё раз.

## 5. Что нейронка пишет студенту после ✅ (образец, своими словами)

> Всё собрано: схема, ПЗ1, ПЗ2 и программы проходят проверку. Теперь работа правильная, но тексты ПЗ у всей группы
> из одного шаблона, а на защите спросят, почему всё устроено так. Предлагаю дальше, по шагам:
> 1. **Пояснения к алгоритмам ПЗ2 своими словами** — 13 схем, через репо, переживут пересборку (минут 20–30).
> 2. **Пересказ общих абзацев ПЗ1 и ПЗ2** — по разделам, «было → стало», вставишь в Word перед PDF. Лучше в самом конце.
> 3. **Разбор схемы и кода к защите** — по узлам, с числами твоего варианта; покажу, что читать (ТЗ, лекции, даташиты).
> 4. **Замечания руководителя** — как придут, присылай дословно: запишем, разберём, пересоберём и скажу, что отправить заново.
>
> С чего начнём?

Дальше — по выбору студента, по одному маленькому шагу с проверкой (прислал → карточка бота ✅ → следующий раздел).
Итоги сессии — `sessions/<дата>-<ник>.md` (если есть право пушить) или последним комментарием в Issue.

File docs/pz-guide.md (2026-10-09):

# Пояснительные записки: что генерируется, что дописывает студент (гайд для людей и ИИ)

Работа сдаётся по контрольным мероприятиям, у каждого — своя джоба в GitHub Actions:

| КМ | Что сдаётся | Джоба | Что делает джоба |
| --- | --- | --- | --- |
| КМ-1 | схема Э3 (PNG) + черновик перечня (микросхемы, разъёмы) | **КМ-1 схема и перечень** (`km1.yml`) | схема по варианту, ERC, перечни ПЭ3 |
| КМ-2 | ПЗ1 — аппаратная часть | **КМ-2 ПЗ1** (`km2.yml`) | схема + ПЗ1 в docx: структурная и функциональная схемы, фрагменты Э3 по узлам, расчёты из перечня, таблицы, временные диаграммы, перечень, Э3 |
| КМ-3 | ПЗ2 — программная часть + три программы | **КМ-3 программы и ПЗ2** (`km3.yml`) | проверка программ, файлы для робота, ПЗ2 в docx |
| КМ-4 | защита | — | банк вопросов — `docs/research/remarks-and-defense.md` |

Результаты — ветка `results` → `<группа>-23/<M> <ФИО>/ПЗ1-K по СХЕМА-N/` и `ПЗ2-K по СХЕМА-N/` (в нём `программы/`) и Яндекс-диск, так же. Каждый прогон — новая папка своего вида.

## Принцип

Документ = **генерируемое** (таблицы, расчёты, рисунки, листинги — всё, что можно посчитать или нарисовать точно) +
**текст студента** в `students/<ник>/pz/pzN.md` по местам «ДОПИШИ». Генерируемое пересобирается при каждом прогоне
(поменялся код — поменялись таблица подпрограмм, листинги, глубина стека), текст студента не перетирается.
Незаполненное место в docx — жёлтый абзац «✍ ДОПИШИ (ид …)»; список незаполненных — в `report.md` рядом с docx.
PDF студент делает сам (Word/LibreOffice → «Сохранить как PDF»), когда допишет и проверит.

**Вид документа** — по образцам принятых работ, у группы не одинаковый (выбирается по группе и варианту; задать явно — `pz_style: A|B|C`
в `students/<ник>/variant.yaml`): A — как Осипова 2025 (номер и «Курсовая работа, МПС ч2» сверху, заголовки прописными по центру,
«Рис. 3.1.»), B — как Базарнов 2023 / Женюх 2022 (номер снизу, «Рис. N.»), C — ГОСТ 7.32 («Рисунок N —», «Таблица N —»).
Титул ПЗ2 — по шаблону Прил. Б (боковые графы), ПЗ1 — по Прил. А. «Листов N» и номера страниц в содержании джоба вписывает по рендеру
LibreOffice. **Блок-схемы** рисуются одним из 5 шрифтов и с разными пропорциями — тоже по группе и варианту.
ФИО, группа, вариант, преподаватель — из `variant.yaml` (форма Issue): на титул, в колонтитулы, в имена файлов.

## Вёрстка docx — только то, что понимают все просмотрщики

ПЗ открывают не только в Word: во встроенных просмотрщиках приложений и облаков, в LibreOffice. Поэтому генератор (`internal/pz`)
пользуется только приёмами, которые понимают все, и проверяет это тестами:
- «с новой страницы» — явный разрыв первым элементом заголовка (не свойство стиля pageBreakBefore и не отдельный абзац-разрыв —
  первое не видят простые просмотрщики, второе даёт пустой лист в Word);
- шапка, содержание, титул — таблицы без рамок (не табуляции «по центру/вправо»); боковые графы — картинкой (не повёрнутый текст);
- титул ниже поля страницы с запасом (235 из 257 мм) — разные программы рисуют высоту строк чуть по-разному;
- порядок элементов OOXML по схеме (`CheckOOXML`, нормализатор после pandoc) — Word строже LibreOffice;
- номера страниц и «Листов N» — числами по рендеру LibreOffice в CI (поля Word простые просмотрщики не считают).

## Своими словами — обязательно перед сдачей

Общие абзацы ПЗ (введение, описания узлов, пояснения к схемам алгоритмов, выводы) генерируются **из одного шаблона для всех** —
у соседей по группе отличаются только числа и обозначения. Сдавать так нельзя: одинаковые формулировки сразу видны.

1. **Заполнить все «ДОПИШИ»** (`students/<ник>/pz/pz1.md`, `pz2.md`; через Issue — `/пз1`, `/пз2` + весь файл). Это свой текст с самого начала.
2. **В самом конце** — когда схема, код и тексты «ДОПИШИ» больше не меняются и вышел последний `ПЗ1-K` / `ПЗ2-K` — открыть docx в Word
   и **пересказать своими словами** общие абзацы: порядок мысли, обороты, длина фраз — свои; смысл — тот же.
3. **Не трогать:** числа и единицы, формулы, таблицы, рисунки и подписи к ним, позиционные обозначения (DD, R, C…), имена сигналов,
   названия и номера разделов (они по шаблону кафедры), ссылки [1], [2].
4. Сохранить копию docx у себя: **следующая сборка ПЗ перезапишет файл**, правки в Word в репо не попадают.
5. «Сохранить как PDF» → `Фамилия ИО ПЗ1-vN.pdf` / `ПЗ2-vN.pdf` (имя — как у docx).

**ИИ, который помогает студенту:** тексты «ДОПИШИ» пиши от лица студента и по-разному для разных студентов (не копируй чужие
`students/*/pz/`); общие абзацы docx через репо не правятся — предложи студенту пересказ по разделам (абзац → свой вариант),
он вставит в Word на шаге 2. Факты и числа в пересказе не менять.
Раскладка по разделам (что из шаблона руководителя — не трогать, что переписать через `*.md`, что — в docx), правила пересказа
и что делать после замечаний — [`docs/finish-guide.md`](finish-guide.md), разд. 2 и 4.
Посмотреть все три вида постранично — Actions → «ПЗ превью» → Run workflow (ник, pz2) → артефакт `preview`.

## ПЗ1 (КМ-2): рецепт для ИИ

1. Нужен только `students/<ник>/variant.yaml`: схему, перечень и всё считаемое джоба КМ-2 строит сама (KiCad в CI).
2. `make pz1-init S=<ник>` (или создать руками по образцу ниже) → `students/<ник>/pz/pz1.md` — два места «ДОПИШИ»:
   `p1.intro` — введение своими словами (1 абзац), `p1.buffer` — механизм обмена через буфер (3–5 предложений: путь одного
   отсчёта — разъём → ячейка обмена правым портом → INT1 → кольцо левым портом → чтение → Y2; кто двигает «голову» и «хвост»). Сравнение времён IDT7005 с шиной МК генерируется по даташиту
   `docs/group/idt7005 [en].pdf` (с. 8–9); свой вывод — по желанию в `p1.timing`. Потом — «Своими словами» (выше).
3. Push → Actions «КМ-2 ПЗ1» → `results/…/ПЗ1-K по СХЕМА-N/«Фамилия ИО ПЗ1.docx»` (сначала нужна схема — КМ-1). Локально: `make pz1 S=<ник>` (нужны KiCad и pandoc).

Что генерируется (порядок — как у принятой ПЗ1 Осиповой 2025 + требования ТЗ-2026 п. 2.1; выжимка — `docs/research/pz1-structure.md`):
титул по Прил. А ТЗ; содержание; введение; 1.1 структурная (рис. 2 ТЗ) и функциональная схемы, распределение ресурсов;
1.2 МК-устройство (фрагмент Э3, кварц, RC-сброс с расчётом τ, защёлка, **дешифратор** и таблица «Yn → устройство», таблица 40 выводов МК,
карта адресов); 1.3 клавиатура (фрагмент, расчёт RC антидребезга и тока кнопки, коды клавиш) и индикатор (фрагмент, расчёт резистора
сегмента, коды символов ОК/ОА); 1.4 буфер (фрагмент, разрядность адреса, временные диаграммы чтения и записи с параметрами AT89S53);
1.5 интерфейсные устройства (Y1, Y2, нагрузка портов); 1.6 помехоустойчивость (33 нФ на корпус, 470 мкФ); литература;
Прил. А — перечень элементов (ГОСТ 2.701), Прил. Б — схема Э3. Все номиналы и обозначения — из того же перечня, что и схема
(замечание руководителя: «номиналы на схеме = в перечне = в расчётах»).

## ПЗ2 (КМ-3): рецепт для ИИ

1. Программы уже проходят `make code S=<ник>` (см. `docs/code-guide.md`) — ПЗ2 описывает именно их.
2. `make pz2-init S=<ник>` → `students/<ник>/pz/pz2.md` (места «ДОПИШИ» с подсказками) и заготовки схем алгоритмов
   `students/<ник>/pz/flow/*.flow` под вариант (если папка пуста). Повторный запуск безопасен: текст сохраняется, порядок
   разделов — как в документе, разделы, которых больше нет, уходят в конец с пометкой «НЕ ИСПОЛЬЗУЕТСЯ».
3. **Схемы алгоритмов** — ТЗ (разд. 2.2) требует алгоритмы **всех** узлов, не только трёх программ: заготовки `01-init` … `12-t1`
   (основной цикл, клавиатура и реакция на клавиши, буфер — запись, чтение, очистка, индикатор, Timer0, Y1, Y2, Timer1).
   Те, что реализованы в твоём коде, подгони под **свой** код (схема обязана соответствовать программе). Имя файла задаёт порядок.
   Пояснение к каждой схеме генератор пишет сам (пересказ схемы по шагам); свой текст — в `pz2.md`, раздел `flow.<имя>`.
4. **Текст** — пиши под подсказками в `pz2.md`. Коротко и по делу, своими словами, со ссылками на рисунки и таблицы
   («рисунок 2», «таблица 1» — номера видны в docx). Сгенерированное в `pz2.md` не дублируй — его пересказывают своими словами
   прямо в docx в самом конце (раздел «Своими словами»).
5. `make pz2 S=<ник>` → `build/<группа>-23/<M>/pz2/«Фамилия ИО ПЗ2.docx»` (нужен pandoc: `brew install pandoc`).
   Номера страниц в содержании ставит джоба (LibreOffice); локально без него — пусто. Смотри `report.md`: сколько мест осталось.
6. Коммить `students/<ник>/pz/pz2.md` и `flow/*.flow`; джоба КМ-3 соберёт ПЗ2 и выложит в `results`.

Что генерируется в ПЗ2 (шаблон Прил. Б ТЗ): титул, аннотация, содержание, разд. 1–2 (с числами варианта), таблица подпрограмм
**из комментариев в коде** (имя, назначение, «Вход:», «Выход:», «Портит:» — пиши их в заголовке каждой процедуры),
прерывания, адреса устройств, переменные ОЗУ (из `vars.inc` и DSEG программ), клавиатура и коды клавиш, коды сегментов
(ОК/ОА), коды ошибок (заготовка), время заполнения буфера, **глубина стека — измерена в эмуляторе** на сценариях проверки,
сокращения, листинги трёх программ в приложении.

## Формат схем алгоритмов (`*.flow`)

Строки с отступом по 2 пробела; джоба рисует по ГОСТ 19.701 (символы, «да/нет», границы цикла, перенос в колонки через соединители).

```text
# Подпрограмма записи в кольцевой буфер BufPut      ← подпись рисунка
начало: BufPut (A — отсчёт)                          ← терминатор
действие: B := A                                     ← процесс
если: Буфер полон?                                   ← решение
  да:
    вызов: BufNext: хвост := следующая ячейка        ← предопределённый процесс (вызов подпрограммы)
    действие: Флаг переполнения := 1
  нет:                                               ← ветку «нет» можно не писать
данные: Записать B в ячейку «головы»                 ← ввод-вывод (movx, порты)
цикл: Ц1: для столбцов 1…3                           ← граница цикла; тело — с отступом
  действие: …
конец: Возврат                                        ← терминатор
```

Текст в символе переносится сам; `\n` — принудительный перенос. Обратных стрелок нет: повторение — только циклом.
Проверить одну схему быстро: `make pz2 S=<ник>` и открыть `build/…/pz2/flow-<имя>.png`.

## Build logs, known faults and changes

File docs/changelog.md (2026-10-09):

# Журнал изменений общей памяти

Сюда пишется каждое изменение важных участков (список — `RULES.md`, раздел 1) — **до или вместе** с изменением,
в том же коммите. Новые записи — **сверху**. Номер записи: `ГГГГ-ММ-ДД/NN` (NN — по порядку за день).

## Шаблон

```markdown
### ГГГГ-ММ-ДД/NN — коротко что
- **Кто:** ник (+ какой ИИ, если ИИ)          **Подтвердил:** ник человека | не требуется
- **Где:** файлы / участки
- **Было → стало:** …
- **Почему:** …
- **Доказательства:** источник (файл, стр./раздел, цитата ≤ 1 строки) | тест | ERC/netlist | рендер | расчёт
- **Проверено дважды:** 1) … 2) …
- **Затронуто / что перепроверить:** …
```

---

### 2026-10-09/28 — publish.sh: гонка за ветку results при перезапуске всех студентов
- **Кто:** ivan + Claude Code
- **Где:** `scripts/publish.sh`
- **Было → стало:** 3 попытки пуша по 5 с и тихий выход → 12 попыток со случайной паузой 3–15 с, не вышло — `::error::` и падение.
  Случай: 7 запусков КМ-1 одновременно, у Судьбинина СХЕМА-2 ушла на диск и в карточку Issue, но не в results — КМ-2/КМ-3 собрались
  по СХЕМА-1. Перезапущен.
- **Доказательства:** лог запуска 37964813299 («failed to push some refs» ×3), повторный КМ-1 с next.

---

### 2026-10-09/27 — вторые замечания к КМ-1 (Михалин — Рязанцев, Гольцов — Лапташкин): буфер с независимым доступом, шины по ГОСТ, УГО
- **Кто:** ivan + Claude Code (+ сабагент — проверка листов «глазами преподавателя»)
- **Замечания (дословно — `students/a12_ryazantsev_iv/remarks.md`, `students/a08_laptashkin_vi/remarks.md`; общее — `notes/remarks.md`).**
- **Почему так вышло (разбор):** 1) буфер 06.10 сделан по рис. Прил. А методички, а ТЗ-2026 строже: «независимый доступ внешнего
  устройства» (2.1 п. 6), «отдельный разъём с сигналами для доступа к буферу» (п. 9), для нечётных M программа 2 — запись МК в буфер
  (левый порт должен писать); 2) «обозначение подключений к шине» понято как «имя у входа», а по ГОСТ 2.702 у входа — условный номер
  линии, имя — на проводнике; провода с двух сторон шины в одной точке читались как пересечение; 3) проверка наложений не смотрела
  «провод вдоль края корпуса» (DD3.1) и близость надписей к линиям; 4) столбцы нумерации сливались по перекрытию корпусов — руководитель
  читает по центрам; 5) УГО и перечень — из библиотек KiCad без доводки до ГОСТ (толстые обкладки, кнопки с кружками, американские вентили,
  номиналы на листе, «Розетка» в наименовании).
- **Где:** `internal/schgen` (mps.go, sheet.go, busmarks.go — новый, overlap.go, renumber.go, style.go, bom.go, netlist_test.go),
  `cmd/mpslib` (+ `masters/lib/mps.kicad_sym`), `internal/pz` (pz1.go, flows 05a/05), `internal/render` (BUF_X2IN), `scripts/issue_notify.py`,
  AGENTS.md, docs (code-guide, pz-guide, riba, HANDOFF, finish-guide, research/schematics-review)
- **Было → стало:**
  - буфер: левый порт — МК целиком (R/WL ← WR); правый — целиком на отдельном разъёме XS (A0R–A12R, I/O0R–I/O7R, R/WR ← строб X2, тот же
    строб → INT1; CER → GND, OER → +5 В); X2 — в ячейку обмена `BUF_X2IN` (vars.inc), обработчик INT1 кладёт в кольцо; ПЗ1 1.4, схемы алгоритмов;
  - шины: у каждого входа — номер линии (одинаковый для сигнала по всему листу), имя сигнала — на проводнике; входы с двух сторон
    не напротив (сдвиг 1,27, `busY`; защёлка адреса и дешифратор — на полшага от рядов МК); RST и стробы Y — через шину;
  - проверки: провод ближе 0,6 мм к чужому корпусу, надпись ближе 0,15 мм к линии, входы в шину напротив, знак питания на корпусе/выводе,
    имя вывода пересекает линию внутри своего корпуса (поля ГОСТ-УГО);
    нумерация — столбцы по центрам корпусов (DD1 — регистр столбцов левее МК), `TestNumberingClear` — порядок не зависит от прочтения;
  - УГО: вентили только ГОСТ, «1»/«&» справа вверху; R 5,08×2,54; обкладки C тонкие, 4:1; кнопка — ключ без кружков; у MPU/RAM короткие
    подписи выводов (AD0, A8; без L/R) — основное поле шире надписи; номиналы и типы на листе не пишутся; обозначения сверху/справа;
    «+5V» у EA — влево (не вниз); сброс 1 мк керамика / 100 к; столбцы выровнены (сброс, кварц, 470 мк; IDT и регистр индикатора);
  - по самопроверке (сабагент «глазами преподавателя», 2 круга): микросхемы во всех стилях по ГОСТ 2.743 (основное поле MPU/RAM/RG/DC/BUF),
    активный ноль — кружком инверсии (CE, OE, EZ, E, Y0–Y7) единообразно; номер выхода ИЛИ-НЕ не на кружке (вывод длиннее);
    шина в 3,5–4 раза толще провода; вертикали строк клавиатуры и петля OE — шаг 2,54 (лекция: «не менее 2 мм»);
    одна цепь — одно имя (~{X2stb} у МК, буфера и разъёма; +5V в XS1); «№» в шапке разъёмов → «Конт.» (в шрифте нет знака);
    подписи фильтров и C клавиатуры — справа над обкладками; DD5.1 — не под землёй дешифратора; «+5V» вбок — надпись за стрелкой;
    провода к шинам ≥ 7,6 мм там, где номер и имя иначе слипались; сегменты в шине — номера по порядку a…g, dp;
  - по 3-му кругу самопроверки: узел сброса RC входит в шину на 5,08 ниже вывода RST (без ступеньки «насквозь»); Load регистра Y2
    (выход DD5.1) — через шину `xBY` линией `LdY2`, а не проводом поперёк шины; имя сигнала на коротком отводе — сразу за номером линии,
    не поверх; надпись бокового «+5V» — над проводом (не задевает надчёркивание метки строкой ниже); у RAM имена R/W и M/S без частичной
    черты (она читалась как подчёркивание OE/INT строкой выше); подписи C кварца — вплотную над своим; R и C строк клавиатуры — на 1,27 левее,
    «RowN» не касается точек; в УГО индикатора нет мелких букв сегментов; «Примечания»; метки прямым шрифтом, как имена выводов;
    стиль «один XS из частей» выключен (ТЗ 2.1 п. 9 — отдельный разъём для доступа к буферу); в обработчике X2 (схема 05a, ПЗ1 1.4) —
    ждать конца строба: INT1 по спаду, а правый порт пишет по фронту;
  - по 3-му кругу: подписи C кварца не касаются обкладок; земля CER — вверх, «+5V» OER — правее метки ~{X2stb} (метка у вывода,
    `Sheet.LabelAtPin`); земля неиспользуемых 2A DD7 — сразу под последним входом (не упирается в номер вывода EZ1); шина столбцов
    продлена за крайние отводы, номера под горизонтальной шиной не касаются её; подписи R строк клавиатуры — сразу над корпусом;
    входы с двух сторон шины на 1,27 оставлены (задумано `busY`, не напротив — объяснять так);
  - перечень: вид элемента — в «Примечании» («Розетка, N конт.», «Индикатор, общий анод», «Кварцевый», DD7 — «Буферный формирователь»),
    в наименовании — тип; у конденсаторов — допуск и напряжение; «8К×8»;
  - карточка КМ-1: отправлять ровно PNG из карточки (чёрно-белый), полный перечень и задание (ТЗ + params.md).
- **Не меняли (ответ руководителю):** выводы дешифратора — по табл. 1 и рис. 6 ТЗ (A0–A2 ← A13–A15, E2 ← CS_EN, номер выхода Yn по
  варианту); 74HC173 и 74AC573 — разные регистры по списку марок ТЗ («сдвоенный 4-разрядный: 74ac11873 или 74hc173», «8-разрядный: 74ac573»);
  индикация — по ТЗ только семисегментный индикатор; цвет — PNG/PDF генератора чёрно-белые (-b), цвет мог быть только в экспорте из KiCad.
- **Доказательства:** `go test ./...` (TestNetlist+ERC 35 листов, TestNoOverlaps 300, TestNumberingClear); листы 4 студентов просмотрены;
  проверка сабагентом по замечаниям и ГОСТ (3 круга).

---

### 2026-10-06/26 — дешифратор в столбце защёлок (как DC на рис. Прил. А), регистр Y2 — отдельным столбцом
- **Кто:** ivan + Claude Code (по сравнению с листом Казарина: у него дешифратор рядом с защёлками, нумерация читается естественно)
- **Где:** `internal/schgen/mps.go` (dxR, xBY, xY2B; y2Reg, decoder, idt, placeConnXY, buses), `fixes.go` (move.dec убран),
  `overlap.go` (знак питания против чужих корпусов и выводов), AGENTS.md
- **Было → стало:** дешифратор стоял отдельно справа сверху и получал последний номер (DD11), хотя на листе выше всех → в столбце
  защёлок под защёлкой адреса (входы A13–A15, CS_EN — с шины у МК, выходы CS — на новую шину `xBY`); регистр Y2 с вентилем Load — в своём
  столбце (данные — с `xBY`, выходы — шина `xY2B` под IDT7005 к XS3); IDT7005, её шины и XS2/XS3 сдвинуты вправо на 43,18 мм. Нумерация
  стала как у Казарина: DD1 МК, DD2 регистр столбцов, DD3 защёлка адреса, DD4 дешифратор, DD5 ИЛИ-НЕ, DD6 регистр Y2, DD7 «И», DD8 244,
  DD9 ИЛИ, DD10 IDT7005, DD11 регистр индикатора. Сдвиг дешифратора «почерком» (DecDX/DecDY) и `move.dec` больше не действуют.
  Проверка наложений дополнена: знак питания/земли на чужом корпусе или выводе (ловила землю дешифратора на вентиле ИЛИ-НЕ).
- **Доказательства:** `go test ./internal/schgen` (TestNetlist+ERC — 35 листов, TestNoOverlaps — 300, TestNumberingClear);
  `make student S=a12_ryazantsev_iv`, `make try` А-06/3 (стиль C), А-08/12, А-09/22 (D) — ERC пусто, PNG просмотрены.

---

### 2026-10-06/25 — рамка: графа 26 (обозначение, повёрнуто на 180°), «Копировал», «Формат А3»
- **Кто:** ivan + Claude Code (по сравнению с листом Казарина А.А., нарисованным им самим)
- **Где:** `masters/gost_ramka.kicad_wks` (+ прямоугольник графы 26), `masters/gost_ramka_full.kicad_wks`
- **Было → стало:** графа 26 в левом верхнем углу пустая (в простой рамке её не было вовсе), под рамкой нет полей формы ГОСТ 2.104 →
  в графе 26 — «Группа …, Вариант …, Э3» (та же строка, что в штампе; `PatchWks` меняет обе), под рамкой «Копировал» и «Формат А3».
- **Доказательства:** рендер А-12-23/17 просмотрен; `go test ./internal/schgen` (TestPatchWks).

---

### 2026-10-06/24 — по прогону Лапташкина (Issue #9): тик таймера в ПЗ2 и схемах, запись в буфер в схеме алгоритма, гонка в чекере
- **Кто:** ivan + Claude Code (сабагент провёл курсач А-08/12 через Issue #9 до ✅ и прислал шероховатости)
- **Где:** `internal/pz/pz2.go`, `internal/pz/flows.go`, `internal/pz/flows/05-bufwrite.flow`, `internal/codecheck/progs.go`, `check_test.go`,
  `scripts/issue_notify.py`
- **Было → стало:**
  - ПЗ2, 5.1: «TH0:TL0 = 65536 − 1 мс … = 64536» и «N_T1 = T1 / 1 мс» при любом тике, хотя тик по варианту бывает 2 мс и больше
    (у А-08/12 — 0F830h = 63536, 2 мс) → формулы от `Y1.TickMs`; абзац о перезагрузке таймера 0 — для режимов 1 и 2;
  - заготовки схем алгоритмов (08-show, 09-t0, 10-y1) — «1 мс» → тик варианта (подстановка в `DefaultFlows`);
  - 05-bufwrite «Записать A в ячейку» → «movx @DPTR по адресу «головы»: правый порт записывает байт X2 с разъёма» (буфер по Прил. А, /23);
  - чекер, индикатор: аргумент ставился в A до `toProc`, который доигрывает обработчик Timer0 — его `pop ACC` затирал A (верная программа
    получала ❌ «индикатор не погас») → сначала `toProc`, потом `SetA`; тест на 25 зёрен (гонку на эталоне не воспроизводит — честно);
  - карточка КМ-1 обещала «ПЗ1 и ПЗ2 пересоберутся», когда программ ещё нет → «ПЗ1 пересоберётся… дальше /км3».
- **Не меняли:** «ОСЭП» только в КМ-3 — так в источнике (сдача ПЗ2 и кода).
- **Доказательства:** отчёт сабагента (Issue #9, ПЗ2-1 по СХЕМА-2); `go test ./...`.

---

### 2026-10-06/23 — замечание руководителя к КМ-1: буфер по методичке, Т-отводы с именами у шины, без наложений, нумерация по столбцам
- **Кто:** ivan + Claude Code
- **Замечание (Михалин С.Н., 06.10.2026, КМ-1 Рязанцева, дословно — `students/a12_ryazantsev_iv/remarks.md`):** «Схема не отвечает
  требованиям стандартов — нумерация элементов — взаимные пересечения УГО — обозначение подключений к шине; и не удовл ТЗ — включение
  буфера например. Переделать.» Ошибки генератора — у всех студентов, поэтому чинится построитель (`RULES.md`).
- **Где:** `internal/schgen` (`mps.go`, `sheet.go`, `renumber.go`, `project.go`, `style.go`, `jitter.go`, новые `overlap.go`, `overlap_test.go`,
  `netlist_test.go`), `cmd/mpslib` + `masters/lib/mps.kicad_sym` (IDT7005), `internal/pz/pz1.go`, `internal/pz/flows/05a-x2isr.flow`,
  `internal/render/render.go` (нет `BUF_MBOX`), `scripts/issue_bot.py`, `.github/workflows/issue.yml`, AGENTS, code-guide, pz-guide, riba,
  HANDOFF, finish-guide, research (schematics-review, variants-lectures, pz1-structure)
- **Было → стало:**
  - **буфер** — «почтовый ящик» (/27: адрес правого порта на +5 В, R/WR ← строб X2) → как на рис. Прил. А методички-2026 и в принятой
    схеме 2025: адрес A0–A12 с шины и CE ← CS_buf на оба порта, левый — чтение (OEL ← RD, R/WL → +5 В), правый — запись байта с разъёма
    (R/WR ← WR, OER → +5 В), строб X2 — только INT1. ПЗ1 1.4, таблица времён (данные записи держит внешнее устройство), схема алгоритма INT1;
  - **подключения к шине** — отводы 45° в части стилей и метки «у вывода» (почерк LabelAtPin) → только Т-образно 90°, имя линии у места
    входа в шину (типовые замечания A.0 п. 5; лекция ч1 с. 10 рис. 1.6). Отвод встаёт на шину, перпендикулярную проводу (раньше на стыке
    двух шин мог встать на чужую);
  - **пересечения УГО** — найдено проверкой `Overlaps` (новая, по готовому .kicad_sch: надписи, корпуса, выводы, провода, шины через знаки
    питания) и исправлено: VD1–VD3 (подпись по диоду — KiCad не зеркалит выравнивание на 270°), ZQ1, DD3.1 (подпись на проводе AD7 → под
    вентилем), имена GND IDT7005 на I/O7L/R (корпус ниже на 2,54), «+5V» подтяжек под корпусом DD2 (DD2 левее), ~{CS_kbd} на номере вывода
    DD9 (вентиль правее), шина Y2 через землю IDT7005 (ниже). Крест KiCad «не подключено» с листа убран (в ГОСТ его нет, он перечёркивал
    номера выводов): ERC pin_not_connected выключен, список свободных выводов сверяет netlist-тест;
  - **нумерация** — столбцы сливались цепочкой по концам выводов (DD9 правее и выше DD10 в одном «столбце»; C15 почти в столбце C16–C19) →
    столбцы по корпусам без ножек выводов; фильтры питания левее на 2,54; тест `TestNumberingClear` ловит неочевидный порядок;
  - **бот** — новый Issue того же студента при закрытом старом продолжает его папку и пересобирает всё (km1-next); прогоны идут дальше
    по номерам, старые в `results` и на диске не трогаются; при открытом старом — отказ с подсказкой закрыть.
- **Доказательства:** методичка-2026 с. 14 и Прил. А (рис. — `pdftoppm`); `go test ./...` (TestNoOverlaps — 300 листов, все стили и «почерк»;
  TestNumberingClear; TestNetlist с ERC — 35 листов); `make try` А-06/3, А-08/10, А-09/22, `make student S=a12_ryazantsev_iv` — ERC пусто,
  PNG просмотрен.
- **Затронуто:** у студентов `a09_drugovskaya_em`, `a12_kazarin_aa` в текстах ПЗ и схеме алгоритма INT1 — «почтовый ящик»: их файлы не правили
  (чужие), нужно сказать им в Issue.

---

### 2026-10-01/22 — чекер: SP и стек против переменных; выжимка по коду и ПЗ2 приведена к факту
- **Кто:** ivan + Claude Code
- **Где:** `internal/codecheck/lint3.go` (новый), `check.go`, `check_test.go`; `docs/research/code-pz2-requirements.md` (разд. 2 и 5), `docs/code-guide.md` (разд. 4)
- **Было → стало:** выжимка писала «не проверяется» про 14 правил, из которых 10 уже были в коде. Добавлено: ⚠ «Указатель стека» —
  нет `mov SP, #07h` (ТЗ разд. 2.2: «в т.ч. стека МК: SP=07h»); ❌ «Стек» — после прогона стек (от начального SP до MaxSP) зашёл на
  переменные DSEG, «голову», «хвост» или байты флагов; ⚠ «Банки регистров» — включён банк 1–3, а стек начинается в нём.
  Имена ≤ 60 — уже ловил ассемблер (тест закрепляет). В выжимке — таблица статусов по каждому пункту (✅ / ◐ / ✖ с причиной),
  список доработок ПЗ2 — со статусами. Не делаем (нет источника): приоритет через IP, критические секции.
- **Доказательства:** `go test ./internal/codecheck` (4 новые «поломки» в `TestBrokenFail` падают, эталоны 6 вариантов проходят);
  `make code S=a12_ryazantsev_iv` — 3 ✅; ТЗ-2026 с. 7 (`pdftotext`): «в т.ч. стека МК: SP=07h», «более 60 символов».

---

### 2026-10-01/21 — лекции курса в репо
- **Кто:** ivan (положил файлы) + Claude Code
- **Где:** `docs/source/лекции-МПС-ч1.pdf`, `docs/source/лекции-МПС-ч2.pdf` (копии `docs/prev/mailru-mps-course/Лекции/`), `docs/finish-guide.md`, `docs/materials.md`
- **Было → стало:** лекции были только по ссылке на облако и локально в `docs/prev/` → лежат в `docs/source/`, нейронка студента
  открывает их из любой копии репо; ссылки «лекц. ч1/ч2 с. N» в `docs/research/` — на эти файлы.
- **Доказательства:** файлы скопированы из скачанной папки курса (решение Ивана: репо публичный — лекции видны всем).

---

### 2026-10-01/20 — гайд «Доводка курсача»: материалы, своими словами, защита, замечания
- **Кто:** ivan + Claude Code
- **Где:** `docs/finish-guide.md` (новый); ссылки — README (промпт, п. 6), `AGENTS.md` («Курсач под ключ», п. 9), `docs/pz-guide.md`,
  карточки бота (`scripts/issue_notify.py`: ПЗ1 и итоговая КМ-3), `/помощь` (`scripts/issue_bot.py`)
- **Было → стало:** после ✅ нейронка заканчивала; «своими словами» — общей фразой без раскладки → гайд: карта материалов
  (что в git, что только по ссылкам — лекции и работы прошлых лет в `docs/prev/`, как без них), раскладка ПЗ1/ПЗ2 на «не трогать»
  (шаблон руководителя Прил. Б: титул, аннотация, разд. 1, 2.1, начало 2.2, 3.3, сокращения; ЕСКД; числа, таблицы, термины) /
  «через репо» (`p1.*`, `p2.*`, `flow.*` — переживают пересборку; описания подпрограмм — из комментариев кода) / «в docx в конце»;
  правила пересказа; подготовка к защите по банку вопросов; цикл замечаний руководителя; образец предложения студенту после ✅.
  Итоговая карточка КМ-3 при ✅ и всех ДОПИШИ просит нейронку не заканчивать, а предложить доводку.
- **Доказательства:** состав шаблона ПЗ2 — `pandoc -t plain docs/source/шаблон-ПЗ2-ПрилБ.docx`; заголовки и автотекст — сборка
  ПЗ1/ПЗ2 А-12-23/17; `flow.*` и таблица подпрограмм — `docs/pz-guide.md`; страницы лекций — `docs/research/variants-lectures.md`,
  `code-pz2-requirements.md`; в `results` docx и «— просмотр.pdf» есть, `.md` ПЗ нет (ls-tree).

---

### 2026-10-01/19 — по итогам прогона «новой сессии» (Issue #4): шероховатости бота, карточек и инструкций
- **Кто:** ivan + Claude Code (+ сабагент с чистым контекстом прошёл курсач через Issue #4: всё ✅, отчёт о шероховатостях)
- **Где:** `issue.yml`, `scripts/issue_bot.py`, `scripts/issue_notify.py`, `internal/codecheck/lint.go`, `README.md`, `AGENTS.md`,
  `docs/code-guide.md`, `students/example-a12-14/variant.yaml`
- **Было → стало:**
  - очередь бота — одна группа на Issue: при трёх командах подряд средняя терялась → свой запуск на каждый комментарий,
    коммит бота — 6 попыток со случайной паузой;
  - карточки ПЗ при всех заполненных «ДОПИШИ» всё равно писали «есть жёлтые пометки… сдавать нельзя» → только при незаполненных;
    в карточке КМ-3 — «все ДОПИШИ заполнены»; «2 места» → «2 обязательных»;
  - доля комментариев в коде считала таблицу векторов заготовки (nop/reti) → только код студента (адреса ≥ 2Bh);
  - README: создание Issue — `--body-file` (многострочный `--body` песочница агента не пустила); когда пустая `/км2`/`/км3`, что
    с не присланными `.flow`; одна команда — один комментарий; бот читает форму и с отступом заголовков;
  - AGENTS: основной путь — Issue, «Курсач под ключ» — для тех, кто пушит; code-guide: «Actions → code», `code.yml` → КМ-3, `km3.yml`;
  - образец `example-a12-14`: ФИО «Студентов С.С.» (было ФИО Ивана), комментарии про стиль — «авто».
- **Не меняли:** таблица кодов ошибок и 13 схем алгоритмов ПЗ2 описывают полную систему (ТЗ разд. 2.2 требует алгоритмы всех узлов),
  а не три программы — это осознанно; сабагент отметил это в `p2.errors` своими словами.
- **Доказательства:** отчёт сабагента; `go test ./internal/codecheck ./internal/variant`; синтаксис скриптов и yml.

---

### 2026-10-01/18 — карточки Issue: цветные плашки, нейронке — свёрнутый блок; принципы вёрстки docx в гайде
- **Кто:** ivan + Claude Code          **Подтвердил:** ivan («щас идеально»; «визуально понятнее и разделенее для ии и для юзеров»)
- **Где:** `scripts/issue_card.py` (новый, общий), `issue_bot.py`, `issue_notify.py`, `docs/pz-guide.md`
- **Было → стало:** разделы карточки жирными строками подряд → «📎 Файлы» списком; «Вам — что сделать сейчас» — зелёная плашка
  ([!TIP]); «Перед сдачей — обязательно» — красная ([!CAUTION]); «Дальше» — фиолетовая ([!IMPORTANT]); памятка КМ-3 и инструкция
  нейронке — свёрнутые блоки в конце. В гайд ПЗ — раздел «Вёрстка docx — только то, что понимают все просмотрщики».
- **Доказательства:** рендер карточек через `gh api markdown` (gfm) — плашки и свёрнутые блоки отображаются.

### 2026-10-01/17 — docx для простых просмотрщиков: явные разрывы страниц, боковые графы картинкой
- **Кто:** ivan + Claude Code          **Подтвердил:** ivan («пдф хорошо строится а вот ворд не оч»; скриншоты: графы по буквам, аннотация/
  содержание/разделы сплошняком)
- **Где:** `internal/pz/ooxml.go` (`pageBreaks`, картинки в `normalizeDocx`), `sidegraph.go` (новый), `title.go`, `doc.go`, `build.go`, `cmd/mpspz`
- **Было → стало:** «с новой страницы» — свойством стиля (pageBreakBefore), боковые графы — повёрнутым текстом в ячейках; простые
  просмотрщики docx (встроенные в приложения, облака) оба приёма не понимают → у заголовков разделов и «СОДЕРЖАНИЯ» явный разрыв
  первым элементом заголовка (не отдельным абзацем — тот давал пустой лист в Word), pageBreakBefore из стилей убран; графы — PNG
  12 × 145 мм (GOST type A), в титуле нижняя часть — одна строка «картинка | Выполнил… Москва» без объединения ячеек.
- **Доказательства:** локальная сборка ПЗ2: в docx `media/sidegraphs.png` + rel, 10 разрывов у заголовков, pageBreakBefore в стилях — 0,
  проверка порядка OOXML чистая; превью LibreOffice после пуша.
- **Проверено дважды:** 1) `go test ./internal/pz`; 2) просмотр студентом в том же просмотрщике, где было криво.

### 2026-10-01/16 — проверка «всё, что может сломаться у студента»: шрифт PT Sans, бот на кривых входах
- **Кто:** ivan + Claude Code          **Подтвердил:** ivan («давай проверим все возможные варианты какие могут возникнуть проблемы у студентов»)
- **Где:** `internal/flow/style.go` (+`TestFontsParse`), `fonts/` (−PTSans), `scripts/issue_bot.py`, `issue.yml`, `internal/variant/nick_test.go`, `cmd/mpspz`
- **Было → стало:**
  - **PT Sans** (1 из 5 шрифтов блок-схем, выбор по «группа|вариант») не читается freetype («bad kern table length») → ПЗ1 и ПЗ2 падали
    примерно у каждого пятого варианта (найдено прогоном всех вариантов). Шрифт убран; тест открывает каждый шрифт набора;
  - бот: ФИО приводится к «Фамилия И.О.» («иванов иван иванович», «Петрова-водкина а.с.»), вариант «08»/«020» → 8/20, `/км 2` = `/км2`;
    тёзке в группе с другим вариантом — ник `…_<M>`; занятый вариант группы — отказ с объяснением; смена ФИО/группы в форме —
    папка переименовывается (коммит `git add -A students/`);
  - дубль варианта в `students/` больше не роняет тесты и КМ у всех (`TestStudentDirs` — только лог), его отсекает бот;
  - схема алгоритма с синтаксической ошибкой не роняет ПЗ2 — пропускается, ошибка в предупреждениях (report, карточка).
- **Доказательства:** прогон всех групп × M (А-06: 1, 8, 9, 10, 11, 14, 15… — «bad kern table length»); проверка шрифтов по одному;
  локальные сценарии бота (a–i) — все с ожидаемым ответом.
- **Проверено дважды:** 1) тесты; 2) повторный прогон после правки: А-06, А-07, А-08, А-09, А-12 × M = 1…30 (150 вариантов) —
  схема + ERC пустой, ПЗ1, заготовки программ (ассемблируются), ПЗ2 — у всех 150 без ошибок; А-17 и Аэ-21 не гоняли (по просьбе ivan).

### 2026-10-01/15 — ассемблер: AR0…AR7 и USING (Keil A51); очередь запусков КМ вместо отмены
- **Кто:** ivan + Claude Code          **Подтвердил:** ivan («там вроде что-то нейронке менять пришлось»; «почему на диске нет пз…»)
- **Где:** `internal/asm51/asm.go` (+`TestARn`), `docs/code-guide.md`, `km1.yml`, `km2.yml`, `km3.yml`
- **Было → стало:**
  - нейронка в Issue #3 (Казарин, вар. 8) написала `push AR0` — наш ассемблер `ARx` не знал, пришлось заменить на прямые адреса.
    Keil A51 (эталон робота, в нём писали принятые работы) их знает → теперь `AR0…AR7` = адрес Rn банка из `USING n` (по умолчанию 0);
  - `cancel-in-progress: true` в КМ-1/2/3: новый запуск оборвал КМ-3, когда та уже опубликовала `ПЗ2-4` в results, но джоба диска не
    началась → в results есть, на диске нет. Теперь запуски ждут друг друга (`false`).
- **Доказательства:** транскрипт сессии варианта 8 («ARx ассемблер не знает… заменю на прямые адреса банка 0»); `TestARn`
  (C0 00 / F5 07 / C0 08 после USING 1); results vs диск для «А-12-23/17 Рязанцев И.В.» (ПЗ2-4 только в results).
- **Проверено дважды:** 1) `go test ./internal/asm51`; 2) следующие прогоны в Issue.

### 2026-10-01/14 — ПЗ2: среда разработки генерируется (Keil µVision V5, как в принятых работах)
- **Кто:** ivan + Claude Code          **Подтвердил:** ivan («чтобы среду разработки прочее подставляла джоба — что пишут все студенты»)
- **Где:** `internal/pz/pz2.go` (`p2.ide`: Fill → FillOr), `AGENTS.md`
- **Было → стало:** «ДОПИШИ: среда разработки и компилятор» → абзац по умолчанию: Keil µVision V5, ассемблер A51, компоновщик BL51
  (пакет PK51), одна из 3 формулировок по «группа|вариант»; своя среда студента — в `p2.ide` (заменяет). Версии сборок не пишем — неизвестны.
- **Источник:** ПЗ2 прошлых лет из `docs/prev`: Осипова 2025 (принята) «µVision V5.38.0.0 (Keil Software); A51.exe; BL51.exe»;
  Базарнов, Хромочкина, Антонов, Шикулин, Егоров, Женюх — «KEIL µVision V5»; шаблон Прил. Б — «Среда разработки, компилятор: … (название, версия)».
- **Проверено дважды:** 1) поиск по всем ПЗ в `docs/prev`; 2) `go test ./internal/pz` (своя среда студента заменяет).

### 2026-10-01/13 — длинная схема алгоритма студента больше не роняет КМ-3
- **Кто:** ivan + Claude Code          **Подтвердил:** ivan («в тестовой сессии чтото упало в джобе»; «программы то разные бывают»)
- **Где:** `internal/flow/flow_test.go`, `cmd/mpspz/main.go`, `scripts/issue_notify.py`
- **Было → стало:** `TestRenderAll` проверял и `students/*/pz/flow/*.flow` → присланная нейронкой схема высотой 281 мм (большое ветвление
  «если» не делится на колонки) уронила тесты и всю КМ-3 (у всех). Теперь тест — только заготовки генератора; схема студента выше листа
  при сборке ПЗ2 уменьшается до 23 см по высоте, предупреждение — в `pz2/report.md` и в карточке Issue («разбить или упростить»).
  Циклы (в т. ч. вложенные) и так переносятся в колонки через соединители.
- **Доказательства:** лог запуска 36859486740 (`03-kbscan.flow: высота 281 мм`); замер всех схем студента сейчас — ≤ 221 мм; тесты.
- **Проверено дважды:** 1) тесты; 2) следующий прогон КМ-3 в Issue #2.

### 2026-10-01/12 — Issue по шагам: /км2, /км3 вместо россыпи команд, карточки ответов
- **Кто:** ivan + Claude Code          **Подтвердил:** ivan («пугает такое кол-во команд… должно быть прям интуитивно и студенту и нейронке…
  по шагам… с таким же стилем ответа»)
- **Где:** `scripts/issue_bot.py` (переписан), `scripts/issue_notify.py` (карточки), `km1.yml` (`next` → КМ-2 только если есть pz1.md), `README.md`
- **Было → стало:** 12 команд (/заготовки, /пз1, /prog1-3, /пз2, /flow, /файл, …) → три шага: КМ-1 (сам), `/км2` (заготовка ПЗ1 →
  `/км2` + ```pz1.md```), `/км3` (заготовки программ, ПЗ2, схем алгоритмов, список программ варианта → `/км3` + блоки с именем файла
  в первой строке); каждый ответ — карточка «шаг N, прогресс, 📎 файлы, 🧑‍🎓 студенту, 🤖 нейронке, ➡️ дальше». Открытие Issue
  запускает только КМ-1. Старые команды работают, в подсказках их нет.
- **Доказательства:** локально: приветствие, `/км3` (заготовки + программы варианта), `/км3` с тремя блоками (в т. ч. ```asm prog3.a51```),
  `/км2` без схемы — понятная ошибка; карточка КМ-3 собрана из тестовых данных.
- **Проверено дважды:** 1) локально; 2) живой прогон в Issue — после команды студента.

### 2026-10-01/11 — Issue: памятка КМ-3 в комментарии (программы варианта, требования, проверка, сдача)
- **Кто:** ivan + Claude Code          **Подтвердил:** ivan («в сообщении тоже гайд оставить про код… как его сдавать отправлять»)
- **Где:** `scripts/issue_notify.py` (`km3_guide`), `km3.yml` (в артефакте `params.md`)
- **Было → стало:** в комментарии КМ-3 — только отчёт и файлы → + свёрнутая памятка: три программы варианта (из `params.md`), что даётся,
  требования рис. 7, как проверяем мы (и что это не робот), как прислать `/prog1`, порядок сдачи: ПЗ2 → после рассмотрения программы.
- **Источник:** ТЗ-2026, разд. 2.2 (требования 1–7 к коду; робот 10.3.170.2:8051 после 7-й недели; «МПС-ПЗ2», затем «МПС-код»,
  «Фамилия ИО-код-n.txt», UTF-8). Как работать с самим роботом — в ТЗ не описано, в памятке так и сказано.
- **Проверено дважды:** 1) локальная сборка текста для варианта 17; 2) комментарий в Issue при следующем КМ-3.

### 2026-10-01/10 — «Своими словами»: правило для студентов и ИИ, напоминание в Issue
- **Кто:** ivan + Claude Code          **Подтвердил:** ivan («что надо что-то дописать и… уже написанное подпеределать другими словами
  чтобы отчеты не были идентичными»)
- **Где:** `docs/pz-guide.md` (новый раздел «Своими словами», рецепт ПЗ1 — 2 места «ДОПИШИ»; убраны устаревшие «от ФИО», «Приложение Б
  на титуле», «содержание — поле Word»), `AGENTS.md`, `README.md`, `scripts/issue_notify.py`
- **Было → стало:** общие абзацы ПЗ у всех из одного шаблона, правила про это не было → студент дописывает «ДОПИШИ», а по последней
  сборке пересказывает общие абзацы в docx (числа, таблицы, рисунки, обозначения не трогать; копию сохранить — пересборка перезапишет);
  ИИ пишет «ДОПИШИ» по-разному и предлагает пересказ; бот в комментариях ПЗ1/ПЗ2 напоминает.
- **Доказательства:** текст правил; источника «кафедра проверяет на одинаковость» нет — это мера осторожности (не требование кафедры).
- **Проверено дважды:** 1) перечитано; 2) синтаксис бота.

### 2026-10-01/09 — схема открывается в KiCad с рамкой ГОСТ; README: KiCad для студентов и для ИИ
- **Кто:** ivan + Claude Code          **Подтвердил:** ivan («мы даже файл для кикада отдаем?… редми… что можно поставить кикад и открыть»)
- **Где:** `internal/schgen/project.go` (`page_layout_descr_file: ramka.kicad_wks`), `README.md`
- **Было → стало:** в KiCad схема открывалась со стандартной рамкой (ГОСТ-рамку подставлял только наш рендер) → проект ссылается на
  `ramka.kicad_wks` рядом; README — как поставить KiCad и шрифт и какие 3 файла скачать из `СХЕМА-N`; правки — через `fixes.yaml`,
  ручные правки `.kicad_sch` — только для себя.
- **Доказательства:** `kicad-cli sch export pdf` без `--drawing-sheet`: со ссылкой в проекте строка рамки «Группа А-12-23» есть, без — нет.
- **Проверено дважды:** 1) контрольный рендер без ссылки; 2) `go test ./internal/schgen`.

### 2026-10-01/08 — даташит IDT7005 из материалов прошлых лет; сравнение времён в ПЗ1 генерируется
- **Кто:** ivan + Claude Code          **Подтвердил:** ivan («разрешение даю»; «а в дисках их не было?»)
- **Где:** `docs/group/idt7005 [en].pdf`, `docs/group/sn74act573 [en].pdf` (из `docs/prev/yandex-mpsch2/…/А-12-15/Александр/DataSheets/`),
  `internal/pz/pz1.go`, `docs/research/schematics-review.md`, `README.md`, `AGENTS.md`
- **Было → стало:** времена IDT7005 S55 в разборе — без источника, в ПЗ1 — место «ДОПИШИ» `p1.timing` → источник найден (даташит IDT,
  столбец IDT7005X55: tAA 55, tAOE 30 — с. 8; tWP 40, tDW 30, tAS 0, tDH 0 — с. 9), значения совпали с разбором; в ПЗ1 — таблица
  «требование ОЗУ / обеспечивает МК / запас» и вывод (`p1.timing` — необязательная замена). Из интернета ничего не скачано: на Renesas
  запрос повис, локальная копия нашлась. 74HC138 в материалах нет (в списке литературы — TI, ссылкой).
- **Доказательства:** `pdftotext` даташита (заголовки столбцов IDT7005X35/X55/X70); пересборка ПЗ1 — таблица 8 ссылается на таблицу 7.
- **Проверено дважды:** 1) значения по двум таблицам даташита; 2) тест `internal/pz` + сборка ПЗ1.

### 2026-10-01/07 — docx для Word: порядок элементов OOXML по схеме
- **Кто:** ivan + Claude Code          **Подтвердил:** ivan («в пдф норм выглядит а в ворд беда совсем»)
- **Где:** `internal/pz/ooxml.go` (новый: проверка `CheckOOXML` + нормализатор), `build.go` (нормализация после pandoc), тесты
- **Было → стало:** в стилях и сыром OOXML (титул, таблицы) дети pPr/rPr шли не в порядке схемы ECMA-376 (jc раньше spacing/ind/keepNext,
  wordWrap после jc, shd раньше pBdr, sz после lang/u) — LibreOffice прощает, Word «восстанавливает» документ и раскладывает криво.
  Теперь каждый docx после pandoc упорядочивается (rPr, pPr, tcPr, tblPr, рамки, sectPr), `TestBuildPZ2` падает при нарушениях.
- **Доказательства:** до — 8 нарушений в ПЗ1 и 7 в ПЗ2 (`MPS_DOCX=… go test -run TestCheckDocx`); после — 0; pandoc читает оба файла.
- **Проверено дважды:** 1) тесты; 2) открыть в Word — ждём от ivan (Word в CI нет).

### 2026-10-01/06 — имена файлов для сдачи по ТЗ-2026 в прогонах, на диске и в Issue
- **Кто:** ivan + Claude Code          **Подтвердил:** ivan («файлы в Issue приложенные называть правильно и в я-диске тоже»)
- **Где:** `scripts/publish.sh`, `scripts/issue_notify.py`, `km2.yml`, `km3.yml` (артефакт `.send`)
- **Было → стало:** `schematic.png`, «Фамилия ИО ПЗ1.docx» → в `СХЕМА-N` копия «Фамилия ИО Схема-vN.png», в ПЗ — «Фамилия ИО ПЗ1-vN.docx»
  (и «… — просмотр.pdf»), N = 1 + число замечаний к этому КМ в `remarks.md`; программы — «Фамилия ИО-код-n.txt» (как было).
  Комментарий бота — что отправить: тема «МПС-Схема/ПЗ1/ПЗ2/код», куда, вложение, «группа …, вариант …» в теле письма.
- **Почему / источник:** ТЗ-2026, конец разд. 2.1 и разд. 2.2: тема «МПС-Смысл», «Михалин СН Схема-v1.png», «Михалин СН ПЗ1-v1.pdf»,
  «Михалин СН ПЗ2-v1.pdf» на почту ОСЭП, «Михалин СН-код-1.txt» (тема «МПС-код», после рассмотрения ПЗ2), в теле — вариант и группа.
- **Доказательства:** локальный publish: «Рязанцев ИВ Схема-v1.png»; с одним замечанием КМ-2 — «Рязанцев ИВ ПЗ1-v2.docx».
- **Проверено дважды:** 1) локально; 2) Issue #1 после прогона.

### 2026-10-01/05 — Issue «Мой курсач»: студенты и их нейронки работают через Issue; README — «Для студентов» / «Для ИИ»
- **Кто:** ivan + Claude Code          **Подтвердил:** ivan («вернемся к идее issues… создали иссус с фио группа вариант препод, потом
  дернутся раны выложится им результат… и ссылка на яндекс диск… работать с правками через нейронку»; «в редми про Яндекс-диск убери»)
- **Где:** `.github/ISSUE_TEMPLATE/kursach.yml`, `.github/workflows/issue.yml`, `scripts/issue_bot.py`, `scripts/issue_notify.py`;
  КМ-1/2/3 — комментарий в Issue после диска и при ошибке, КМ-1 `next` (→ КМ-2/КМ-3); `yadisk_upload.py` (`.disk`); `README.md`, `docs/admin.md`
- **Было → стало:** работа только с правами на запись (Run workflow / пуш) → форма Issue заводит `students/<ник>/` (+ `issue`), бот
  коммитит файлы из команд (`/заготовки`, `/prog1-3`, `/пз1`, `/пз2`, `/flow`, `/правка`, `/замечание`, `/схема`, `/всё`) и запускает
  джобы; итог каждого прогона — комментарием (схема картинкой, docx/PDF, «ДОПИШИ», отчёт программ, папка на диске). Команды — только
  от автора Issue и участников; бот пишет только в папку своего студента, размер файла ≤ 200 КБ. README: инструкция по токену диска → docs/admin.md.
- **Доказательства:** локальный прогон `issue_bot.py`: форма → variant.yaml/issue/km1-next; комментарий с /prog1 + /правка + /замечание +
  неизвестной командой; повторный Issue того же студента и кривое ФИО — отказ с объяснением.
- **Проверено дважды:** 1) локально; 2) живой Issue — после разрешения ivan (публичное действие).
- **Затронуто:** нужна метка `курсач` в репо (права токену — из `permissions:` в yml, настройки репо не трогаем).

### 2026-10-01/04 — схема работы: один источник (variant.yaml), КМ-2/КМ-3 по сданной СХЕМА-N, папки с ФИО, замечания и правки схемы
- **Кто:** ivan + Claude Code          **Подтвердил:** ivan («подготовим весь воркфлоу на такую схему работы»; «папка фио группа номер
  прогона»; «вынести наружу… чтобы чужая нейронка… точечно подправить схему и писала историю замечаний»; «чтобы пробросилось в км2 и км3»)
- **Где:** `km1.yml`, `km2.yml`, `km3.yml`, новый `probe.yml`; `scripts/publish.sh`, `schema_fetch.sh` (новый), `changed_students.sh` (новый),
  `yadisk_upload.py`; `internal/variant/meta.go` (новый), `internal/schgen/fixes.go` (новый, +тест); `cmd/mpsgen` (`-info`, `-verify`,
  `-remark`, `meta.json`, fixes.yaml), `cmd/mpspz` (дата титула ПЗ1 — из схемы); `make remark`; `AGENTS.md`, `README.md`, гайды
- **Было → стало:**
  - формы КМ: группа/M/ФИО руками → только ник (данные — из `students/<ник>/variant.yaml`); проба любого варианта — отдельная
    джоба «Проба варианта» → `results/_пробы/`;
  - КМ-2 строил схему заново → берёт сданную `СХЕМА-N` из results (без KiCad), сверяет `meta.json` с variant.yaml и fixes.yaml
    («схема устарела — прогони КМ-1»); КМ-3 — так же (без схемы — проверка кода с предупреждением);
  - push пересобирал всех студентов → только тех, чьи файлы поменялись; правки генератора — только тесты;
  - папки `<группа>/<M>/<ВИД>-N` → `<группа>/<M> <ФИО>/СХЕМА-N`, `ПЗ1-K по СХЕМА-N`, `ПЗ2-K по СХЕМА-N`; старая раскладка в results удаляется;
  - замечания руководителя: `students/<ник>/remarks.md` (`make remark`), копия в каждом прогоне (`Замечания.md`);
    правки схемы студента — `students/<ник>/schema/fixes.yaml` (values, bom_names, bom_notes, note_add, move), входят в СХЕМА-N
    и дальше в ПЗ1 (перечень, расчёты) и КМ-3; `sheet.json` теперь с `style` и `jitter`;
  - убраны незакоммиченные формы Issues (решено: Run workflow для участников) и worktree тестового агента.
- **Доказательства:** локально на подставном origin: КМ-1 ×2 → СХЕМА-1/2 в «А-12-23/17 Рязанцев И.В.», fetch последней и по номеру,
  несуществующий номер — ошибка, смена стиля/fixes — код 3, ПЗ1 → «ПЗ1-2 по СХЕМА-2», старая «17/прогон-1» удалена; тесты `TestFixes`,
  `TestStudentDirs`; fixes на рендере: R10 = 300 на листе и в перечне, ERC пусто.
- **Проверено дважды:** 1) `go test ./...`, локальный e2e; 2) прогон джоб на `a12_ryazantsev_iv`.
- **Затронуто:** Яндекс-диск — старые папки (`17/`, `прогон-N`, `СХЕМА-N` без ФИО) не удаляются автоматически, чистить руками.

### 2026-10-01/03 — вид листа «авто»: признаки стилей смешиваются по «группа|вариант», больше «почерка»
- **Кто:** ivan + Claude Code          **Подтвердил:** ivan («мелких различий больше… группа + вариант мод число, чтобы любой прогон
  на этот вариант давал одну и ту же схему»)
- **Где:** `internal/schgen/style.go` (MixStyle), `jitter.go`, `sheet.go`, `netlist_test.go`, `cmd/mpsgen`, `cmd/mpspz`, `km1.yml`, `variant.go`
- **Было → стало:** стиль по умолчанию A (до того — по ФИО) → «авто»: вентили, микросхемы, отводы, имя шины (нет / BUS1 / B1…B5),
  таблица разъёмов (3 вида), XS1 из частей, рамка — каждый признак отдельно, 288 сочетаний; «почерк» +4 признака (диаметр точек,
  толщина шин и проводов, курсив меток) + сдвиги блоков: «Примечание» (вправо до рамки, вниз до 7,6 мм), дешифратор DD11 (−5…+15 / 0…+20 мм),
  полоса фильтров с XS1 (±2,5 мм) — только блоки, связанные метками и знаками питания. Зерно всего (лист, «почерк», вид ПЗ, шрифт блок-схем) — «группа|вариант», без ФИО.
  Явные A–D остались (`style:` в variant.yaml, список в форме КМ-1, по умолчанию «авто»).
- **Доказательства:** netlist + ERC на 5 вариантах × (A–D + 3 смеси); рендер 6 вариантов А-12 — просмотрен, ERC пусто.
- **Проверено дважды:** 1) `go test ./...`; 2) PNG глазами.
- **Затронуто:** у уже собранных вариантов вид листа и ПЗ сменится при следующем прогоне (было A/по ФИО).

### 2026-10-01/02 — ник студента «группа_фамилия_ио»; ПЗ читается и в упрощённых просмотрщиках
- **Кто:** ivan + Claude Code          **Подтвердил:** ivan («ник это латиницей группа_фамилия_ио»; скриншоты кривого просмотра)
- **Где:** `internal/variant/nick.go` (+тест папок `students/`), `cmd/mpsgen -nick`, `make nick`, `students/ivan` → `students/a12_ryazantsev_iv`,
  `internal/pz` (шапка и содержание таблицами, число листов, `RenderPDF`), `cmd/mpspz`, `pz-preview.yml`, `AGENTS.md`
- **Было → стало:** ник — любой латиницей → считается из group и name (`a12_ryazantsev_iv`), тест падает на неправильной папке и на двух
  студентах с одной группой и вариантом; шапка стиля A и содержание на табуляциях → таблицы без рамок; «Листов —» → число по рендеру;
  рядом с docx — «… — просмотр.pdf» (LibreOffice). Содержание больше не поле TOC (статичное, номера — из рендера CI).
- **Доказательства:** тесты; превью ПЗ1/ПЗ2 (ветка pz-view); скриншоты встроенного просмотрщика (табуляции, поворот текста, поля — не поддерживает).
- **Проверено дважды:** 1) `go test ./...`; 2) превью.
- **Затронуто:** правка текста прямо в Word не обновит номера содержания — пересобрать через CI (или вставить оглавление Word заново).

### 2026-10-01/01 — вёрстка ПЗ: титул таблицей, номера страниц в содержании, лист регистрации; стиль листа по умолчанию A
- **Кто:** ivan + Claude Code          **Подтвердил:** ivan («оч кривые первые страницы… проверь оба отчёта»; «дефолт А а не по фамилии»;
  «без фамилии группы и варианта не запускалось»)
- **Где:** `internal/pz/title.go`, `pages.go` (+тест), `doc.go`, `pz2.go`, `refdoc.go`, `style.go`, `cmd/mpspz`, `km2.yml`, `km3.yml`
  (шаг LibreOffice), `km1.yml` (форма Run workflow), `internal/schgen/style.go`, `AGENTS.md`, `README.md`
- **Было → стало:**
  - титул ПЗ1/ПЗ2: отступы «перед абзацем» + плавающая таблица боковых граф (в Word/просмотрщиках разъезжалось) → одна таблица
    без рамок с точными высотами строк, графы — её ячейки на левом поле; надпись «Приложение Б» (стиль B) убрана — это метка шаблона ТЗ;
  - содержание: список без номеров → точки + номера страниц: mpspz рендерит docx LibreOffice’ом (есть в CI), ищет заголовки в PDF
    и пересобирает; без LibreOffice — точки без номеров (Word обновит поле);
  - лист регистрации изменений — форма ГОСТ 19.604 (двухуровневая шапка, 9 pt, 24 строки по 8 мм);
  - листинги: табуляции — до позиций кратных 8, кегль подбирается под самую длинную строку (7…9 pt), VerbatimChar не перебивает кегль;
  - схема: стиль листа по умолчанию A (было — от ФИО; от ФИО теперь `auto`); Run workflow КМ-1: группа (список), M, ФИО — обязательны,
    стиль — список A–D, по умолчанию A; «все студенты» — только при push.
- **Доказательства:** превью LibreOffice (ветка pz-layout) ПЗ1 и ПЗ2 во всех стилях — просмотрены; тест `TestTOCPages`.
- **Проверено дважды:** 1) `go test ./...`; 2) превью страниц.
- **Затронуто:** в Word титул/содержание не проверены глазами (нет Word в CI) — ждём отзыв.

### 2026-09-30/28 — папки прогонов по видам: СХЕМА-N, ПЗ1-N, ПЗ2-N
- **Кто:** ivan + Claude Code          **Подтвердил:** ivan («давай прогоны называть нормально СХЕМА-номер… ПЗ1-… ПЗ2-…»)
- **Где:** `scripts/publish.sh`, `scripts/yadisk_upload.py`, `.github/workflows/km1.yml`, `km2.yml`, `km3.yml` (RUN_KIND, артефакт `.pub`),
  `AGENTS.md`, `README.md`, `docs/pz-guide.md`, `docs/code-guide.md`
- **Было → стало:** общий счётчик `прогон-N` на все джобы, в папке КМ-2 лежали и файлы схемы (КМ-2 собирает схему для рисунков) →
  у каждой джобы свой вид и счётчик: КМ-1 → `СХЕМА-N` (схема, перечни, params, vars.inc, ERC), КМ-2 → `ПЗ1-N` (docx + рисунки),
  КМ-3 → `ПЗ2-N` (docx + рисунки схем алгоритмов + `программы/`). publish.sh кладёт готовую папку в `build/…/.pub`, диск получает её как есть.
  Старые `прогон-N` в ветке и на диске не трогаются.
- **Почему:** в папке ПЗ1 лежала схема, ПЗ2 — в другой папке с соседним номером; непонятно, что где.
- **Доказательства:** локальный прогон publish.sh на подставном origin: СХЕМА-1, ПЗ1-1, ПЗ2-1, СХЕМА-2, оглавление со ссылками на последние.
- **Проверено дважды:** 1) локально; 2) прогон CI после пуша (диск).
- **Затронуто:** `scripts/issue_reply.py` (не закоммичен) — ссылки на `программы/`.

### 2026-09-30/27 — узел буфера: левый порт — МК (чтение и запись), правый — «почтовый ящик» внешнего устройства
- **Кто:** ivan + Claude Code          **Подтвердил:** ivan («Переделать узел буфера»; «сделай как решил»)
- **Где:** `internal/schgen/mps.go` (idt), `netlist_test.go`, `internal/render` (`BUF_MBOX` в vars.inc, строка в params.md),
  `internal/pz/pz1.go` (п. «Разработка двухпортового буфера»), `internal/pz/flows/05a-x2isr.flow`, `docs/code-guide.md`, `docs/riba.md`,
  `docs/HANDOFF.md`, `AGENTS.md`, `docs/research/schematics-review.md`, `variants-lectures.md`, `pz1-structure.md`
- **Было → стало:**
  - было (по методичке Прил. А и принятой схеме 2025): CEL = CER = CS_buf, адрес обоих портов с шины МК, R/WL = +5 В (левый порт
    только читает), R/WR = WR МК, данные правого порта с разъёма → `movx @DPTR,A` писал в буфер байт с разъёма, а не A;
  - стало: левый порт — МК целиком (CEL = CS_buf, OEL = RD, **R/WL = WR**, A0–A12, D0–D7); правый — внешнее устройство:
    I/O0R–I/O7R с разъёма, **R/WR = строб X2** (он же INT1), **CER = GND**, OER = +5 В, **A0R–A12R = +5 В** — запись всегда
    в ячейку `BUF_MBOX` = окно + 1FFFh (ТЗ-2025: A11R/A12R на GND → окно + 07FFh), вне кольца. ISR INT1 читает ящик левым
    портом и вызывает запись в кольцо (данные в A). Разъём XS2 не изменился (X2stb, X2_0–7, GND).
- **Почему:** ТЗ-2026 с. 2: «В качестве IOU выступают… выводы правого порта микросхемы буфера»; с. 5, «Блоком 3…»: X2 «с независимой
  8-разрядной параллельной шины со стробом записи низкого уровня в двухпортовое ОЗУ»; табл. 1 (с. 3): прог. 2 для нечётных M — запись,
  «данные через аккумулятор» (на старой схеме невыполнимо); указатели «голова/хвост» — в RAM МК (табл. 1), поэтому адрес
  выбирает МК, а внешнему устройству достаточно одной ячейки. Похожее (порт IDT целиком на разъёме) — Орлова 2021 (её Э3, Xs1.2).
- **Доказательства:** netlist-тест (цепи WR ∋ R/WL, INTx2 ∋ R/WR, CSbuf только CEL, выводы 25–37, 19, 21, 22, 39 на питании/земле)
  на 5 вариантах × 4 стиля; ERC пустой; рендер А-12 M=17 просмотрен; чекер кода не менялся — его модель и так «запись A в ячейку».
- **Проверено дважды:** 1) `go test ./...`; 2) PNG листа глазами.
- **Затронуто / что перепроверить:** ПЗ1 (текст и рис. узла), `variants-lectures.md` строка «независимый доступ» (была «не брать»);
  временные диаграммы ПЗ1 — сигналы левого порта (OEL, R/WL) теперь верны. Вопрос руководителю (не задан): устраивает ли «почтовый ящик».

### 2026-09-30/26 — КМ-2: ПЗ1 генератором; чекер по методичке и лекциям; ПЗ2 — все алгоритмы ТЗ
- **Кто:** ivan + Claude Code (+ 2 сабагента: выжимки `docs/research/pz1-structure.md`, `docs/research/code-pz2-requirements.md`)
- **Подтвердил:** ivan («10 итераций… опирайся на чужие работы, лекции, методички»; «под КМ-2 тоже генерировать»)
- **Где:** `internal/pz/pz1.go`, `title.go` (Прил. А), `internal/diag` (структурная, функциональная схемы, временные диаграммы),
  `internal/schgen/regions.go` + `sheet.json` из mpsgen (рамки узлов, обозначения по ролям, перечень), `.github/workflows/km2.yml`;
  `internal/codecheck` (progs.go, lint2.go), `internal/flow/describe.go`, `internal/pz/flows/` (12 заготовок)
- **Было → стало:**
  - ПЗ1 руками → генератор по структуре принятой Осиповой 2025 + ТЗ-2026 (дешифратор, 33 нФ, перечень и Э3 в приложениях); расчёты
    (резистор сегмента 325 → 330 Ом, C ≥ 166,7 нФ → 220 нФ, ток кнопки 3 мА, τ сброса 100 мс) — из номиналов перечня;
  - чекер: буфер «полон» только как V → принимаются обе политики, V и V−1 (методичка с. 14, Осипова); + RETI, заглушки nop/reti,
    заголовки всех процедур, переменные vs адреса табл. 1, сохранение A/PSW в обработчиках таймеров (⚠️), таймеры по ТЗ (⚠️),
    повторные вызовы при удержании клавиши (⚠️), опрос дольше 2 мс (⚠️);
  - ПЗ2: схемы только трёх программ → заготовки всех алгоритмов ТЗ разд. 2.2 (12); пояснения к схемам — пересказ схемы (своё — по желанию);
    «Ответы на п. 2.3» (в ТЗ-2026 такого пункта нет) → «Расчётные параметры» + формулы констант таймеров; лист регистрации изменений;
    заголовки процедур «Назначение: / Входные параметры: / Используемые регистры:».
- **Доказательства:** выжимки с источниками (файл, стр.); тесты (эталоны V и V−1, поломки RET/переменная на 47h/INT0 по уровню);
  превью ПЗ1 и ПЗ2 в CI (LibreOffice → PNG), просмотрено постранично; расчёты сверены с Осиповой (325 Ом → 330, 166,7 нФ) и методичкой.
- **Проверено дважды:** 1) тесты; 2) превью.
- **Затронуто / что перепроверить:** времена IDT7005 S55 в ПЗ1 — нет даташита в репо (место «ДОПИШИ»); у Осиповой в ПЗ1 нет перечня
  и Э3 — у нас есть (ТЗ-2026 требует полный перечень к КМ-2).

### 2026-09-30/25 — ПЗ по образцам принятых работ; вариации блок-схем; ассемблер ближе к Keil A51
- **Кто:** ivan + Claude Code          **Подтвердил:** ivan («качество не идеал… титульник полстраницы… блок-схемы с разными шрифтами на рандом»; «10 итераций»)
- **Где:** `internal/pz` (title.go, style.go, refdoc.go, doc.go, pz2.go), `internal/flow/style.go`, `fonts/` (+4 шрифта OFL), `internal/asm51`,
  `.github/workflows/pz-preview.yml`, `scripts/montage`
- **Было → стало:**
  - титул: шапка вуза + текст в верхней половине → по шаблону Прил. Б как у Осиповой 2025 (принята): название на трети высоты, «Листов N» полем NUMPAGES,
    блок «Выполнил…» справа, «Москва, год» внизу, боковые графы ГОСТ 2.104 плавающей таблицей;
  - колонтитулы: не было → номер страницы (на титуле нет); стиль A — сверху + «Курсовая работа, МПС ч2» справа;
  - 3 стиля документа от ФИО: A (Осипова 2025), B (Базарнов 2023 / Женюх 2022: «Приложение Б», «Рис. N.»), C (ГОСТ 7.32);
  - таблица подпрограмм 6 узких колонок → пункты 3.2.N по подпрограммам (назначение, вход, выход, регистры), как у принятых работ;
  - содержание: поле-заглушка → поле Word с готовым списком заголовков (видно и в LibreOffice/МойОфис);
  - блок-схемы: растягивались на 16 см → натуральный размер; вид от ФИО: 5 шрифтов (GOST A, Liberation Sans/Serif, Carlito, PT Sans),
    ширина 35/40/45 мм, «да/нет» или «Да/Нет», толщина линий, форма терминатора, стрелки на входах;
  - asm51: IF/ELSEIF/ELSE/ENDIF, $INCLUDE (REG51/REG52.INC, 89S53.MCU) — встроены, PUBLIC/EXTRN, понятная ошибка на RSEG/MACRO.
- **Доказательства:** образцы — `docs/prev/mailru-group/Защита/Осипова ДМ ПЗ2-v3 ПРИНЯТО.pdf` (титул, колонтитул, заголовки, «Рис. 3.1.»),
  `…/МПС_Кодовая_часть_БазарновДИ.pdf`, `…/V2 Программная часть МПС А-07-19_Женюх.pdf`; превью всех трёх стилей — джоба «ПЗ превью»
  (LibreOffice → PNG), просмотрено постранично; тесты `internal/pz`, `internal/flow`, `internal/asm51` (TestKeilCompat).
- **Проверено дважды:** 1) превью в CI; 2) тесты.

### 2026-09-30/24 — рыба переписана под ТЗ-2026
- **Кто:** ivan + Claude Code          **Подтвердил:** ivan («поправь»)
- **Где:** `docs/riba.md`
- **Было → стало:** CS на ножках P2.3–P2.7, окна по 2 Кбайт, таблица вариантов 2025 (5 групп), Y2 = M + X1 + X2, 5 отсчётов/с,
  фильтры 68 нФ, таймеры/INT по группам, политика буфера V−1, ручное рисование схемы в KiCad 9 → дешифратор 74HC138 + CS_EN,
  окна n·2000h по 8 Кбайт, таблица 7 групп ТЗ-2026, Y2 = G + M + X1 + X2, 4 отсчёта/с, 33 нФ, Timer0/Timer1 и INT0/INT1 у всех,
  буфер на V отсчётов (как в чекере), шаги 3/6/7 — через генератор (`make try`, `make code`, `make pz2`) со ссылками на гайды.
- **Доказательства:** ТЗ-2026 табл. 1 (с. 3), с. 5–7; `data/table-2026.yaml`; пример А-12/14 — из `build/А-12-23/14/params.md`
  (T1 331, V 1744, T2 2332 → 0F6E4h, T3 3,040, Y5/Y6/Y7/Y1, 47h/49h, биты 14/26), t_min = 1744/4 = 436 с, Y2(3,10) = 39.
- **Проверено дважды:** 1) таблица групп — построчно с текстом ТЗ (pdftotext); 2) пример — с `params.md` генератора.

### 2026-09-30/23 — джобы по КМ, ПЗ2 генератором, схемы алгоритмов по ГОСТ 19.701
- **Кто:** ivan + Claude Code          **Подтвердил:** ivan («раздельно по КМ-ам джобы — генерировать по максимуму из того, что может правильно и аккуратно»; «в PDF студент сам переведёт»)
- **Где:** `.github/workflows/km1.yml` (был build.yml), `km3.yml` (был code.yml), `internal/flow` (схемы алгоритмов), `internal/pz` (ПЗ: стили, сборка, ПЗ2),
  `cmd/mpspz`, `Makefile` (pz2, pz2-init), `scripts/publish.sh`, `scripts/yadisk_upload.py` (папки pz1/pz2), `docs/pz-guide.md`, `students/ivan/pz/`
- **Было → стало:** ПЗ писались руками по «рыбе» → ПЗ2 собирается в docx: титул, аннотация, содержание (поле Word), разд. 1–5 по шаблону Прил. Б
  с числами варианта, таблица подпрограмм из комментариев кода, ресурсы, коды клавиш/сегментов/ошибок, время заполнения буфера,
  глубина стека (замер в эмуляторе), сокращения, листинги; текст студента — из `students/<ник>/pz/pz2.md` по местам «ДОПИШИ».
  Оформление по ТЗ (поля 2/2/2,5/1 см, Times 12, одинарный) + ГОСТ 7.32 (отступ 1,25, разделы с новой страницы, таблицы с сеткой).
- **Доказательства:** шаблон `docs/source/шаблон-ПЗ2-ПрилБ.docx` (структура разделов), ТЗ-2026 «Требования к оформлению», методичка-2026 (содержание ПЗ);
  тесты `internal/pz` (слияние текста, разбор подпрограмм, полная сборка docx и проверка содержимого), `internal/flow` — рендер просмотрен глазами.
- **Проверено дважды:** 1) тесты; 2) docx Ивана (А-12, M=17) — текст разобран обратно pandoc, первая страница просмотрена.
- **Затронуто:** `docs/riba.md` частично устарела (5 отсчётов/с из ТЗ-2025, политика буфера V−1) — сверить; ПЗ1 (КМ-2) — следующий шаг.

### 2026-09-30/22 — проверка программ: свой эмулятор 8051 вместо s51, CI ≤ 5 мин
- **Кто:** ivan + Claude Code          **Подтвердил:** ivan («10 минут — уже долго… максимум 5 минут», «может есть альтернативные библиотеки»)
- **Где:** `internal/emu51` (новый), `internal/codecheck/check.go`, `mcu.go`, `.github/workflows/code.yml`, гайд, AGENTS, README
- **Было → стало:** сценарии гонялись во внешнем s51 (brew) по TCP, на раннере зависали и тормозили (> 10 мин) → встроенный эмулятор,
  тесты чекера 1,5 с; из основной джобы убраны brew и apt; сверка с MIDE — отдельная джоба по кнопке; CS_EN проверяется на каждом movx.
- **Доказательства:** `emu51/diff_test.go` — 60 случайных программ = s51 (ОЗУ, SFR, такты); эталоны с таймерами и INT0 = s51 в режиме
  совместимости (`VectorCycles = 1`); тесты чекера (эталоны, 12 поломок) зелёные на эмуляторе; T3/T1/T2 совпадают с расчётом.
- **Проверено дважды:** 1) две группы сверок с s51; 2) прогон CI.
- **Затронуто:** в чекере вход в прерывание — 2 МЦ (даташит), у s51 — 1: замеры отличаются ≤ 1 мкс на прерывание.

### 2026-09-30/21 — результаты по прогонам: ничего не перетирается
- **Кто:** ivan + Claude Code          **Подтвердил:** ivan («чтобы не перетирались прошлые результаты … папки с нумерацией 1 прогон 2 прогон»)
- **Где:** `scripts/publish.sh`, `scripts/yadisk_upload.py`
- **Было → стало:** `results/<группа>/<M>/` и `MPS-SHEMAS/<группа>/<M>/` перезаписывались каждым запуском →
  каждый запуск кладёт вариант в новую `прогон-N/` (N = последний + 1) с `run.txt` (workflow, ссылка на запуск, коммит, дата).
  Номер считает `publish.sh` по ветке и пишет в `build/…/.run`; Яндекс берёт его (если такая папка уже есть — следующий свободный).
  Старые файлы в корне варианта в ветке при первой публикации переезжают в `прогон-1`; на диске старые файлы в корне остаются — удалить руками.
  Оглавление ветки: число прогонов, последняя схема и последний отчёт по коду.
- **Доказательства:** локальный прогон `publish.sh` дважды на подставном origin со старой раскладкой → `прогон-1` (старое), `прогон-2`, `прогон-3`, README верный.
- **Проверено дважды:** 1) локально; 2) первый прогон CI после коммита.
- **Затронуто:** ветка `results` растёт (прогоны не удаляются) — если станет тяжёлой, чистить старые прогоны отдельно.

### 2026-09-30/20 — проверка программ КМ-3: ассемблер, симулятор, сценарии, заготовки, CI `code`
- **Кто:** ivan + Claude Code          **Подтвердил:** ivan («нужна механика: шаблоны и гайды, по которым чужие ИИ пишут код и гоняют в джобе»)
- **Где:** `internal/asm51`, `internal/sim51`, `internal/codecheck` (правила, модели, сценарии, `templates/`, `testdata/ref/`),
  `cmd/mpscode`, `internal/render` (`vars.inc`: + `KB_COLS`, `KB_ROWS`, `IND_OFF`), `docs/code-guide.md`, `.github/workflows/code.yml`,
  `scripts/mide_crosscheck.sh`, `scripts/publish.sh` (больше не стирает папку варианта целиком; колонка «Код»), `scripts/yadisk_upload.py` (`code/`), `Makefile`
- **Было → стало:** программ и их проверки не было → заготовки по рис. 7 под вариант; `mpscode` собирает, проверяет правила робота,
  гоняет сценарии в ucsim s51 с моделями устройств схемы и пишет «Фамилия ИО-код-n.txt» с вклеенным `vars.inc`.
- **Почему свой ассемблер, а не MCU 8051 IDE:** MIDE есть только в apt (на macOS — Docker), листинг и таблицу имён пришлось бы разбирать;
  свой даёт точные адреса строк `%proc%`/`%stop%` и адреса `X1`/`X2` для сценариев. Байты сверяются с MIDE в CI на каждом прогоне.
- **Соглашения, которых нет в ТЗ (выбраны нами, записаны в гайде):** HEAD — ячейка следующей записи, TAIL — следующего чтения,
  адреса XRAM; пусто — `F_EMPTY = 1`; полно — HEAD = TAIL при `F_EMPTY = 0`; `F_OVF` после затирания = 1, после чтения = 0;
  переменные программы Y2 — `X1`, `X2`. Как проверяет робот — неизвестно.
- **Доказательства:**
  - ТЗ-2026 с. 7–9 (разд. 2.2: требования 1–7 к коду, рис. 7), табл. 1 (какие программы), табл. 2–3, рис. 4–5;
  - схема: `internal/schgen/mps.go` — столбцы 74HC173 D0–D3 (MR ← RST), строки через 74HC244 D0–D3 (у 3 строк вход D3 на GND),
    ~INT0 = И строк, D_i → сегмент i (a…dp), ОА у А-08/09/12;
  - asm51: побайтно = HEX от MCU 8051 IDE 1.4.9 на `testdata/test.a51` и `m1.a51` (`TestAgainstMIDE`), + таблица кодировок команд;
  - сценарии: 6 вариантов × 3 программы эталонов проходят, 12 «поломок» (коды клавиш, столбцы не в 0, нет маски строк, CS_EN = 0,
    нет заворота, нет сдвига хвоста, X1 = 0, строб раньше записи, T1 × 2, ОА без инверсии, «% proc%», нет заглушки) — падают (`check_test.go`).
- **Проверено дважды:** 1) эталоны и поломки в тестах; 2) измерения согласуются с расчётом: строб T2 2332 мкс ± 4, T1 +0,02 %,
  T3 +0,1 %; протокол s51 — отдельным тестом `sim51/TestProtocol`.
- **Затронуто / что перепроверить:** первый прогон `code.yml` на раннере (Homebrew sdcc на ubuntu-24.04, apt mcu8051ide — не проверены
  на раннере); ответы робота на первые отправки — сверить с соглашениями; `publish.sh` теперь сливает папки варианта (build и code не затирают друг друга).

### 2026-09-30/19 — ПЭ3 как в принятых работах: форма 2 / 2а, заголовки групп, примечания в клетке
- **Кто:** ivan + Claude Code          **Подтвердил:** ivan («перечень в стиле прошлых рисуешь? там тоже по 2 страницы?»)
- **Где:** `internal/schgen/pe3frame.go` (новый), `pe3.go`, `cmd/mpsgen`
- **Было → стало:** на всех листах перечня штамп схемы (форма 1, 55 мм) → первый лист — форма 2 (185×40), следующие — 2а (185×15, «Лист N»);
  заголовок группы — слева в графе «Наименование», подчёркнут; длинное примечание — двумя строчками в одной клетке; группа не отрывается от строк;
  в стилях с рамкой с боковыми графами (A, D) — боковые графы и на перечне.
- **Доказательства:** принятый ПЭ3 Осиповой (2 листа, мелкий штамп на 2-м, примечания в две строки), ГОСТ-шаблон Женюха (форма 2, боковые графы,
  подчёркнутые заголовки групп), ГОСТ 2.104 (формы 2 и 2а), ГОСТ 2.701.
- **Проверено дважды:** 1) рендер глазами — сверено с обоими образцами; 2) все 4 стиля: 2 листа, ERC схемы пустой, тесты зелёные.
- **Затронуто:** —

### 2026-09-30/18 — «почерк» листа (вариации в пределах ГОСТ)
- **Кто:** ivan + Claude Code          **Подтвердил:** ivan («добавим больше разнообразия… сдвиги, подальше-поближе, текст побольше… по госту»)
- **Где:** `internal/schgen/jitter.go`, `sheet.go` (сдвиг чертежа, шрифты), `mps.go` (место меток/обозначений, шаг строк клавиатуры), `cmd/mpsgen` (`-plain`)
- **Было → стало:** у всех с одним стилем листы одинаковые → детерминированные вариации от «ФИО|группа|вариант»: сдвиг чертежа (0…25 мм × −10…+5 мм),
  шрифт меток 1,0/1,1, обозначения микросхем 1,27/1,5, «Примечание» 1,5/1,7, метки у шины или у выводов, обозначение слева/справа от питания,
  шаг строк клавиатуры 12,7/13,97 (при 3 строках).
- **Почему:** Базарнов = Хромочкина (одинаковые листы) — ровно то, чего избегаем.
- **Доказательства:** ГОСТ 2.702/2.721 не фиксируют эти параметры; шрифт меток ≤ 1,1 — чтобы черта над ~{CS} была видна (changelog /05).
- **Проверено дважды:** 1) netlist + ERC-тест со «почерком» (стили C/D); 2) рендер трёх ФИО глазами — наложений нет (крупный шрифт — только у микросхем/разъёмов/индикатора).
- **Затронуто:** эталон без вариаций — `-plain`.

### 2026-09-30/17 — перечень элементов ПЭ3 (ГОСТ 2.701)
- **Кто:** ivan + Claude Code          **Подтвердил:** ivan («работай пока репа не будет готова»)
- **Где:** `internal/schgen/bom.go`, `pe3.go`, `cmd/mpsgen`, `scripts/render.sh`; фильтры — шаг/начало линейки, `renumber.go` (запас столбца 0,5 мм)
- **Было → стало:** перечня не было → `perechen.pdf` (полный, для ПЗ1), `perechen-km1.pdf` (микросхемы и разъёмы, КМ-1), PNG, `perechen.md`.
  А4, графы 20/110/10/45, шапка 15, строка 8 мм, группы по алфавиту кода, одинаковые подряд — одной строкой («R2–R4»), штамп «…, ПЭ3», «Лист N / Листов M».
- **Доказательства:** ТЗ-2026 разд. 3 (КМ-1 — черновик перечня микросхем и разъёмов; КМ-2 — полный); принятый ПЭ3 Осиповой (группы, наименования, примечания);
  `remarks-and-defense.md` A.2 (ГОСТ 2.701, графы).
- **Проверено дважды:** 1) обозначения в перечне = на листе (строится из того же листа); 2) рендер глазами (шрифт GOST: «×», «→» нет — заменены).
- **Затронуто:** номера фильтров стабильны во всех стилях (C5–C15 у А-12/14).

### 2026-09-30/16 — 4 стиля листа по реальным работам
- **Кто:** ivan + Claude Code          **Подтвердил:** ivan («выведи основные стили из чужих курсачей… если нигде не встретилось — не надо»; «делай»)
- **Где:** `internal/schgen/style.go`, `conn.go`, `sheet.go` (отводы 90°), `mps.go`, `cmd/mpslib/gost.go` (ГОСТ-варианты символов `_G`),
  `masters/gost_ramka_full.kicad_wks` (рамка с боковыми графами), `cmd/mpsgen` (`-style`), `Makefile` (`STYLE`), CI (поле style)
- **Было → стало:** один вид листа → A (Рязанцев 2025), B (Осипова 2025), C (Сорокина 2023), D (Базарнов 2023); по умолчанию стиль от ФИО.
  Электрика одинакова: ГОСТ-символы сохраняют точки выводов исходных, раскладка общая.
- **Доказательства:** `docs/research/variants-works.md`, `variants-works-2.md` (кластеры KiCad-2025 и Visio-ГОСТ-2021…2023), рис. 6 ТЗ-2026 (KiCad, 45°);
  ГОСТ 2.743 (основное поле RG/BUF/DC/RAM/MPU — лекции ч1 с.11), ГОСТ 2.104 (боковые графы), методичка Прил. А («Контакт | Цепь»).
- **Проверено дважды:** 1) netlist-тест 5 вариантов × 4 стиля + ERC `--exit-code-violations` в тесте; 2) рендер всех стилей глазами.
- **Затронуто:** принятые решения по схеме не менялись; нумерация и «Примечание» считаются по ролям в каждом стиле.

### 2026-09-30/15 — поле «Преподаватель» (Пров.)
- **Кто:** ivan + Claude Code          **Подтвердил:** ivan
- **Где:** `cmd/mpsgen` (`-checker`), `Makefile` (`CHK`, по умолчанию «Михалин С.Н.»), CI (поле checker в Run workflow)
- **Было → стало:** проверяющий только из variant.yaml / по умолчанию → ещё и полем при запуске.
- **Проверено дважды:** 1) `make try … CHK="Гольцов А.Г."` → title_block comment 3; 2) без CHK → «Михалин С.Н.».

### 2026-09-30/14 — схема под ТЗ-2026: дешифратор CS, A11–A12, 33 н, ОА у А-12
- **Кто:** ivan + Claude Code          **Подтвердил:** ivan («нужно вбить все это дело… чтобы все было актуально»)
- **Где:** `internal/schgen/mps.go` (режим `Decoder`), `cmd/mpslib` (+74HC138), `cmd/mpsgen`, `Makefile` (TABLE = 2026), CI, `AGENTS.md`, README
- **Было → стало:** CS прямыми линиями P2.3–P2.7 → 74HC138 (A13–A15, E2 = CS_EN = P3.4) как на рис. 6 ТЗ-2026, имена CS_buf/CS_rgo/CS_ind/CS_kbd;
  P2 целиком — A8–A15; IDT7005 A11/A12 → адрес (было GND); фильтры 68 н × 10 → 33 н × 11; режим ТЗ-2025 оставлен.
- **Доказательства:** ТЗ-2026 с. 5 рис. 6, с. 6 («P3.4 – сигнал CS_EN…», «Дешифратор на 8 выходов»), п. 2.1(10) («33 нФ»), табл. 1 (V до 2100 байт, ОА у А-08/09/12).
- **Проверено дважды:** 1) netlist-тест (А-12/14 и А-17/21 по 2026: A11–A15, CS_EN, CS с выходов Yn); 2) ERC = 0 на 7 группах × M 3/30, рендер глазами.
- **Затронуто:** ПЗ1 — карта памяти (окна 8 КБ, база n·2000h), описание формирования CS; программы — CS_EN = 1 перед movx.

### 2026-09-30/13 — таблица вариантов и расчёт по ТЗ-2026
- **Кто:** ivan + Claude Code          **Подтвердил:** ivan (положил ТЗ-2026)
- **Где:** `data/table-2026.yaml`, `internal/variant` (Choice чёт/нечёт, `cs_mode: decoder`, G, CS_EN, `filter_cap`), `internal/render`, `docs/source/ТЗ-2026.pdf`, `методичка-2026.pdf`, `docs/research/tz-2026.md`
- **Было → стало:** ТЗ-2025 → ТЗ-2026 по умолчанию (группы А-06…Аэ-21, CS — Yn дешифратора, база n·2000h, Y2 = (G+M+X1+X2) mod 256, флаги M / M+G, T1/T3 — Timer0, T2 — Timer1, X2 до 4/с).
- **Доказательства:** ТЗ-2026 табл. 1 (с. 3, рендер), с. 5.
- **Проверено дважды:** 1) эталон А-12/14 посчитан руками и закреплён тестом `TestA12M14_2026`; 2) `TestAllVariants2026` (7 групп × 30 M) + `TestParity2026`; старые тесты 2025 проходят.
- **Затронуто:** `params.md`/`vars.inc` (VAR_G, Y2_CONST, PIN_CSEN, окна 8 КБ).

### 2026-09-30/12 — приоритет свежих материалов
- **Кто:** ivan + Claude Code          **Подтвердил:** ivan («приоритет материалам свежее, курсачи 25-24-23 самые актуальные»)
- **Где:** `RULES.md` раздел 3
- **Было → стало:** «работы прошлых лет» одним уровнем → принятые работы по свежести (2025 > 2024 > 2023 > старше), старше 2023 — только иллюстрация.
- **Почему:** ТЗ и требования руководителя меняются каждый год (см. `remarks-and-defense.md` D).
- **Доказательства:** указание Ивана; отличия ТЗ 2022/2023/2025 — `remarks-and-defense.md` D.
- **Проверено дважды:** не требуется (организационное).
- **Затронуто:** `variants-*.md` — при выборе стилей опираться прежде всего на работы 2023–2025.

### 2026-09-30/11 — КР1554ИР22 ≠ 573, КР1554АП4 ≠ 244
- **Кто:** ivan + Claude Code (нашёл сабагент, перепроверено)          **Подтвердил:** не требуется (исправление факта)
- **Где:** `cmd/mpslib/main.go` (описания символов), `docs/research/schematics-review.md`, `remarks-and-defense.md`, `styles.md`
- **Было → стало:** «74AC573 (КР1554ИР22)», «74AC244 (КР1554АП4)» как эквиваленты → ИР22 = аналог 74AC373 (другая цоколёвка),
  аналог 573 — КР1554ИР33; АП4 = аналог 74AC241 (2OE, вывод 19, активен высоким), аналог 244 — КР1554АП5.
- **Почему:** подпись «ИР22» на символе 573 дала бы неверные номера выводов; в самом ТЗ пары записаны неточно.
- **Доказательства:** даташит `docs/prev/yandex-zhenyukh-sorokina/даташит/kr1554ir22.pdf` — «2, 5, 6, 9… выходы; 3, 4, 7, 8… входы»;
  справочники аналогов rlocman/eham (в отчёте `variants-gost-parts.md`).
- **Проверено дважды:** 1) даташит ИР22; 2) символы KiCad: 74LS373 (D0 = 3, Q0 = 2), 74LS241 (вывод 19 без инверсии).
- **Затронуто:** на листе стоят 74AC573 и 74AC244 — электрика не менялась; отечественные названия в стилях — только с совпадающей цоколёвкой.

### 2026-09-30/10 — ФИО в рамку, группы 2023 года, раскладка «группа / вариант»
- **Кто:** ivan + Claude Code          **Подтвердил:** ivan
- **Где:** `internal/variant` (`Student.Defaults`, `Student.Dir`), `cmd/mpsgen` (`-name`, `-year`, `-outroot`, `-render`), `Makefile`,
  `scripts/publish.sh`, `scripts/yadisk_upload.py`, `.github/workflows/build.yml`, `students/example-a12-14`, README, AGENTS
- **Было → стало:** ФИО только из variant.yaml; «group_full» по умолчанию = ключ группы («А-12»); папки `build/try-А-12-14`, `results/<папка>`,
  `MPS-SHEMAS/<папка>` → поле ФИО в Run workflow и `make try FIO=…`; группа = ключ + год набора (по умолчанию 23 → «А-12-23»);
  проверяющий по умолчанию Михалин С.Н., дата — день сборки; везде `<группа>/<вариант>/`.
- **Почему:** указание Ивана: «группы 23 года — А-хх-23», «раскладывать по вариантам: группа → вариант → файлы», «докинуть ввод Фамилия И.О.».
- **Доказательства:** требование пользователя; рамка из ТЗ (Прил. А) — «Группа …, Вариант …».
- **Проверено дважды:** 1) локально: `make try` → `build/А-12-23/14`, рамка «Группа А-12-23, Вариант 14, Э3», title_block с ФИО и датой;
  publish.sh на временном репо — `А-12-23/14`, `А-17-23/21`, оглавление с колонками; yadisk — создаёт `А-17-23`, затем `А-17-23/21`;
  2) прогон на GitHub (см. `sessions/2026-09-30-ivan.md`).
- **Затронуто:** старые папки плоской раскладки в ветке `results` удаляются автоматически; на Яндекс-диске старую `example-a12-14` удалить руками.

### 2026-09-30/09 — копия результатов на Яндекс-диск
- **Кто:** ivan + Claude Code          **Подтвердил:** ivan
- **Где:** `scripts/yadisk_upload.py` (новый), `.github/workflows/build.yml`, `README.md`, `AGENTS.md`
- **Было → стало:** результаты только в ветке `results` → ещё и в папку MPS-SHEMAS на Яндекс-диске (`<вариант>/<файлы>`).
- **Почему:** Ивану удобнее забирать с Диска.
- **Доказательства:** API Яндекс-диска: загрузка только с OAuth (`/resources/upload`), публичная ссылка — чтение.
- **Проверено дважды:** 1) скрипт без токена — пропуск; 2) с неверным токеном — 401 с понятной ошибкой.
  3) после добавления секрета: прогон CI загрузил `MPS-SHEMAS/example-a12-14` (10 файлов), список сверен по публичной ссылке.
  По пути найдены и исправлены две ошибки скрипта (сравнение ссылки → по resource_id; конфликт аргумента `path`).
- **Затронуто:** секрет `YADISK_TOKEN` (ставит владелец папки).

### 2026-09-30/08 — результаты CI в ветку results + сводка запуска
- **Кто:** ivan + Claude Code          **Подтвердил:** ivan
- **Где:** `scripts/publish.sh` (новый), `.github/workflows/build.yml`, `Makefile` (`build/try-<группа>-<M>`), `RULES.md` (исключение для force-push), `AGENTS.md`, `README.md`
- **Было → стало:** результаты только в zip-артефакте на 7 дней → ветка `results` (перезаписывается одним коммитом) + Job summary с картинкой, ERC и параметрами; артефакт остаётся.
- **Почему:** результат должен быть виден сразу и по постоянной ссылке, без скачивания zip.
- **Доказательства:** локальный прогон `publish.sh` на временном bare-репо: 2 варианта, прежний сохраняется, одна запись в истории ветки.
- **Проверено дважды:** 1) локальный тест; 2) реальный прогон Run workflow после пуша (см. `sessions/2026-09-30-ivan.md`).
- **Затронуто:** папка `make try` теперь `build/try-<группа>-<M>`.

### 2026-09-30/07 — правила работы с общей памятью и этот журнал
- **Кто:** ivan + Claude Code          **Подтвердил:** ivan
- **Где:** `RULES.md` (новый), `docs/changelog.md` (новый), `AGENTS.md`
- **Было → стало:** правил изменения общей памяти не было → протокол «доказать → записать → изменить», двойная проверка, журнал.
- **Почему:** репо публичный и общий для группы и ИИ; ошибка в общей памяти расходится по всем курсовым.
- **Доказательства:** решение владельца репо (Иван, сессия 2026-09-30).
- **Проверено дважды:** не требуется (организационное).
- **Затронуто:** все ИИ-сессии — читать `RULES.md` в начале.

### 2026-09-30/06 — нумерация и номиналы по ГОСТ, MR ← RST
- **Кто:** ivan + Claude Code          **Подтвердил:** ivan
- **Где:** `internal/schgen/renumber.go`, `internal/schgen/mps.go`
- **Было → стало:** нумерация как в принятой схеме (МК = DD3), номиналы латиницей («10k», «68n»), MR 173 → GND →
  нумерация по положению (DD1 МК, DD2 173, DD3 ИЛИ-НЕ, DD4/DD5 573, DD6 IDT7005, DD7 «И», DD8 573 инд., DD9 244, DD10 ИЛИ),
  номиналы «10 к», «68 н», «12 МГц», MR 173 ← RST.
- **Почему:** нумерация и номиналы — требования ГОСТ и типовые замечания; сброс устройств по Reset — рекомендация лекции.
- **Доказательства:** ГОСТ 2.710 (порядок «сверху вниз, слева направо»), типовые замечания (`docs/research/remarks-and-defense.md` A.0 п.3);
  ГОСТ 2.702 (обозначение номиналов); лекции ч1 с.76 п.5 («сброс устройства по Reset»); даташит 74HC173 (MR активен высоким).
- **Проверено дважды:** 1) `refs_test.go` — номера 1..n подряд, 10 корпусов DD; 2) netlist-тест: цепь RST = DD1.9, C, R, DD2.15; ERC = 0 на 3 вариантах.
- **Затронуто:** «Примечание» на листе (номера считаются по ролям), будущий перечень ПЭ3.

### 2026-09-30/05 — правки по сверке с лекциями
- **Кто:** ivan + Claude Code          **Подтвердил:** ivan
- **Где:** `internal/schgen/mps.go`, `sheet.go`, `cmd/mpslib`
- **Было → стало:** Cp 173 ← ИЛИ-НЕ(WR, WR) → Cp ← WR; метки INT без черты → `~{INT0}`/`~{INT1}`; шрифт меток 1,27 → 1,1 мм
  (черта над CS сливалась с проводом выше); GND IDT7005 в одной точке → раздельно 5/9/24/41; имена выводов МК без индексов.
- **Почему:** фронт Cp должен приходить в конце записи; активные нулём сигналы — с чертой; «имена выводов без индексов» — типовое замечание.
- **Доказательства:** лекции ч1 с.76–78 (CS объединять с WR/RD); ТЗ-2025 сноска стр. 2 (CS и стробы активны нулём);
  `remarks-and-defense.md` A.1; рендер PNG до/после.
- **Проверено дважды:** 1) рендер PNG глазами; 2) netlist-тест (WR = DD1.16, DD3.3, DD3.6, DD2.7, DD6.20).
- **Затронуто:** ПЗ1 — объяснить стробирование 173 и 573 (ИЛИ-НЕ для 573: LE активен высоким, защёлкивание по спаду).

### 2026-09-30/04 — схема Э3 строится кодом (internal/schgen), мастер и патчер удалены
- **Кто:** ivan + Claude Code          **Подтвердил:** ivan
- **Где:** `internal/schgen/`, `cmd/mpsgen`, `masters/`
- **Было → стало:** мастер-схема из папки группы + перенос меток патчером → построитель по образцу принятой схемы Ивана
  (вид 1:1, объективные ошибки исправлены), KiCad 10.
- **Почему:** мастер электрически битый: HG1 чужой цоколёвки (HDSP-7403 вместо FYS-5612), клавиатура замкнута в одну цепь,
  у IDT7005 не подключены A0/A1/A5/A6/A8L/A10L, BUSY, INT.
- **Доказательства:** netlist мастера (цепь `Net-(VD1-A)` содержит SB1–SB12 оба вывода); даташит FYS-5612 стр. 3 (A7 B6 C4 D2 E1 F9 G10 DP5, общий 3/8).
- **Проверено дважды:** 1) netlist через kicad-cli; 2) визуально по даташиту.
- **Затронуто:** CI на KiCad 10, `make student/try` без `-masters`.

### 2026-09-30/03 — исправлены ошибки принятой схемы (при сохранении вида)
- **Кто:** ivan + Claude Code          **Подтвердил:** ivan («вид тот же, ошибки править»)
- **Где:** `internal/schgen/mps.go`
- **Было → стало:**
  - сброс: только R на GND → C 10 мк от +5 В + R 10 к на GND;
  - фильтры: 68 п → 68 н, по одному на корпус;
  - логика: ТТЛ (7402, 74AS) → КМОП (74HC/AC);
  - IDT7005: M/S = +5 В (master) → M/S = GND (slave), BUSY → +5 В;
  - индикатор: обе стороны R8–R15 названы Q0..Q7 (резисторы закорочены в netlist) → Q0..Q7 / a..dp;
  - примечание: «DD9 выв. 8, 11 к GND» (выходы!) → только входы.
- **Почему / доказательства:**
  - ТЗ-2025 п. 2.1 (10) — 68 нФ + 470 мкФ; ТЗ — только КМОП (1554/1564/74HC/AC);
  - даташит AT89S53 — RST активен высоким, без C нет сброса при включении;
  - даташит IDT7005 раздел BUSY LOGIC — в master запись на проигравшем порту блокируется, при CEL = CER на одном адресе — случайно; «tying BUSY high» в slave;
  - даташит 74xx32 — выводы 8, 11 выходы.
- **Проверено дважды:** 1) даташиты/ТЗ; 2) netlist-тест (цепи Q и seg раздельны, OE244 = DD10.3, DD9.1, DD9.19).
- **Затронуто:** ПЗ1 — механизм доступа к буферу, заготовить ответ «в чём двухпортовость».

### 2026-09-30/02 — выжимки из материалов прошлых лет
- **Кто:** ivan + Claude Code (сабагенты)          **Подтвердил:** не требуется (новые файлы)
- **Где:** `docs/research/schematics-review.md`, `docs/research/remarks-and-defense.md`, `docs/materials.md`
- **Было → стало:** нет → разбор схем по узлам, чек-лист замечаний, банк вопросов, отличия ТЗ прошлых лет.
- **Доказательства:** источники указаны в самих файлах (пути `docs/prev/…`).
- **Проверено дважды:** ключевые выводы (HG1, клавиатура мастера, BUSY) перепроверены вручную по netlist и даташитам;
  остальное — **однократно** (сабагентом), при использовании перепроверять.

### 2026-09-30/01 — перенос из claude.ai в репо
- **Кто:** ivan + Claude (claude.ai)          **Подтвердил:** ivan
- **Где:** `docs/HANDOFF.md`, `docs/riba.md`, `internal/variant`, `data/table-2025.yaml`
- **Было → стало:** контекст в чате → файлы репо.
- **Доказательства:** эталон А-12, M=14 сверен с ручным расчётом (`internal/variant/variant_test.go`).

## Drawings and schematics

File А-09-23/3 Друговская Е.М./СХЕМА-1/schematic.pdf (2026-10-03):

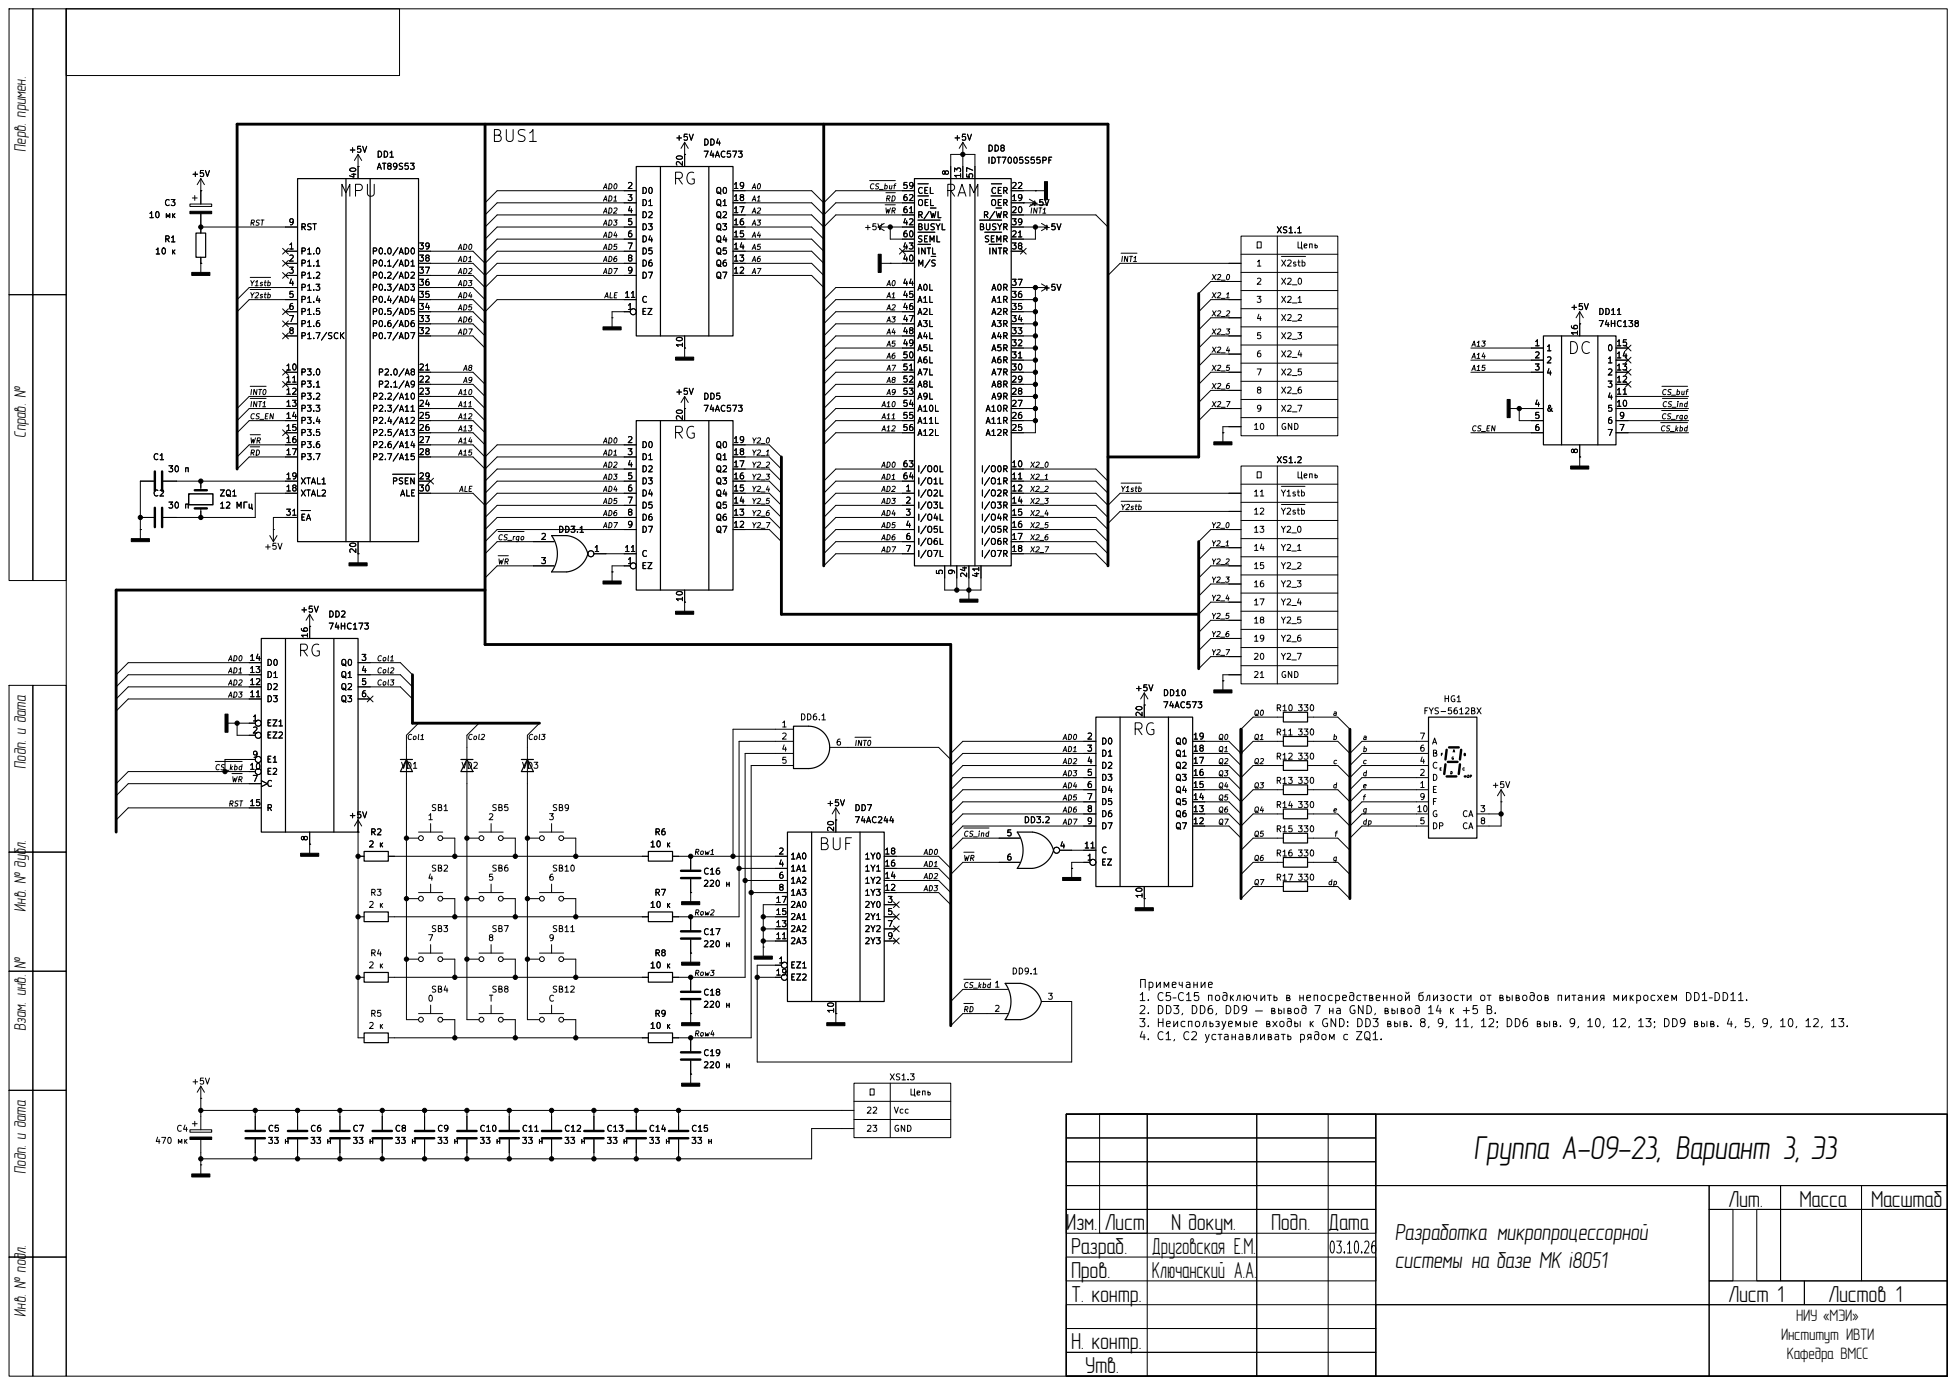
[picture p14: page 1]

№ Инв. № дубл. Подп. и дата Перв. примен. Справ.
RST RD

+5V
EZ 1 D0 2 D1 3 D2 4 D3 5 D4 6 D5 7 D6 8 D7 9 | +5V RG 10 C 10 C

A2 | WR | SEML 60 R/WL 61 OEL 62 | 21 CER 21 CER 20 20
A1 | | | 19 R/WR 19 R/WR INT1

Группа А-09-23, Вариант 3, Э3 Инв. № подл. Подп. и дата Взам. инв.

1. C5–C15 подключить в непосредственной близости от выводов питания микросхем DD1–DD11.
2. DD3, DD6, DD9 — вывод 7 на GND, вывод 14 к +5 В.
3. Неиспользуемые входы к GND: DD3 выв. 8, 9, 11, 12; DD6 выв. 9, 10, 12, 13; DD9 выв. 4, 5, 9, 10, 12, 13.
4. C1, C2 устанавливать рядом с ZQ1.

Vcc GNDЦепь XS1.3

Разработка микропроцессорной системы на базе МК i8051 | Лит. | Масса | Масштаб

Изм. Лист | N докум. | Подп. | Дата
Разраб. | Друговская Е.М. | | 03.10.26
Пров. | Ключанский А.А.
Т. контр. | | | | Лист 1 | Листов 1

НИУ «МЭИ» Институт ИВТИ Кафедра ВМСС

Н. контр.
Утв.

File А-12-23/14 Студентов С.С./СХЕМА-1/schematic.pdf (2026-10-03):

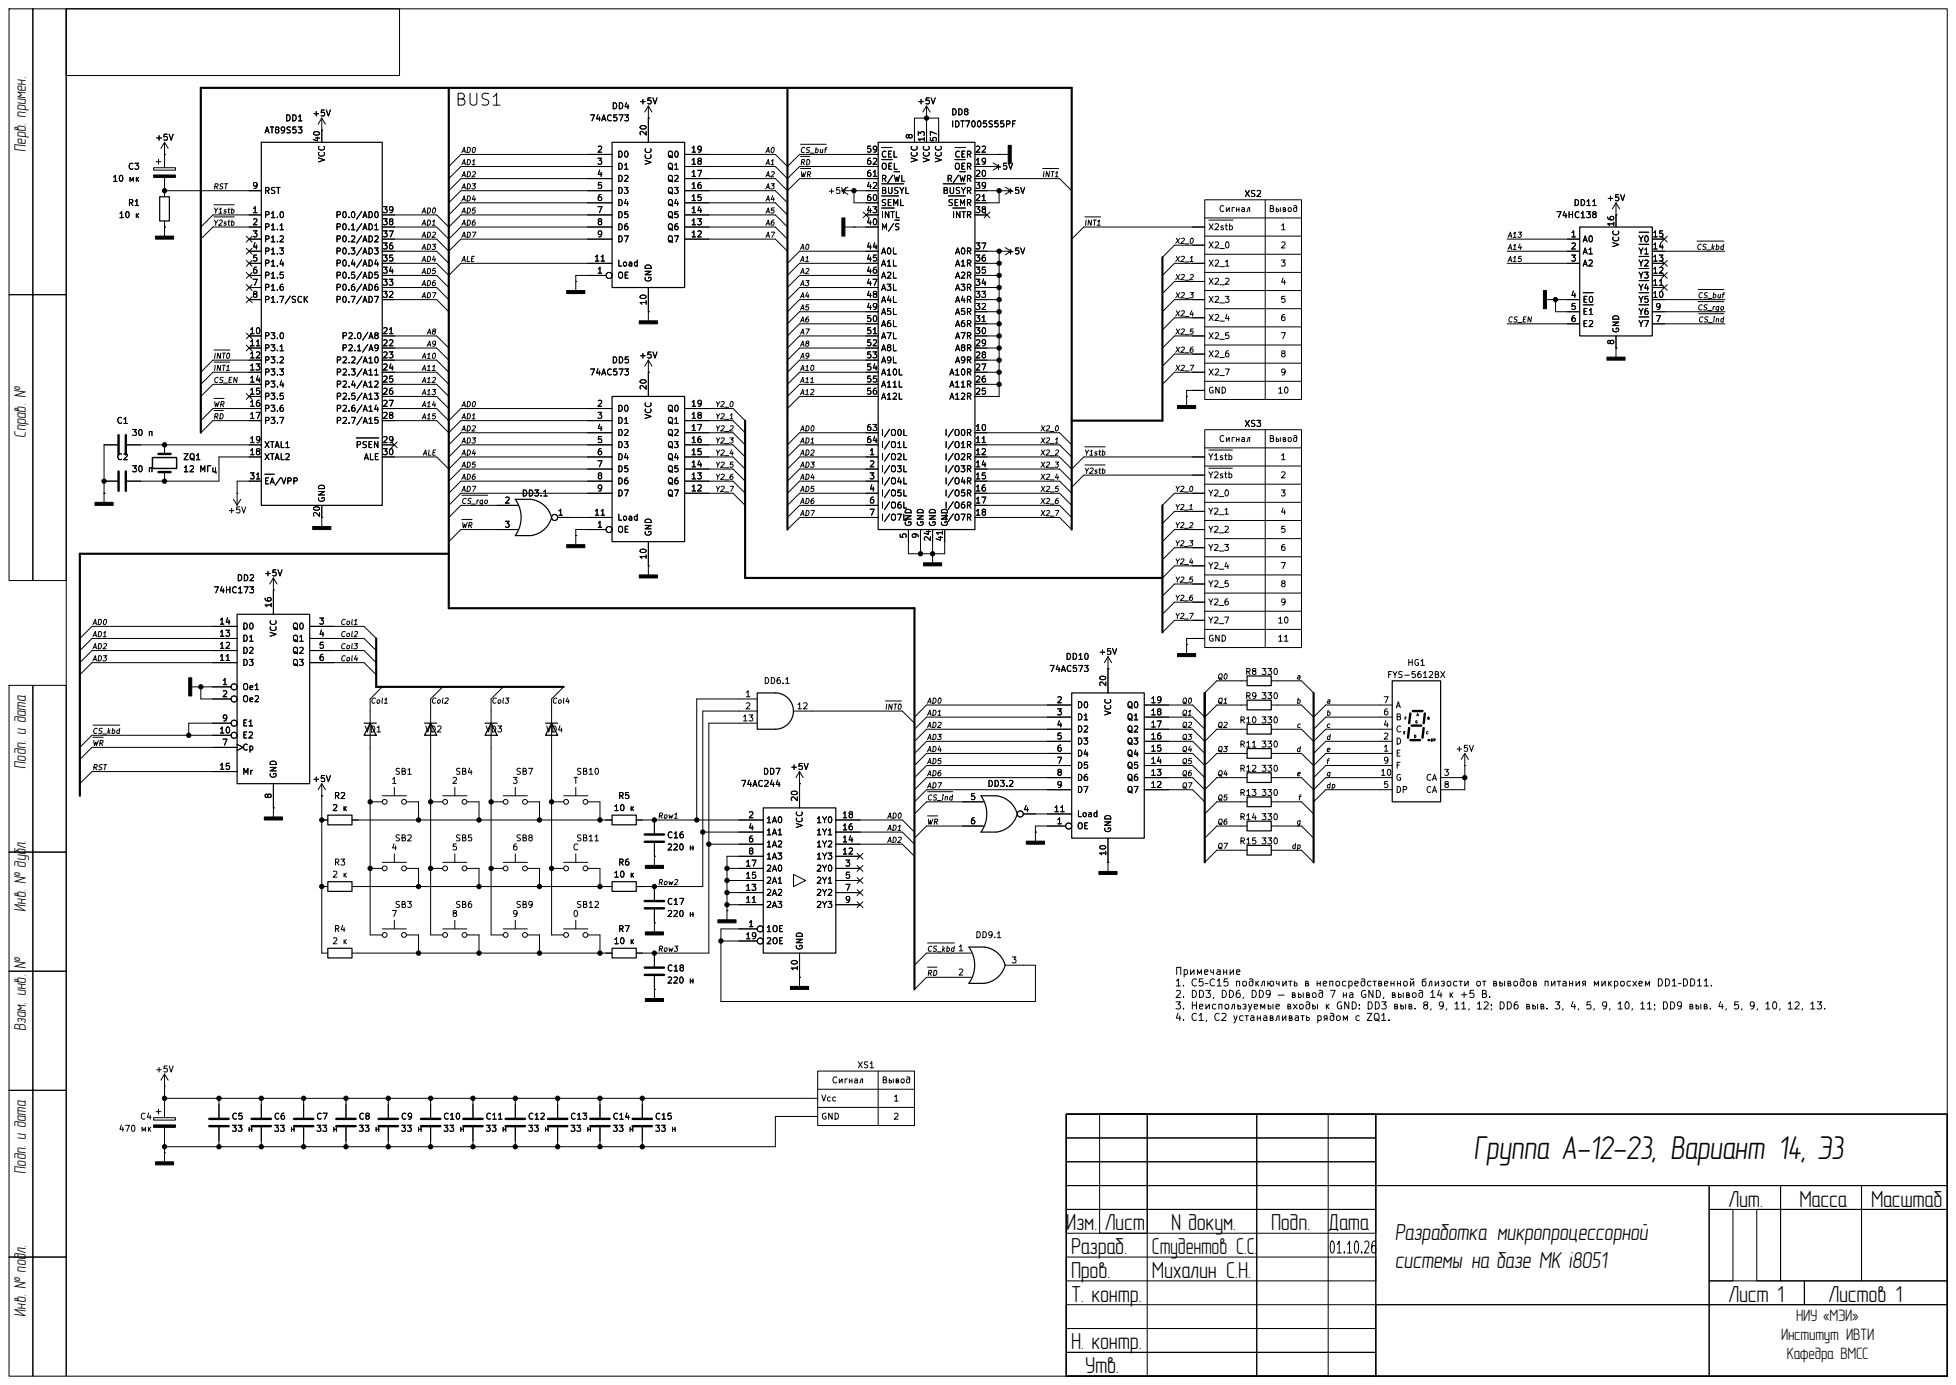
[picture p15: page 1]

A2 | | SEML 60 R/WL 61 OEL 62 | 21 CER 21 CER 20 20

Примечание
1. C5–C15 подключить в непосредственной близости от выводов питания микросхем DD1–DD11.
2. DD3, DD6, DD9 — вывод 7 на GND, вывод 14 к +5 В.
3. Неиспользуемые входы к GND: DD3 выв. 8, 9, 11, 12; DD6 выв. 3, 4, 5, 9, 10, 11; DD9 выв. 4, 5, 9, 10, 12, 13.
4. C1, C2 устанавливать рядом с ZQ1.

Группа А-12-23, Вариант 14, Э3 Инв. № подл. Подп. и дата Взам. инв.

Сигнал | Вывод 1

Vcc GND

Разработка микропроцессорной системы на базе МК i8051 | Лит. | Масса | Масштаб

Изм. Лист | N докум. | Подп. | Дата
Разраб. | Студентов С.С. | | 01.10.26
Пров. | Михалин С.Н.
Т. контр. | | | | Лист 1 | Листов 1

НИУ «МЭИ» Институт ИВТИ Кафедра ВМСС

Н. контр.
Утв.

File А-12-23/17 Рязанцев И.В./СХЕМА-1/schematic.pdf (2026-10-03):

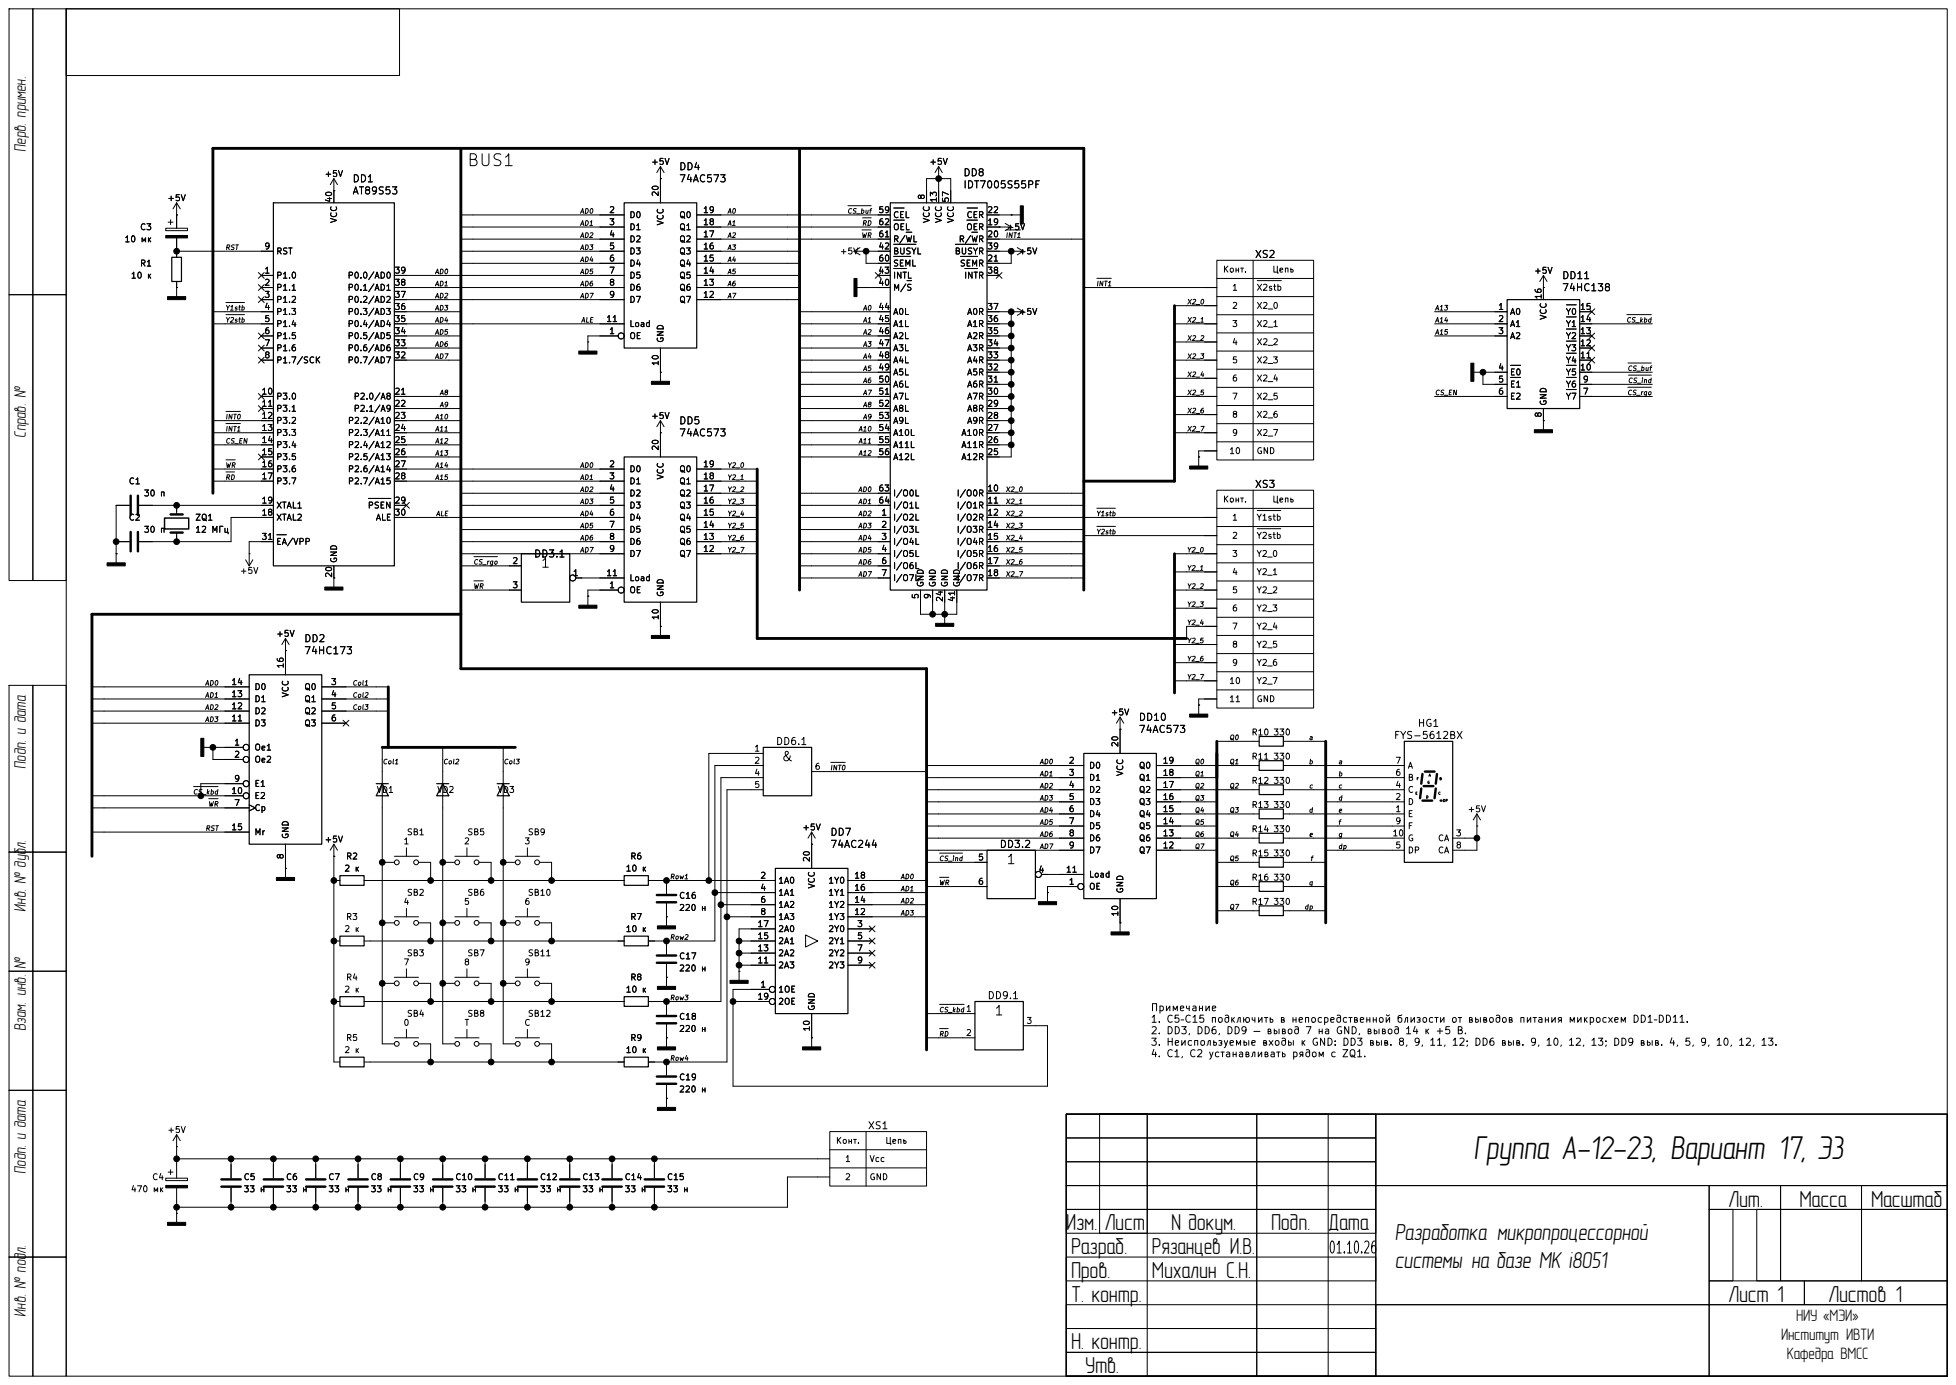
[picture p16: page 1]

№ Инв. № дубл. Подп. и дата Перв. примен. Справ.

6 5 5 CS_ind | DD3.2

Группа А-12-23, Вариант 17, Э3 Инв. № подл. Подп. и дата Взам. инв.

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

Vcc GNDЦепь

Разработка микропроцессорной системы на базе МК i8051 | Лит. | Масса | Масштаб

Изм. Лист | N докум. | Подп. | Дата
Разраб. | Рязанцев И.В. | | 01.10.26
Пров. | Михалин С.Н.
Т. контр. | | | | Лист 1 | Листов 1

НИУ «МЭИ» Институт ИВТИ Кафедра ВМСС

Н. контр.
Утв.

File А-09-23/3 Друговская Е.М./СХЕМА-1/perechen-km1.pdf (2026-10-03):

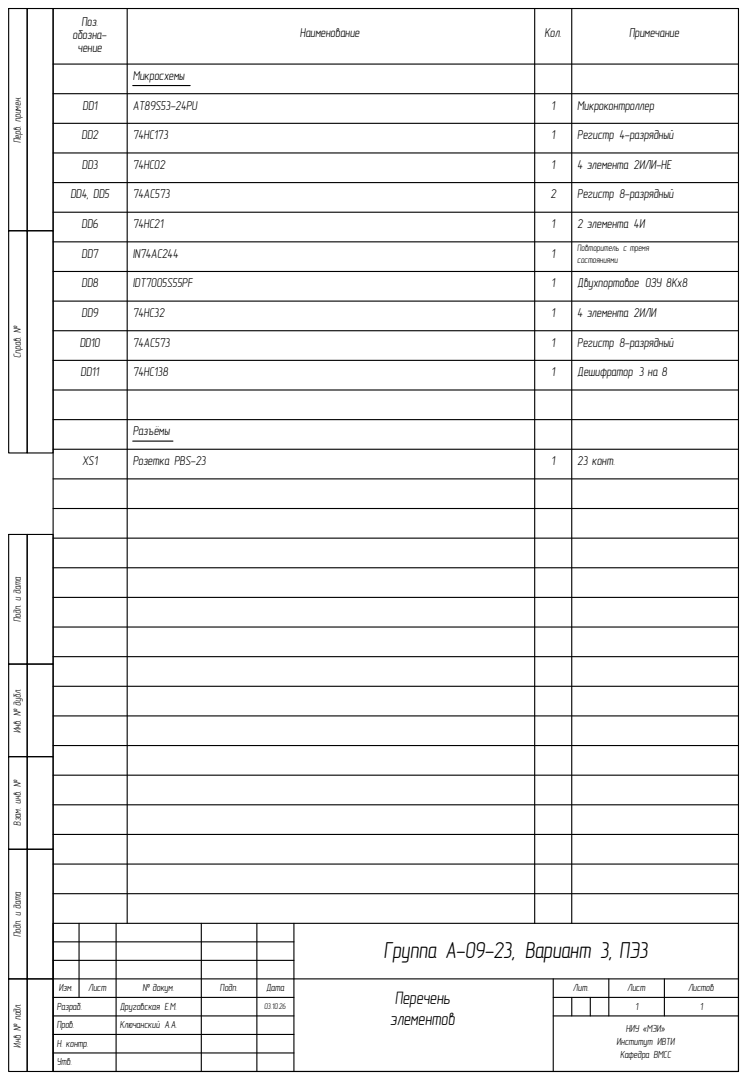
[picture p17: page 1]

Микросхемы

№ Инв. № дубл. Подп. и дата Перв. примен. Справ.

DD8 | IDT7005S55PF

Разъёмы

Розетка PBS-23

Кафедра ВМСС Инв. № подл. Подп. и дата Взам. инв.

Изм. | Лист | № докум. | Подп. | Дата | Перечень элементов | Лит. | Лист | Листов
Разраб. | Друговская Е.М. | | | | | | | 1 | 1
Пров. | | | | | НИУ «МЭИ» Институт ИВТИ
Н. контр.
Утв.

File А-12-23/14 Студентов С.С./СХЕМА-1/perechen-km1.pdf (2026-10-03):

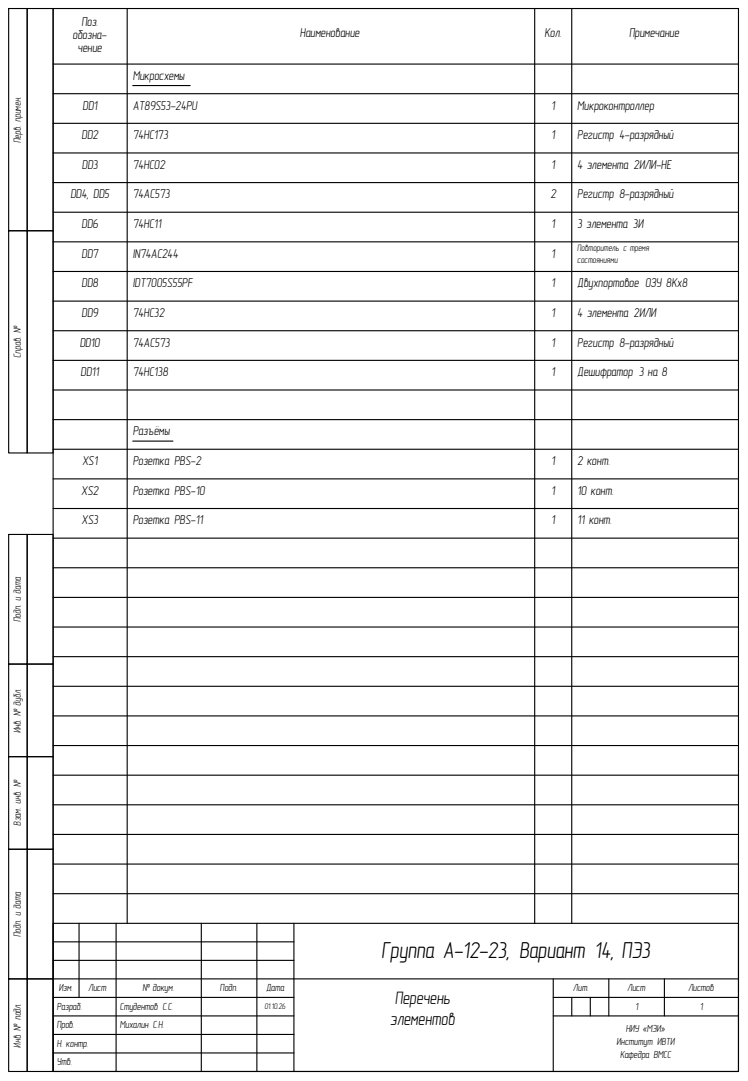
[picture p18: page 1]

Микросхемы

№ Инв. № дубл. Подп. и дата Перв. примен. Справ.

DD8 | IDT7005S55PF | 1

Разъёмы

Розетка PBS-10 | 1

Розетка PBS-11

Кафедра ВМСС Инв. № подл. Подп. и дата Взам. инв.

Изм. | Лист | № докум. | Подп. | Дата | Перечень элементов | Лит. | Лист | Листов
Разраб. | Студентов С.С. | | | | | | | 1 | 1
Пров. | | | | | НИУ «МЭИ» Институт ИВТИ
Н. контр.
Утв.

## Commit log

2026-10-03 results: 37146140950 (c77c38e)
    [schematic.kicad_sch]
2026-10-08 students/a06_groshev_av: из Issue #12
2026-10-08 students/ae21_sudbinin_na: из Issue #13
2026-10-09 Вторые замечания к КМ-1 (Михалин, Гольцов): буфер с независимым доступом, шины по ГОСТ, УГО
    Правый порт IDT7005 целиком на отдельном разъёме (адрес, данные, строб X2 → R/WR и INT1),
    левый — МК; номера линий у входов в шину, имена на проводниках; нумерация по центрам корпусов;
    ГОСТ-УГО (вентили, R/C, кнопки), без номиналов на листе; перечень; 3 круга самопроверки.
    Подробно — docs/changelog.md 2026-10-09/27.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
2026-10-09 Студенты: тексты ПЗ под новый буфер (ячейка обмена, ожидание конца строба X2); программы Друговской
2026-10-09 publish.sh: 12 повторов со случайной паузой при гонке за results; не опубликовали — запуск падает
2026-10-09 changelog /28, сессия: перезапуск всех и гонка за results
2026-10-10 students/a12_ivanov_da: из Issue #15
